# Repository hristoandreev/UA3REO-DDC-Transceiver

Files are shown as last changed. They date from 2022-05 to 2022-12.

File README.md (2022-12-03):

# Transceiver "Wolf"
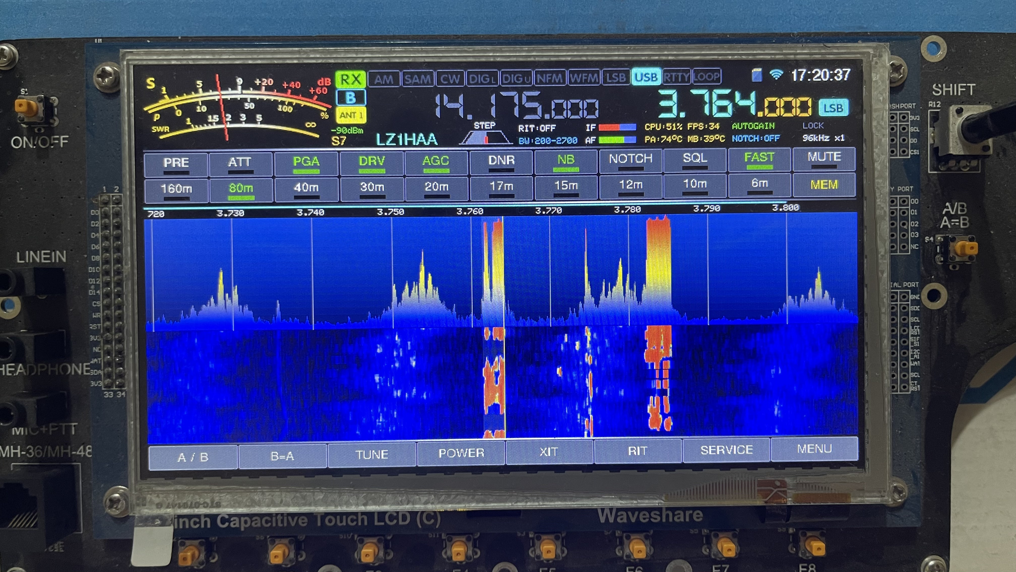
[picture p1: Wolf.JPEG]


DDC-DUC SDR Tranceiver project https://ua3reo.ru/tag/transiver-ua3reo/

* Community telegram channel: https://t.me/TRX_Wolf
* На русском https://github.com/XGudron/UA3REO-DDC-Transceiver/blob/master/README.ru-RU.md

## Principle of operation

The RF signal is digitized by a high-speed ADC chip and fed to an FPGA processor. <br>
It performs DDC / DUC conversion (digital frequency shift down or up the spectrum) - by analogy with a direct conversion receiver. <br>
The I and Q quadrature signals from the conversions are fed to the STM32 microprocessor. <br>
It filters, (de) modulates and outputs audio to an audio codec / USB. It also handles the entire user interface. <br>
When transmitting, the process occurs in the opposite order, only at the end of the chain there is a DAC, which converts the digital signal back to analog RF. <br>

## Specifications

* Receiving frequencies: 0 MHz - 750 MHz with fading each 61.44 Mhz
* Transmission frequencies: 0 MHz - 200 MHz with fading on 55, 110, 165 Mhz
* Transmission frequencies in harmonics mode (CW, FM): 360 Mhz - 480 Mhz
* TX power (QRP version): 7W+ (HF), 5W (VHF)
* TX power (QRP++ DB5AT version): 20W (HF), 7W (VHF)
* TX power (RU4PN/WF-100D version): 100W (HF), 50W+ (VHF)
* Two antenna inputs
* Modulation types (TX / RX): CW, LSB, USB, AM, FM, WFM, DIGI
* LNA, Preamplifier
* Adjustable attenuator 0-31dB
* Band pass filters
* ADC dynamic range (16 bit) ~100dB
* Supply voltage: 13.8V (overvoltage and polarity reversal protection)
* Consumption current when receiving: ~0.7А (3'2 QRP), 0.9A (7' BIG)
* Current consumption during transmission: ~2.5А+ (QRP), 15A+ (BIG)

## Transceiver Features

* Panorama (spectrum + waterfall) up to 384 kHz wide
* Panorama tweaks and themes
* Dual receiver (mixing A + B or A&B audio in stereo)
* Adjustable bandwidth: HPF from 0Hz to 2700Hz, LPF from 100Hz to 20kHz
* Integrated SWR/power meter (HF)
* Automatic and manual Notch filter
* Switchable AGC (AGC) with adjustable attack rate
* Range map, with the ability to automatically switch modes
* Digital Noise Reduction (DNR), Pulse Noise Reduction (NB)
* CAT virtual COM port (FT-450 / TS-2000 emulation, RTS - PTT, DTR - CW)
* USB operation (audio transmission, IQ, CAT, KEY, PTT)
* RDS/CW/RTTY decoder, self-control, gauss filter
* SWR Graphs
* Spectrum analyzer
* FT8 receiver/transmitter
* WSPR Beacon
* VOX
* Equalizer TX/RX, reverber
* SSB/FM Scanner mode
* Support SDHC/SDSC/SDXC memory cards up to 16Gb
* WAV files radio recording and playback, fast broadcast recorded CQ message
* AGC takes into account the characteristics of human hearing (K-Weighting)
* TCXO frequency stabilization (it is possible to use an external clock source, such as GPS)
* WiFi operation: Time synchronization, virtual CAT interface (see Scheme/WIFI-CAT-instruction.txt)
* Tangent support Yaesu MH-36 и MH-48
* Hardware self-testing
* Firmware update over USB, SD, WiFi
* And other.. (see menu)

### Sensitivity

At 10dB signal-to-noise ratio, LNA is on, ATT, LPF, BPF are off

Frequency, mHz | Sensitivity, dBm | Sensitivity
------------ | ------------- | -------------
<150	| -131	| 63.0 nV
435	| -121	| 0.2 uV

## Build

I ordered the boards in the Chinese service JLCPCB, they and their schemes are in the Scheme folder. <br>
After assembly, you need to flash FPGA and STM32 chips. <br>
If necessary, calibrate the transceiver through the appropriate menu <br>
WiFi module ESP-01 must have fresh firmware with SDK 3.0.4 and higher, and AT commands 1.7.4 and higher <br>

## Management

* **AF GAIN** - Volume
* **RIT / GAIN** - When the RIT function is active - smooth offset from the selected transceiver frequency. Inactive - IF gain control
* **ENC MAIN** - Main encoder for frequency control and menu settings
* **ENC 2** - Auxiliary encoder for menu operation. In normal mode, quickly switches the frequency, in CW fast change WPM
* **ENC 2[click]** - In CW mode, toggles between fast step and WPM selection, in other modes it opens the bandwidth properties.
* **BAND -** - Switch to the band below
* **BAND +** - Switch to higher band
* **MODE -** - Mode group switching SSB-> CW-> DIGI-> FM-> AM
* **MODE +** - Switching subgroup mod LSB-> USB, CW_L-> CW_U, DIGI_U-> DIGI_L, NFM-> WFM, AM-> IQ-> LOOP
* **FAST** - Mode of fast x10 rewinding of the frequency by the main encoder (configurable)
* **FAST [clamp]** - Frequency step settings
* **PRE** - Turn on the preamplifier (LNA)
* **PRE [clamp]** - Turn on the driver and / or amplifier ADC
* **ATT** - Turn on the attenuator
* **REC** - Save audio to SD card
* **PLAY** - Play recorded CQ-message from SD card
* **MUTE** - Mute the sound
* **MUTE [clamp]** - Scanner mode
* **AGC** - Turn on AGC (automatic gain control)
* **AGC [clamp]** - AGC settings
* **A = B** - Setting the second bank of the receiver equal to the current
* **BW** - Switch to bandwidth selection menu (LPF)
* **BW [clamp]** - Switch to bandwidth selection menu (HPF)
* **TUNE** - Turn on the carrier for tuning the antenna
* **RF POWER** - Transmitter power selection
* **RF POWER [clamp]** - Squelch setting
* **A / B** - Switches between VFO-A / VFO-B receiver settings banks
* **A / B [clamp]** - Enable automatic mode change by bendmap
* **DOUBLE** - Turn on the dual receiver
* **DOUBLE [clamp]** - Switching between the modes of the dual receiver A&B (each channel of the headphones has its own path) or A + B (mixing signals of 2 receivers)
* **DNR** - Enable digital noise reduction
* **DNR [clamp]** - Turn on the impulse noise suppressor (NB)
* **NOTCH** - Turn on the automatic Notch filter to eliminate narrowband interference
* **NOTCH [clamp]** - Turn on the manual Notch filter to eliminate narrowband interference
* **SPLIT** - Allows you to split transmission and reception to different VFO banks
* **RIT [clamp]** - Enables RIT control from the front panel
* **WPM** - Switch to key speed selection menu (WPM)
* **WPM [clamp]** - Automatic key enable
* **MENU** - Go to the menu
* **MENU [clamp]** - Enable key lock LOCK
* **MENU [at power on]** - Reset transceiver settings
* **MENU [at power on+PRE]** - Reset transceiver settings and calibration
* **RIT** - Offset of the receiving frequency relative to the current frequency (TX without offset)
* **XIT** - Offset of the transmission frequency relative to the current frequency (RX without offset)

## Settings

### TRX Settings

* **RF Power** - Transmission power,%
* **Power for each band** - Save power settings for each band individually
* **Power for each mode** - Save power settings for each mode individually
* **Channel Mode** - Channel frequency mode (for LPD/PMR and etc.)
* **Band Map** - Band Map, automatically switches mode depending on the frequency
* **AutoGainer** - Automatic ATT / PREAMP control depending on the signal level on the ADC
* **RF Filters** - Hardware filter management (LPF / HPF / BPF)
* **Two Signal tune** - Two-signal generator in TUNE mode (1 + 2kHz)
* **RIT Interval** - Offset range RIT (+ -)
* **XIT Interval** - Offset range XIT (+ -)
* **Fine RIT Tune** - Fine or coarse tuning for RIT/XIT (encoder or resistor)
* **TRX Samplerate** - Max FFT/samplerate on CW/SSB/NFM/DIGI/etc modes
* **FM Samplerate** - Max FFT/samplerate on NFM/WFM mode
* **Freq Step** - Frequency step by the main encoder
* **Freq Step FAST** - Frequency step by the main encoder in FAST mode
* **Freq Step ENC2** - Frequency tuning step by main add. encoder
* **Freq Step ENC2 FAST** - Frequency step by main add. encoder in FAST mode
* **Freq Step WFM, kHz** - Frequency step by main encoder in WFM mode
* **CW Freq Step divider** - Frequency step divider for CW mode
* **Encoder Accelerate** - Accelerate encoder on fast rates
* **Att step, dB** - Attenuator tuning step
* **Attenuation, dB** - Current attenuation
* **DEBUG Type** - Output of debug and service information to USB / UART ports
* **Auto Input Switch** - Auto input switch (PTT - mix, CAT - USB)
* **Auto Snap** - Automaticly track and snap to near signal frequency (CW mode)
* **Input Type** - Select audio input (microphone, line in, USB)
* **Callsign** - User callsign
* **Locator** - User QTH locator
* **URSI Code** - Ionogramm URSI Code https://digisonde.com/index.html#stationmap-section
* **TUNER Enabled** - Turning on the antenna tuner
* **ATU Enabled** - Turning on the automatic antenna tuner
* **ATU Ind** - Combination of tuner inductances
* **ATU Cap** - Tuner Capacitance Combination
* **ATU T** - Tuner capacitive arm position
* **Transverter XXcm** - Enable external ham band transverter support
* **Custom Transverter** - Enable external transverter on non-ham band (just offset display frequency)

### AUDIO Settings

* **Volume** - AF gain
* **Volume step** - AF gain step by ENC2 (X1, Lite)
* **IF Gain, dB** - IF gain
* **AGC Gain target, LKFS** - Maximum AGC gain (Maximum volume with AGC on)
* **Mic Gain** - Microphone gain
* **Mic Boost** - +20db hardware mic amplifier
* **DNR xxx** - Digital squelch adjustment
* **Noise Blanker** - Activating the Surge Suppressor
* **NB Threshold** - Threshold of Noise blanker
* **SSB HPF Pass** - HPF cutoff frequency when operating in SSB
* **SSB LPF Pass** - LPF cutoff frequency when operating in SSB
* **CW LPF Pass** - LPF cutoff frequency when working in CW
* **DIGI LPF Pass** - LPF cutoff frequency when working in DIGI
* **FM LPF Pass** - LPF cutoff frequency when working in FM
* **Squelch** - Enable SSB/AM/CW/FM Squelch
* **FM Squelch level** - FM squelch level
* **MIC EQ xxx** - Microphone equalizer levels
* **MIC Reverber** - Microphone reverberator level
* **MIC Noise Gate** - The level below which the microphone signal is muted, dbFS
* **RX EQ xxx** - Receiver equalizer levels
* **RX AGC Speed** - AGC (automatic signal level control) response speed for reception (more-faster)
* **RX AGC Max gain** - Limit of AGC gain, dB
* **RX AGC Hold time** - Time of AGC gain holding on signal peaks, ms
* **TX Compressor Speed** - TX compressor response speed for transmission (more-faster)
* **TX Compressor MaxGain** - Maximum comressor gain
* **Beeper** - Beep on key press
* **CTCSS Frequency** - Transmit FM CTCSS sub-tone frequency
* **SelfHear Volume** - Self Hearing (CW/DIGI) volume relative to the overall transceiver volume
* **WFM Stereo** - select WFM stereo or mono decoder
* **AGC Spectral** - Enable FFT-based AGC
* **TX CESSB** - Enable controlled-envelope single-sideband modulation
* **TX CESSB Compress, dB** - Level of signal compression in CESSB
* **VAD Threshold** - VAD voice detector threshold (noise suppressor for SSB mode and SCAN mode)
* **VOX** - TX Voice activation
* **VOX Timeout, ms** - VOX transmission delay after silence, milliseconds
* **VOX Threshold, dbFS** - VOX Threshold, dbFS

### CW Settings

* **CW Key timeout** - Time before stopping the transmission mode after releasing the key
* **CW Pitch** - Detuning the receive generator from the transmit frequency
* **CW Self Hear** - Self-control CW (key press is heard)
* **CW Keyer** - Automatic Key
* **CW Keyer WPM** - Key Speed, WPM
* **CW Gauss filter** - Gauss responce LPF filter
* **CW DotToDash Rate** - Keyer dash to dot length rate
* **CW Iambic Keyer** - Enable Iambic mode keyer
* **CW Key Invert** - Invert dash/dot on key
* **CW PTT Type** - RX/TX switch type for CW: by key or external PTT (tangent, etc.)

### SCREEN Settings

* **FFT Zoom** - FFT spectrum zooming
* **FFT Zoom CW** - FFT spectrum zooming for CW Mode
* **LCD Brightness** - Set LCD brightness (not all lcd support)
* **LCD Sleep Timeout** - Idle time before the screen brightness decreases, sec (0 - disabled)
* **Color Theme** - Select colors theme (0 - black, 1 - white, 2 - black with colored frequency)
* **Layout Theme** - Select interface theme (0 - default)
* **FFT Speed** - FFT and waterfall speed
* **FFT Automatic** - Automatic FFT scale
* **FFT Sensitivity** - Top threshold of FFT sensitivity in automatic mode (30 - scale to strongest signal)
* **FFT Manual Bottom, dBm** - Bottom FFT threshold in manual mode
* **FFT Manual Top, dBm** - Top FFT threshold in manual mode
* **FFT Height** - FFT and waterfall proportional height
* **FFT Style** - FFT style: 1(gradient), 2(fill), 3(dots), 4(contour)
* **FFT BW Style** - FFT bandwidth style: high opacity, low opacity, lines
* **FFT Color** - FFT colors: 1(blue -> yellow -> red), 2(black -> yellow -> red), 3(black -> yellow -> green), 4(black -> red), 5(black -> green), 6(black -> blue), 7(black -> white)
* **WTF Color** - Waterfall colors: 1(blue -> yellow -> red), 2(black -> yellow -> red), 3(black -> yellow -> green), 4(black -> red), 5(black -> green), 6(black -> blue), 7(black -> white)
* **FFT Freq Grid** - FFT and waterfall grids: 1(no grid), 2(fft grid), 3(fft+wtf grids), 4(wtf grid)
* **FFT dBm Grid** - FFT signal power grid
* **FFT Background** - Gradient FFT background
* **FFT Enabled** - Enable waterfall and FFT
* **WTF Moving** - Mowe waterfall with frequency changing
* **FFT Lens** - Enable FFT lens mode (magnify center of spectrum)
* **FFT Hold Peaks** - Show peaks on FFT spectrum
* **FFT 3D Mode** - Enable FFT 3D mode (0 - disabled, 1 - lines, 2 - pixels)
* **FFT Compressor** - Enable FFT peak comressor
* **FFT Averaging** - FFT burst averaging level
* **FFT Window** - Select FFT window (1-Dolph–Chebyshev 2-Blackman-Harris 3-Nutall 4-Blackman-Nutall 5-Hann 6-Hamming 7-No window)
* **FFT DXCluster** - Show DXCluster info over FFT
* **FFT DXCluster Azimuth** - Add azimuth data to DX-cluster
* **FFT DXCluster Timeout** - Timeout of DX-cluser spots in minutes
* **Show Sec VFO** - Show secondary VFO position on spectre
* **FFT Scale Type** - Y-axis style on FFT between signal amplitude and dBm to fit more dynamic range on screen (Useful when manually adjusting FFT range).

### Decoders
* **CW Decoder** - Software CW receive decoder
* **CW Decoder Threshold** - CW receive decoder sensivity
* **RDS Decoder** - Enable RDS Decoder for WFM mode
* **RTTY Speed** - Speed of RTTY data
* **RTTY Shift** - RTTY carrier shifts
* **RTTY Freq** - Central frequency of RTTY decoding
* **RTTY StopBits** - RTTY Stop bits
* **RTTY InvertBits** - RTTY invert 0 and 1 bits

### ADC / DAC Settings

* **ADC Driver** - Turn on the preamplifier-ADC driver
* **ADC Preamp** - Turn on the preamplifier built into the ADC
* **ADC Dither** - Enable ADC dither for receiving weak signals
* **ADC Randomizer** - Enables ADC digital line encryption
* **ADC Shutdown** - Turn off the ADC

### WIFI Settings

* **WIFI Enabled** - Enable WiFi module (need restart after enable)
* **WIFI Network** - WiFi hotspot selection
* **WIFI Network Pass** - Set password for WiFi hotspot
* **WIFI Timezone** - Time zone (for updating the time via the Internet)
* **WIFI CAT Server** - Server for receiving CAT commands via WIFI
* **WIFI Update ESP firmware** - Start cloud autoupdate firmware for ESP-01 (if present)

### SD Card

* **File Manager** - Show SD Card file manager, support WAV playback and deleteing files, listening and broadcasting recordings, as well as updating firmware from a memory card
* **USB SD Card Reader** - Enable USB SD Card reader
* **Export Settings** - Export settings and calibration data to SD card
* **Import Settings** - Import settings and calibration data from SD card
* **Format SD card** - Format media drive

### Calibration [appears by long pressing the MENU button in the settings menu]

* **Encoder invert** - Invert the rotation of the main encoder
* **Encoder2 invert** - Invert the rotation of the additional encoder
* **Encoder debounce** - Time of debouncing contacts of the main encoder
* **Encoder2 debounce** - Time of debouncing contacts of the additional encoder
* **Encoder slow rate** - Deceleration rate of the main encoder
* **Encoder on falling** - The encoder is triggered only when level A falls
* **Encoder acceleration** - The encoder acceleration on faster rotation speeds
* **RF-Unit Type** - RF-Unit Type (QRP / BIG)
* **Tangent Type** - Select tangent type
* **CICCOMP Shift** - Bit shift after CIC compensator
* **TX CICCOMP Shift** - Bit shift after TX CIC compensator
* **DAC Shift** - Bit shift of the output to the DAC
* **DAC Driver Mode** - DAC Driver OPA2673 bias mode (2 = 100% bias, 1 = 75% bias, 0 = 50% bias)
* **RF GAIN xxx** - Calibration of the maximum output power for each range. RF GAIN 0-100% - 50% driver bias, 101-200% - 75% driver bias, 201-300% - 100% driver bias.
* **S METER** - S-meter calibration
* **ADC OFFSET** - ADC offset calibration
* **LPF END** - LPF filter parameters
* **HPF START** - HPF filter parameters
* **BPF x** - Bandpass filter parameters
* **SWR FWD/BWD RATE** - Adjustment of the transformation ratio of the SWR meter (forward / return)
* **VCXO Correction** - Frequency adjustment of the reference oscillator
* **FAN Medium start** - Temperature of the PA for starting the fan at medium speed
* **FAN Medium stop** - Temperature of the PA for stopping the fan
* **FAN Full start** - Temperature of the PA for starting the fan at full speed
* **MAX RF Temp** - Maximum temperature of the PA before the protection operation
* **MAX SWR** - Maximum VSWR before protection operation
* **SSB Power addition** - Addition of RF power in SSB power, %
* **FM Deviation Scale** - Set TX FM Deviation Scale
* **AM Modulation Index** - Set TX AM Modulation Scale
* **MAX PWR on Meter** - Maximim RF power (for indication)
* **MAX Power in TUNE** - Maximum RF power in Tune mode
* **RTC COARSE CALIBR** - Very coarse clock crystal calibration
* **RTC FINE CALIBR** - Clock crystal calibration, one division is 0.954 ppm
* **EXT xxx** - External port control by band (EXT3, EXT2, EXT1, EXT0) - open drain
* **NOTX xxx** - Disable TX on selected bands
* **ENABLE 60m/4m/AIR/Marine Band** - Enable hidden bands
* **Transverter Offset, mHz** - Offset frequency shown on the display (for custom transverters)
* **Transverter xxx RF, mHz** - Setting the RF frequency of the transceiver to match the IF
* **Transverter xxx IF, mHz** - Setting the IF frequency of the transverter
* **OTA Update** - Enable OTA firmware update over WiFi
* **TX Start Delay** - Delay before the RF signal is applied (ms), so that the relay has time to trigger
* **LCD Rotate** - Rotate screen at 180 degrees
* **TOUCHPAD horiz flip** - Flip touchpad operation horizontally
* **ATU Averaging** - The number of steps of averaging SWR values during measurements in the operation of an automatic tuner
* **CAT Type** - Type of CAT subsystem (FT-450 / TS-2000)
* **LNA Compensation** - Compensates the S-meter value when the LNA is turned on, dBm
* **TSignal Balance** - Sets the power balance between signals in Two signal tune mode
* **Linear Pwr Control** - Sets a linear way to change the signal amplitude when adjusting the power (if disabled - logarithmic)
* **Flash GT911** - Starting the touchpad update procedure according to LCD screen resolution
* **IF Gain MIN/MAX** - IF Gain adjusting limits
* **Settings reset** - Reset all settings to defaults
* **Calibrate reset** - Reset all calibrations to defaults

### Set Clock Time

* Clock setting

### DFU Mode

* Launch STM32 USB firmware update over DFU mode

### OTA Update

* Launch FPGA/STM32 firmware update over internet

### System info

* Show info about TRX

## Services

### Spectrum Analyzer

* **Spectrum START** - Start the spectrum analyzer
* **Begin, kHz** - Starting frequency of the analyzer with a step of 1 kHz
* **End, kHz** - End frequency of the analyzer in 1kHz steps
* **Top, dBm** - Upper threshold of the graph
* **Bottom, dBm** - Lower threshold of the graph

### WSPR Beacon

* **WSPR Beacon START** - Start WSPR beacon
* **Freq offset** - Offset from center of WSPR band
* **WSPR Band xxx** - Select bands to WSPR beacon

### DX Cluster 

* Show DX Cluster info by current band (from internet)

### Propagination 

* Show propagination statistics (from internet)

### DayNight Map 

* Displaying the day/night terminator on the map (from internet)

### Ionogram 

* Displaying the ionogram for the selected URSI Code (from internet)

### SWR Analyser

* Run SWR analizer (Band SWR - on current band, HF SWR - on all HF bands, Custom SWR - in selected range)

### RDA Statistics 

* Print statistics from RDA award (from internet)

### Record CQ message

* Record a short message for quick broadcast

### FT8

* FT8 Receiver / transmitter

### Locator Info

* Calculate distance and azimuth from QTH-locator

### Callsign Info

* Show callsign data

### Self Test

* Run hardware self diagnostic

### Auto calibration

* **Calibrate SWR** - Assistant in measuring SWR and power meter
* **Calibrate Power** - Assistant in adjusting RF Power output

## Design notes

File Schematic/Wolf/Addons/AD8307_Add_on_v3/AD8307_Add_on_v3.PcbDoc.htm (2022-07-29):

Altium Reporting Options

# File in Newer Format

Date | : | 04-Dec-20
Time | : | 18:56:06
Filename | : | C:\Tisho\MyProjects\SDR_Transciever\UA3REO-DDC\Tisho_Files\Boards\AD8307_Add_on_v2\AD8307_Add_on_v2.PcbDoc

Version | Warning
Release 10 | CAUTION - New Custom Grids and Guides were introduced. Be aware that your design might contain Custom Grids and Guides that cannot be read in previous versions.
Release 10 | CAUTION - New Structured Clusters were introduced. Be aware that your design might contain Structured Clusters that cannot be read in previous versions.
Release 10 | CAUTION - New PCB 3D Movie Manager was introduced. Be aware that your design might contain 3D PCB movie that cannot be read in previous versions.
Release 10 update 1 | CAUTION - New Clearance Rule subscopes targeting differential pairs were introduced. Be aware that your design might contain Clearance Rules using those subscopes that cannot be read in previous versions.
Release 10 update 15 | CAUTION - Support of Solder Mask and Paste Mask expansions for Tracks, Arcs, Fills and Regions was introduced. Be aware that your design might contain Solder Mask and Paste Mask expansions for these types of primitives that cannot be read in the version of Altium Designer you are currently using.
Release 12 | CAUTION - Air Gap Width previously controlled by Clearance rule is now controlled by Polygon Connect Style rule's newly introduced Air Gap Width (set to default value). Suggest reviewing each Polygon Connect Style rule's Air Gap Width attribute for correctness.
Release 13 | CAUTION - Silk To Solder Mask Clearance Rules are converted to Silkscreen Over Component Pads Rules.
Release 14 | CAUTION - The Differential Pairs Routing rule added support for control of the width. Be aware that these widths must be manually entered as Width rules in this version.
Release 15 | CAUTION - Support of separate solder masks for top & bottom of pads added.
Release 15.1 | CAUTION - Support Multi-line PCB Text added.
Release 16.0 | CAUTION - Pad/Via hole size tolerance value added.
Release 17.0 | CAUTION - Component parameters added.
Release 17.0 | CAUTION - Support of backdrilling
Release 17.1 | CAUTION - Support of waived violations
Release 17.1 | CAUTION - Support of object specific keepouts

This file was generated by a later version of the software

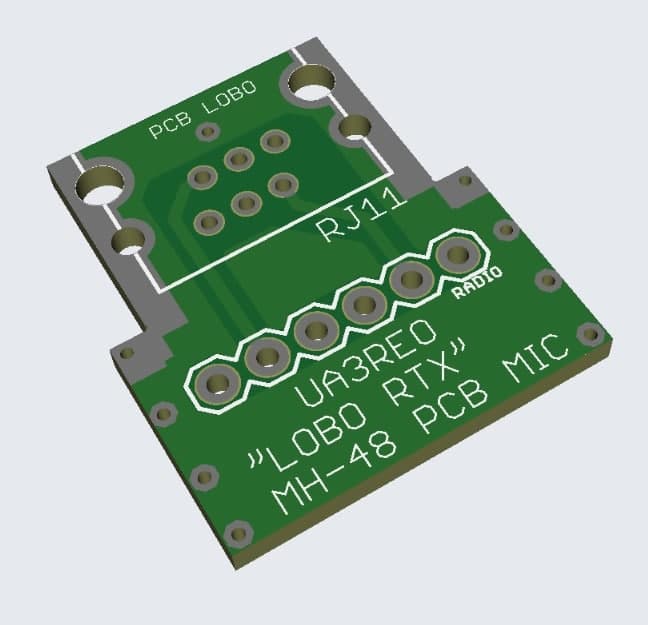
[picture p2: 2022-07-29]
Schematic/Wolf/Addons/PCB MIC MH-48/pcb2.jpg

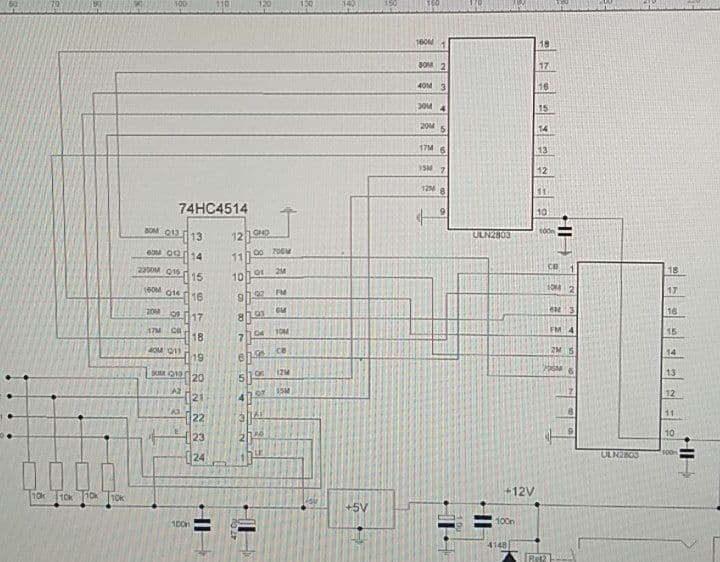
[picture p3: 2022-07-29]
Schematic/Wolf/Addons/LPF_switch.jpg

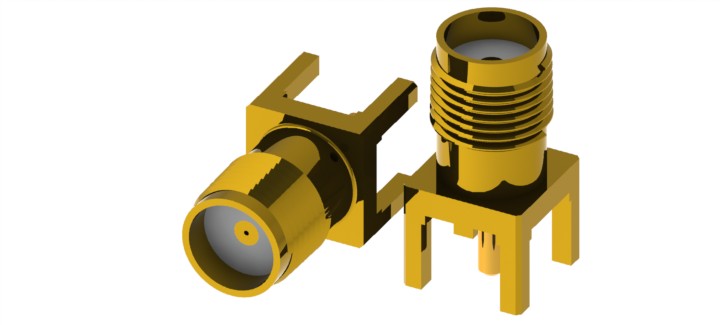
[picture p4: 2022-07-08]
Schematic/Wolf/Altium_Designer/Mod-LZ1HAA-hardware/MOTHERBOARD/3d/conn-jack-sma-str-molex-73391-0060-rf-slash-coaxial/Renderings/Molex - 73391-0060.JPG

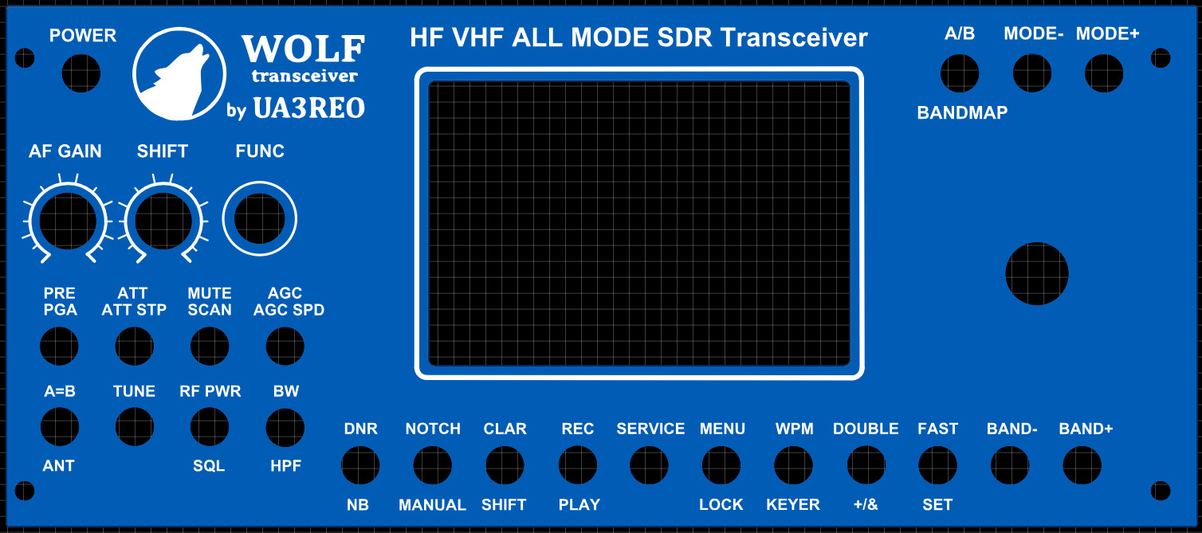
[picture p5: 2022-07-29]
Schematic/Wolf/CASE/3'2/FrontPanel/image.jpg

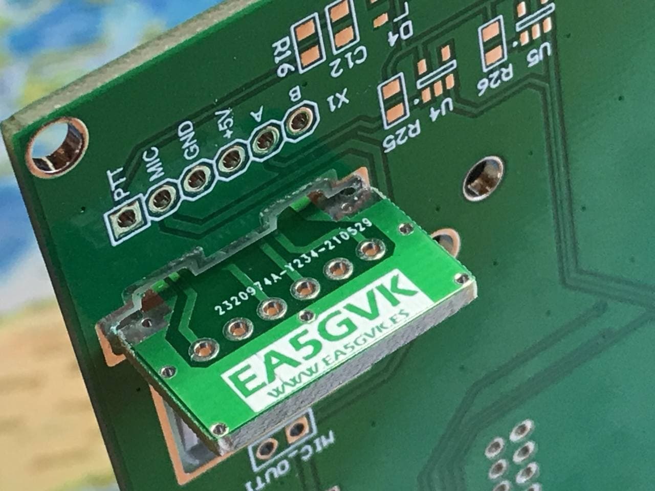
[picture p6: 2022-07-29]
Schematic/Wolf/Addons/PCB MIC MH-48/pcb5.jpg

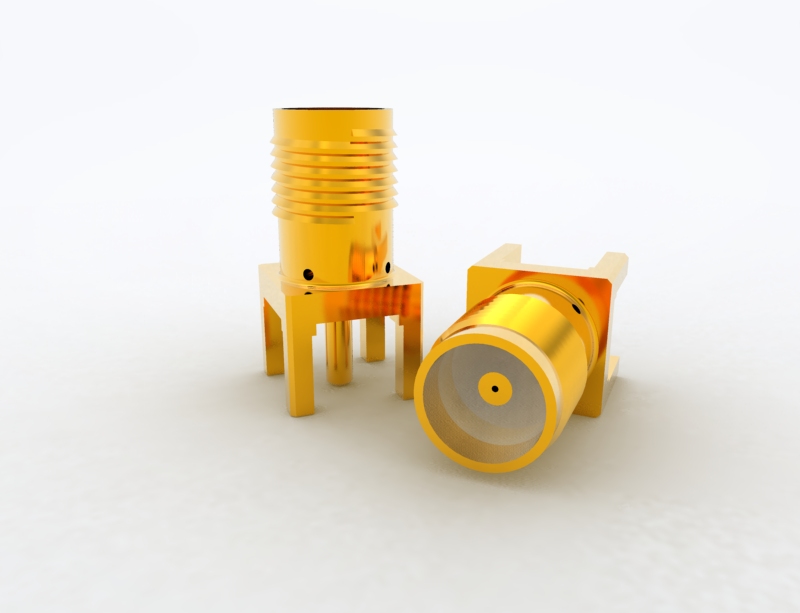
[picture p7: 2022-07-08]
Schematic/Wolf/Altium_Designer/Mod-LZ1HAA-hardware/MOTHERBOARD/3d/conn-jack-sma-str-molex-73391-0060-rf-slash-coaxial/Renderings/untitled.32220110907-27564-a875go.jpg

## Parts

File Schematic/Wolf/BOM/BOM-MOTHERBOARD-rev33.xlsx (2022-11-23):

Comment | Description | Designator | Footprint | LibRef | Quantity | LCSC Part #
JX2 | JX2 | 13.8V + | JX2 | JX2 | 1
51022-0300_1 | 51022-0300 | A_OUT, MIC_IN2 | 51022-0200 - duplicate | 51022-0300_1 | 2
CR1220 + | BR1632A/FA | B1 | KLS5-CR1220-01 | BR1632A/FA | 1
 | 2 Pin | BOOT | 51022-0200 | 51022-0200 | 1
4.7uF 16V | CAPAE_6.6x6.6h5.4 | C1 | SMC | CAPAE_6.6x6.6h5.4 | 1
22uF 10V | CAPAE_4.3x4.3h5.4 | C2, C125, C126 | CAPAE_4.3x4.3h5.4 | CAPAE_4.3x4.3h5.4 | 3
100n | CAP_0805 | C3, C4, C5, C6, C9, C16, C19, C21, C23, C31, C44, C45, C46, C47, C48, C49, C51, C53, C56, C57, C58, C59, C61, C62, C65, C67, C69, C70, C71, C72, C73, C74, C76, C78, C79, C81, C82, C83, C84, C86, C87, C88, C89, C91, C93, C94, C95, C96, C97, C98, C99, C100, C107, C109, C110, C112, C113, C114, C115, C117, C118, C120, C123, C124, C135 | CAP_0805 | CAP_0805 | 65
1uF | CAP_0805 | C7, C11, C12, C13, C14, C15, C35, C92, C119, C121, C122, C1003, C1004 | CAP_0805 | CAP_0805 | 13
10uF 10V | CAPAE_4.3x4.3h5.4 | C8, C20, C22, C24, C32, C54, C60, C75, C77, C80, C85, C1002 | CAPAE_4.3x4.3h5.4 | CAPAE_4.3x4.3h5.4 | 12
470p | CAP_0805 | C10, C90, C104, C116 | CAP_0805 | CAP_0805 | 4
10uF 10V | CAP_0805 | C17 | CAP_0805 | CAP_0805 | 1
1uF 10V | CAPAE_4.3x4.3h5.4 | C25, C26, C29 | CAPAE_4.3x4.3h5.4 | CAPAE_4.3x4.3h5.4 | 3
220p | CAP_0805 | C27, C28, C30 | CAP_0805 | CAP_0805 | 3
220uF 10V | CAPAE_4.3x4.3h5.4 | C33, C34 | EEEFC_size� | CAPAE_4.3x4.3h5.4 | 2
NONE | CAP_0805 | C36 | CAP_0805 | CAP_0805 | 1
2.7n | CAP_0805 | C37 | CAP_0805 | CAP_0805 | 1
6pF | CAP_0805 | C38, C39 | CAP_0805 | CAP_0805 | 2
10uF | CAP_0805 | C40, C41, C50, C52, C64, C66, C68 | CAP_0805 | CAP_0805 | 7
22p | CAP_0805 | C42, C43 | CAP_0805 | CAP_0805 | 2
7.5p | CAP_0805 | C55 | CAP_0805 | CAP_0805 | 1
10n | CAP_0805 | C63, C137 | CAP_0805 | CAP_0805 | 2
10uF 20V | CAPAE_4.3x4.3h5.4 | C101, C108 | CAPAE_4.3x4.3h5.4 | CAPAE_4.3x4.3h5.4 | 2
1uF | CAP_1206 | C102, C103 | CAP_1206 | CAP_1206 | 2
680p | CAP_1206 | C105, C106 | CAP_1206 | CAP_1206 | 2
10p | CAP_0805 | C127 | CAP_0805 | CAP_0805 | 1
8.2n | CAP_0805 | C136 | CAP_0805 | CAP_0805 | 1
1n | CAP_0805 | C1001 | CAP_0805 | CAP_0805 | 1
SMAJ5.0A-TR | Diode | D1, D3, D29, D30, D31, D34, D35, D36, D37, D38, D39, D40 | SMBJ36CATR | SMLVT3V3 | 12 | [NoParam], test
SS34 | Schottky Diode | D1001 | SMB | D Schottky | 1
Diode | Default Diode | D1002 | C1206 | Diode | 1
SJ1-3525NG | SJ1-3525NG | J1, J2, J3, J5 | SJ1-3525NG | SJ1-3523N | 4
RF-UNIT | 2*5 Pin | J4 | 90131-0126 | 90131-0126 | 1
FPC-45P-0.5mm | Connector | J6 | FH12S45S05SH60 | FH12S-45S-0.5SH_55_ | 1
FAN | 51022-0200 | J7 | 51022-0200 | 51022-0200 | 1
USB | 2-1734035-3 | J8 | 2-1734035-3 | 2-1734035-3 | 1
DAC_OUT | SMA | J9 | 31-5431 | 31-5431 | 1
ADC | SMA | J10 | 31-5431 | 31-5431 | 1
 | 2*5 Pin | JTAG_FPGA, JTAG_STM32 | IDC10 | IDC10 | 2
3.3uH | IND_1812 | L1, L9 | IND_1812 | IND_1812 | 2
BLM21 | BLM21 | L3, L8 | CAP_0805 | IND_FERRITE_BEAD | 2
22uH | IND_1206 | L7 | IND_7x7 | IND_1206 | 1
10uH | Inductor | L37, L1001 | IND_7x7 | IND_FERRITE_CORE | 2
10uH | IND_1812 | L1002 | IND_1812 | IND_1812 | 1
PTT_IN | 51022-0200 | PTT_IN | 51022-0200 | 51022-0200 | 1
2SC5103TLP | Transistor BJT NPN | Q1 | 2SC5103TLQ | 2SC5103TLP | 1
7.5k | RES_0805 | R1 | RES_0805 | RES_0805 | 1
39k | RES_0805 | R2 | RES_0805 | RES_0805 | 1
0/NONE | By used crystal | R3 | RES_0805 | RES_0805 | 1
NONE / 0 | RES_0805 | R4, R1001, R1002 | RES_0805 | RES_0805 | 3
5.6k | RES_0805 | R5, R6, R7, R9, R51 | RES_0805 | RES_0805 | 5
30k | RES_0805 | R8, R55 | RES_0805 | RES_0805 | 2
10k | RES_0805 | R10, R13, R24, R27, R28, R30, R31, R32, R33, R36, R37, R38, R39, R46, R47, R48, R56, R57 | RES_0805 | RES_0805 | 18
680 | RES_0805 | R11 | RES_0805 | RES_0805 | 1
47k | RES_0805 | R12, R14, R15, R45 | RES_0805 | RES_0805 | 4
1.5k | RES_0805 | R16, R66 | RES_0805 | RES_0805 | 2
1k | RES_0805 | R17, R18, R19, R25, R26, R49, R50, R52 | RES_0805 | RES_0805 | 8
130 | RES_0805 | R20, R21 | RES_0805 | RES_0805 | 2
82 | RES_0805 | R22, R23 | RES_0805 | RES_0805 | 2
1m | RES_0805 | R29 | RES_0805 | RES_0805 | 1
100 | RES_0805 | R34, R35 | RES_0805 | RES_0805 | 2
22 | RES_0805 | R40, R53, R54, R58 | RES_0805 | RES_0805 | 4
24 | RES_0805 | R41, R42, R43, R64, R65 | RES_0805 | RES_0805 | 5
56 | RES_0805 | R44, R67 | RES_0805 | RES_0805 | 2
 | RES_0805 | R59, R60 | RES_0805 | RES_0805 | 2
330 | RES_0805 | R61 | RES_0805 | RES_0805 | 1
5.6 | RES_1206 | R62, R63 | RES_1206 | RES_1206 | 2
10 | RES_0603 | R68, R69 | RES_0603 | RES_0603 | 2
Thermistor 20k | Thermistor | R70 | MF52A103F3950A1 | MF52A103F3950_A1_ | 1
ADJ-5k | 306J | R71 | 306J | 306J | 1
0 | RES_0805 | R1003 | RES_0805 | RES_0805 | 1
1:1+1 | Transformer | T3 | TRANSF_ACORE2 | TRANSF_ACORE2 | 1
1:4 ADT4-6T | Transformer | T4 | TRANSF_ACORE2 | TRANSF_ACORE2 | 1
1:1 | Transformer | T6 | TRANSF_ACORE | TRANSF_ACORE | 1
PAM8406 | PAM8406 | U1 | PAM8403 | PAM8406 | 1
LD3985 | LD3985 | U2 | LD3985 | LD3985 | 1
ST1S10 | ST1S10 | U3 | ST1S10 | ST1S10 | 1
WM8731 | WM8731 | U4 | WM8731 | WM8731 | 1
STM32H743VIT6-rev.V | STM32H743VIT6 | U5 | STM32H743VIT6 | STM32H743VIT6 | 1
LM1084IS-3.3 | LM1084IS-3.3 | U6 | LM1085-3.3 | LM1085-3.3 | 1
W25Q16 | W25Q16 | U7 | W25Q16 | W25Q16 | 1
DAC5674 | Integrated Circuit | U8 | QFP50P900X900X100-49N | DAC5674IPHP | 1
25P80 | 25P80 | U9 | 25P80 | 25P80 | 1
EP4CE22E22C8N | EP4CE22E22C8N | U10 | QFP144-20-2222A | EP4CE22E22C8N | 1
1117DT-2.5 | LD1117DT-2.5 DPAK | U11 | TO228P991X238-3N | LM1117DT-ADJ | 1
1117DT-1.2 | LD1117DT-1.2 DPAK | U12 | TO228P991X238-3N | LM1117DT-ADJ | 1
1117-3.3 | LT1117CST-3.3 | U13 | LT1117CST-3.3 | LT1117CST-3.3 | 1
1117-1.8 | LT1117CST-1.8 | U14 | LT1117CST-3.3 | LT1117CST-3.3 | 1
SPEAKER | 4 pins conn | U15 | speaker conn | speaker conn | 1
LTC2208CUP | LTC2208CUP | U16 | LTC2208CUP | LTC2208CUP | 1
LTC6400IUD | Single Channel, Low Noise, Low Distortion Differential ADC Driver for 300 MHz IF, 1800 MHz Typical GBW, 4500 V/us Typical SR, 2.85 to 3.5 V, 16-Pin QFN (UD-16), Industrial, Pb-Free | U17 | LT-UD-16_N | CMP-0359-03855-2 | 1
1117DT-3.3 | LD1117DT33 DPAK | U18 | TO228P991X238-3N | LM1117DT-ADJ | 1
ADUM4160 | Integrated Circuit | U19 | SOIC127P1032X265-16N | ADUM4160BRWZ | 1
OPA2673 | Integrated Circuit | U20 | QFN65P400X400X100-17N-D | OPA2673IRGVT | 1
LM2940S-12/NOPB | 1-A, 26-V, high-PSRR, low-dropout voltage regulator | U21 | TO254P1524X483-4N | LM2940S-12/NOPB | 1
122.88Mhz | NV7050SA VG-4513CA-122.8800M-GGCT3 | XG1 | NV7050SA | NV7050SA | 1
12.288Mhz TCXO 3.3v TTL/CMOS (set other freq in fpga code) | Crystal or Oscillator | XG2 | 581L200X2ITT | 581L200X2ITT | 1
ABS25-32.768KHZ-6-T | Crystal or Oscillator | Y1 | ABS25 | ABS25-32.768KHZ-6-T | 1
8mhz | ECS-200-20-1 | Y2 | ECS-200-20-1 | ECS-200-20-1 | 1

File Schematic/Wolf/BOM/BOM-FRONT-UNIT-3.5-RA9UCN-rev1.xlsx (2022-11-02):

Comment | Description | Designator | Footprint | LibRef | Quantity
JX2 | JX2 | ACCUM, IN, MOTHERBOARD, RF-UNIT | JX2 | JX2 | 4
100n | CAP_0805 | C1, C2, C9, C14, C15, C16, C17, C18, C19, C20, C21, C22, C23, C24, C25, C26 | CAP_0805 | CAP_0805 | 16
1uF | CAP_1206 | C3 | CAP_1206 | CAP_1206 | 1
100n | CAP_1206 | C4 | CAP_1206 | CAP_1206 | 1
1n | CAP_1206 | C5 | CAP_1206 | CAP_1206 | 1
1000uF | CAP250RP | C6 | CAP250RP | CAP250RP | 1
470pF | CAP_1206 | C7 | CAP_1206 | CAP_1206 | 1
120pF | CAP_1206 | C8 | CAP_1206 | CAP_1206 | 1
22uF | EEEFC_sizeB | C10 | EEEFC_sizeB | EEEFC_sizeB | 1
8.2n | CAP_1206 | C11 | CAPC2013X94X50LL20T25 | CMP-2007-04444-1 | 1
10n | CAP_0805 | C12, C13 | CAP_0805 | CAP_0805 | 2
470uF | 10x7.7, 8.7, 10, 10.5, 12.5 | C1001, C1002 | SMD-G-10X10.2 | _SMD-G-10 | 2
1n4148w | Diode | D25, D27 | SOD3716X135N | 1n4148w | 2
SM6T15A | Diode | D28 | SMBJ36CATR | SM6T15A | 1
PEC12 | PEC12 | ENC2 | PEC12 | PEC12 | 1
OPTICAL ENCODER | OPTICAL ENCODER | ENCODER_MAIN | 644456-4 | 644456-4 | 1
ESP-01 ESP8266 | ESP-01 ESP8266 | ESP-8266 | ESP-01 ESP8266 | ESP-01 ESP8266 | 1
RUEF400 | Fuse | F1 | RUEF400 | RUEF400 | 1
MF-MSMF110_16-2 | Fuse | F2 | FUSC4632X85N | MF-MSMF110_16-2 | 1
PJ-050B | PJ-050B | IN_2 | PJ-050B | PJ-050B | 1
DM3AT-SF-PEJM5 | Connector | J2 | DM3ATSFPEJM5 | DM3AT-SF-PEJM5 | 1
FPC-45P-0.5mm | Connector | J7 | FH12S45S05SH60 | FH12S-45S-0.5SH_55_ | 1
 | LCD-MODULE_3'2_480�320 | LCD-MODULE | LCD-MODULE-3.2-480-320 | LCD-MODULE_3'2_480�320 | 1
ESP-07S |  | M1 | ESP-07S | ESP-07S | 1
IRFR9024NPBF | IRFR9024NPBF | Q1 | ONSC-DPAK-3-369C-01_V | CMP-1058-00387-1 | 1
BSS123 | N-Channel Logic Level Enhancement Mode Field Effect Transistor, 1.7 V, -55 to 150 degC, 3-Pin SOT-23, RoHS, Tape and Reel | Q2 | FAIR-SOT23-3_V | CMP-2000-04934-1 | 1
ptv09a-4225f-b102 | Adjustable Resistor PTV09 | R1, R2 | PTV09 | PTV09 | 2
4.7k | RES_0805 | R3, R4, R5, R6, R7, R8, R9, R10, R11, R12, R13, R14, R15, R16, R17, R18, R19, R29, R30, R31, R32, R33, R34, R35, R36 | RES_0805 | RES_0805 | 25
3.3k | RES_0805 | R20, R21, R22 | RES_0805 | RES_0805 | 3
0 | RES_0805 | R23, R24, R25 | RES_0805 | RES_0805 | 3
30k | RES_0805 | R26, R27, R28 | RESC2013X60X40NL20T25 | CMP-2001-00626-1 | 3
PTS645SK50LFS | PTS645SK50LFS | S1, S2, S3, S4, S5, S6, S7, S8, S9, S10, S11, S12, S13, S14, S15, S16, S17, S18, S19, S20, S21, S22, S23 | PTS645SK50LFS | PTS645SK50LFS | 23
BNX016-01 | BNX016-01 | T1 | TRANSF_ICORE | TRANSF_ICORE | 1
MCP3008-I/SL | MCP3008-I/SL | U1, U2, U3 | MCP3008-I/SL | MCP3008-I/SL | 3

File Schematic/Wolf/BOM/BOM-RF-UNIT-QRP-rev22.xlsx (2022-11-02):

Comment | Description | Designator | Footprint | Quantity
0 | RES_0805 | R49, R50 | RES_0805 | 2
0 | RES_1206 | R34, R38 | RES_1206 | 2
1:1 | 1:1 | T5 | TRANSF_ACORE2 | 1
1k | RES_0805 | R28, R29, R35, R42, R43 | RES_0805 | 5
1k | RES_0805 | R31, R65, R71, R72, R73, R74, R75, R76, R77, R78, R79, R80, R81, R82, R83, R84, R85 | RESC2013X60X40NL20T25 | 17
1n | CAP_0805 | C47, C112, C115, C120 | CAP_0805 | 4
1n | CAP_0805 | C122 | 6-0805_M | 1
1n8 | CAP_1206 | C105 | CAP_1206 | 1
1n8 100V | CAP_1206 | C92, C94 | CAP_1206 | 2
1N4148 | 1N4148 | D4 | 1N4148 | 1
1uF | CAP_0805 | C126, C128 | CAP_0805 | 2
1uH | IND_0805 | L17 | IND_0805 | 1
1.1n | CAP_0805 | C72, C74 | CAP_0805 | 2
1.2k | RES_0805 | R53 | RES_0805 | 1
1.2n | CAP_0805 | C62 | CAP_0805 | 1
1.3n | CAP_0805 | C61 | CAP_0805 | 1
1.3uH | IND_0805 | L18 | IND_0805 | 1
1.5uH | IND_0805 | L14, L25 | IND_0805 | 2
1.6uH | IND_0805 | L26 | IND_0805 | 1
2k | RES_0805 | R13 | RESC2013X60X40NL20T25 | 1
2uH | IND_0805 | L19, L22, L39, L47 | IND_0805 | 4
2.2uF | CAP_1206 | C95 | CAP_1206 | 1
2.2uF 100V | CAP_1206 | C91, C93 | CAP_1206 | 2
2.2uH | IND_0805 | L30 | IND_0805 | 1
2.4uH | IND_0805 | L31 | IND_0805 | 1
2.7uH | IND_0805 | L23, L27 | IND_0805 | 2
3n | CAP_0805 | C76 | CAP_0805 | 1
3.3n | CAP_0805 | C75 | CAP_0805 | 1
3.6uH | IND_0805 | L28 | IND_0805 | 1
4.3uH | IND_0805 | L24 | IND_0805 | 1
6.2uH | IND_0805 | L29 | IND_0805 | 1
6.5-30p | TZC3P300A110 | C86, C87 | 5025[2010] | 2
6.8uH | IND_0805 | L32 | IND_0805 | 1
8p | CAP_0805 | C16, C19 | CAP_0805 | 2
8T M2000HM 10*6*5 | Transformer | T1 | Rutrof 2 | 1
8T M2000HM 10*6*5 | Transformer | T3 | Rutrof | 1
8.2nH | IND_0805 | L34, L35, L36 | IND_0805 | 3
9.1uH | IND_0805 | L33 | IND_0805 | 1
10k | RES_0805 | R37 | RESC2013X60X40NL20T25 | 1
10k | RES_1206 | R1 | RES_1206 | 1
10n | CAP_0805 | C121 | 6-0805_M | 1
10uF 25V | CAPAE_5.3x5.3h6.1 | C129 | CAPAE_5.3x5.3h6.1 | 1
10uH | Inductor | L37, L38, L43 | IND_FERRITE_CORE | 3
11p | CAP_0805 | C103 | CAP_0805 | 1
15p | CAP_0805 | C18 | CAP_0805 | 1
15pF | CAP_0805 | C17 | CAP_0805 | 1
18 | RES_1206 | R39 | RES_1206 | 1
20p | CAP_1206 | C123, C125 | CAP_1206 | 2
22nH | IND_0805 | L48, L49, L51 | IND_0805 | 3
27nH | IND_0805 | L50 | IND_0805 | 1
27p | CAP_0805 | C55, C104 | CAP_0805 | 2
30k | RES_0805 | R33, R45, R70 | RESC2013X60X40NL20T25 | 3
30k | RES_0805 | R41, R57 | RES_0805 | 2
33p | CAP_0805 | C6 | CAP_0805 | 1
36p | CAP_1206 | C124 | CAP_1206 | 1
43p | CAP_0805 | C101 | CAP_0805 | 1
47p | CAP_0805 | C5, C13, C110 | CAP_0805 | 3
47uF 25V | CAPAE_6.6x6.6h5.4 | C119 | CAPAE_6.6x6.6h5.4 | 1
50 | RES_1206 | R55, R56 | RES_1206 | 2
56 | RES_0805 | R27, R44 | RES_0805 | 2
56p | CAP_0805 | C107 | CAP_0805 | 1
62p | CAP_0805 | C12, C102 | CAP_0805 | 2
68nH | Inductor | L44, L45 | IND_FERRITE_CORE_1 | 2
68p | CAP_0805 | C108 | CAP_0805 | 1
82p | CAP_0805 | C11 | CAP_0805 | 1
91nH | IND_0805 | L2, L41 | IND_0805 | 2
100n | CAP_0805 | C1, C2, C3, C4, C38, C80, C113, C114, C116, C117, C118, C130, C133, C134, C135, C136, C137, C139, C140, C141, C142 | CAP_0805 | 21
100n | CAP_0805 | C131 | 6-0805_M | 1
100n | CAP_1206 | C81, C111 | CAP_1206 | 2
100nH | IND_0805 | L3, L40 | IND_0805 | 2
100p | CAP_0805 | C9 | CAP_0805 | 1
100p | CAP_0805 | C127, C132 | 6-0805_M | 2
110p | CAP_0805 | C8, C10, C22, C89 | CAP_0805 | 4
120 | RES_0805 | R32, R46 | RES_0805 | 2
120p | CAP_0805 | C15, C21 | CAP_0805 | 2
130p | CAP_0805 | C14, C88, C90 | CAP_0805 | 3
160nH | IND_0805 | L5, L42 | IND_0805 | 2
160p | CAP_0805 | C20 | CAP_0805 | 1
180nH | IND_0805 | L6, L53, L54 | IND_0805 | 3
180p | CAP_0805 | C33, C34 | CAP_0805 | 2
200 | RES_0805 | R52 | RES_0805 | 1
220nH | IND_1206 | L46 | IND_1206 | 1
240p | CAP_0805 | C32 | CAP_0805 | 1
270nH | IND_0805 | L1, L7 | IND_0805 | 2
270p | CAP_0805 | C24, C45 | CAP_0805 | 2
300 | RES_1206 | R47, R48 | RES_1206 | 2
300p | CAP_0805 | C23 | CAP_0805 | 1
330nH | IND_0805 | L10, L52, L55 | IND_0805 | 3
330p | CAP_0805 | C44 | CAP_0805 | 1
360nH | IND_0805 | L8, L11 | IND_0805 | 2
360p | CAP_0805 | C46 | CAP_0805 | 1
470nH | IND_0805 | L4, L15 | IND_0805 | 2
470p | CAP_0805 | C36, C60 | CAP_0805 | 2
510 | RES_0805 | R36, R54 | RES_0805 | 2
510p | CAP_0805 | C35 | CAP_0805 | 1
560 | RES_0805 | R3, R7, R8, R9, R10, R11, R12 | RES_0805 | 7
560nH | IND_0805 | L16 | IND_0805 | 1
560p | CAP_0805 | C59 | CAP_0805 | 1
620nH | IND_0805 | L12 | IND_0805 | 1
680nH | IND_0805 | L20 | IND_0805 | 1
750nH | IND_0805 | L21 | IND_0805 | 1
750p | CAP_0805 | C58 | CAP_0805 | 1
820nH | IND_0805 | L13 | IND_0805 | 1
820p | CAP_0805 | C73 | CAP_0805 | 1
910nH | IND_0805 | L9 | IND_0805 | 1
910p | CAP_0805 | C48 | CAP_0805 | 1
2027-07-SM-RPLF | 2027-07-SM-RPLF | U18 | 200307SMRPLF | 1
51022-0200 | 51022-0200 | AMP1_PWR, AMP2_PWR, FAN_OUT | 51022-0200 | 3
ADC | SMA | J2 | 31-5431 | 1
ADG904BRUZ-R | Integrated Circuit | U4, U15, U16, U17 | SOP65P640X120-20N | 4
ADG918BRMZ | Integrated Circuit | U8, U10, U11, U12, U13, U14 | SOP65P490X110-8N | 6
ADJ-1k | 306J | R30, R40 | 306J | 2
ANT1 | SMA | J1 | 31-5431 | 1
ANT2 | SMA | J5 | 31-5431 | 1
Axicom V23079 | Axicom V23079 | K1 | V23079 | 1
BAT46JFILM | Diode | D1, D3 | SOD2513X117N | 2
BAV99 | BAV99 | D24 | SOT23 | 1
BSS123 | N-Channel Logic Level Enhancement Mode Field Effect Transistor, 1.7 V, -55 to 150 degC, 3-Pin SOT-23, RoHS, Tape and Reel | Q6, Q7, Q8 | FAIR-SOT23-3_V | 3
DAC | SMA | J9 | 31-5431 | 1
EXTERNAL | 2*5 PIN | J3 | 90131-0126 | 1
IRLML9301 | MOSFET | Q2, Q5 | SOT23 | 2
JX2 | JX2 | J8 | 1986717-2 | 1
KTY81/120 | Integrated Circuit | R14 | TO254P420X460X770-2P | 1
LM1117DT-5.0 | Integrated Circuit | U6 | TO228P991X238-3N | 1
LT1117IST-ADJ | LT1117IST-ADJ | U5 | LT1117IST-ADJ | 1
MOTHERBOARD | 2*5 PIN | J4 | 90131-0126 | 1
PE4312 | Integrated Circuit | U9 | QFN50P400X400X90-21N | 1
PGA-103+ / SPF5189Z | PGA-103+ / SPF5189Z | Q4 | SOT89 | 1
RD07MVS1 | RD07MVS1 | Q1, Q3 | RD07MVS1 | 2
SMAJ5.0A-TR | Diode | D2 | SMBJ36CATR | 1
SN74HC595D | 8-Bit Shift Registers With 3-State Output Registers, D0016A, TUBE | U1, U3, U7 | D0016A_L | 3
SS14 | SS14 | D18, D23 | SS14 | 2
SWR_TANDEM_MATCH | SWR_TANDEM_MATCH | TSWR | SWR_TANDEM_MATCH | 1
TRANSF_OUT | TRANSF_OUT | T4 | TRANSF_OUT | 1
ULN2003BDR | ULN2003BDR | U2 | ULN2003BDR | 1

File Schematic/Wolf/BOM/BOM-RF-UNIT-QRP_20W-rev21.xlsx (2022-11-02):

Comment | Description | Designator | Footprint | Quantity
0 | RES_0805 | R49, R50 | RES_0805 | 2
0 | RES_1206 | R34, R38 | RES_1206 | 2
1:1 | 1:1 | T5 | TRANSF_ACORE2 | 1
1k | RES_0805 | R28, R29, R35, R42, R43 | RES_0805 | 5
1k | RES_0805 | R31, R65, R71, R72, R73, R74, R75, R76, R77, R78, R79, R80, R81, R82, R83, R84, R85 | RESC2013X60X40NL20T25 | 17
1n | CAP_0805 | C47, C48, C72, C112, C115, C120 | CAP_0805 | 6
1n | CAP_0805 | C122 | 6-0805_M | 1
1n8 | CAP_1206 | C105 | CAP_1206 | 1
1n8 100V | CAP_1206 | C92, C94 | CAP_1206 | 2
1N4148 | 1N4148 | D4 | 1N4148 | 1
1uF | CAP_0805 | C126, C128 | CAP_0805 | 2
1uH | IND_0805 | L9, L17 | IND_0805 | 2
1.2k | RES_0805 | R53 | RES_0805 | 1
1.2n | CAP_0805 | C62, C74 | CAP_0805 | 2
1.5n | CAP_0805 | C61 | CAP_0805 | 1
1.5uH | IND_0805 | L14, L18, L25 | IND_0805 | 3
1.8uH | IND_0805 | L19, L26 | IND_0805 | 2
2k | RES_0805 | R13 | RESC2013X60X40NL20T25 | 1
2uH | IND_0805 | L39, L47 | IND_0805 | 2
2.2uF | CAP_1206 | C95 | CAP_1206 | 1
2.2uF 100V | CAP_1206 | C91, C93 | CAP_1206 | 2
2.2uH | IND_0805 | L22, L30, L31 | IND_0805 | 3
2.7uH | IND_0805 | L23, L27 | IND_0805 | 2
3.3n | CAP_0805 | C75, C76 | CAP_0805 | 2
3.3uH | IND_0805 | L28 | IND_0805 | 1
4.7uH | IND_0805 | L24 | IND_0805 | 1
5.6uH | IND_0805 | L29 | IND_0805 | 1
6.5-30p | TZC3P300A110 | C86, C87 | 5025[2010] | 2
6.8uH | IND_0805 | L32 | IND_0805 | 1
8p | CAP_0805 | C16, C19 | CAP_0805 | 2
8T M2000HM 10*6*5 | Transformer | T1 | Rutrof 2 | 1
8T M2000HM 10*6*5 | Transformer | T3 | Rutrof | 1
8.2nH | IND_0805 | L34, L35, L36 | IND_0805 | 3
8.2uH | IND_0805 | L33 | IND_0805 | 1
10k | RES_0805 | R37 | RESC2013X60X40NL20T25 | 1
10k | RES_1206 | R1 | RES_1206 | 1
10n | CAP_0805 | C121 | 6-0805_M | 1
10uF 25V | CAPAE_5.3x5.3h6.1 | C129 | CAPAE_5.3x5.3h6.1 | 1
10uH | Inductor | L37, L38, L43 | IND_FERRITE_CORE | 3
12p | CAP_0805 | C103 | CAP_0805 | 1
15p | CAP_0805 | C18 | CAP_0805 | 1
15pF | CAP_0805 | C17 | CAP_0805 | 1
18 | RES_1206 | R39 | RES_1206 | 1
18p | CAP_1206 | C123, C125 | CAP_1206 | 2
22nH | IND_0805 | L48, L49, L51 | IND_0805 | 3
27nH | IND_0805 | L50 | IND_0805 | 1
27p | CAP_0805 | C55, C104 | CAP_0805 | 2
30k | RES_0805 | R33, R45, R70 | RESC2013X60X40NL20T25 | 3
30k | RES_0805 | R41, R57 | RES_0805 | 2
33p | CAP_0805 | C6 | CAP_0805 | 1
33p | CAP_1206 | C124 | CAP_1206 | 1
39p | CAP_0805 | C7, C101 | CAP_0805 | 2
47p | CAP_0805 | C5, C13, C110 | CAP_0805 | 3
47uF 25V | CAPAE_6.6x6.6h5.4 | C119 | CAPAE_6.6x6.6h5.4 | 1
50 | RES_1206 | R55, R56 | RES_1206 | 2
51p | CAP_0805 | C107 | CAP_0805 | 1
56 | RES_0805 | R27, R44 | RES_0805 | 2
61p | CAP_0805 | C12 | CAP_0805 | 1
68nH | Inductor | L44, L45 | IND_FERRITE_CORE_1 | 2
68p | CAP_0805 | C102, C108 | CAP_0805 | 2
75p | CAP_0805 | C11 | CAP_0805 | 1
82nH | IND_0805 | L2, L41 | IND_0805 | 2
100n | CAP_0805 | C1, C2, C3, C4, C38, C80, C113, C114, C116, C117, C118, C130, C133, C134, C135, C136, C137, C139, C140, C141, C142 | CAP_0805 | 21
100n | CAP_0805 | C131 | 6-0805_M | 1
100n | CAP_1206 | C81, C111 | CAP_1206 | 2
100nH | IND_0805 | L3, L40 | IND_0805 | 2
100p | CAP_0805 | C9, C14, C22, C89 | CAP_0805 | 4
100p | CAP_0805 | C127, C132 | 6-0805_M | 2
110p | CAP_0805 | C8, C10 | CAP_0805 | 2
120p | CAP_0805 | C15, C21, C88, C90 | CAP_0805 | 4
150nH | IND_0805 | L5, L6, L42 | IND_0805 | 3
150p | CAP_0805 | C20 | CAP_0805 | 1
180nH | IND_0805 | L53, L54 | IND_0805 | 2
180p | CAP_0805 | C33, C34 | CAP_0805 | 2
200 | RES_0805 | R52 | RES_0805 | 1
220 | RES_0805 | R32, R46 | RES_0805 | 2
220nH | IND_1206 | L46 | IND_1206 | 1
270nH | IND_0805 | L1, L7 | IND_0805 | 2
270p | CAP_0805 | C24, C32, C45 | CAP_0805 | 3
300 | RES_1206 | R47, R48 | RES_1206 | 2
330nH | IND_0805 | L8, L10, L11, L52, L55 | IND_0805 | 5
330p | CAP_0805 | C23, C44, C46 | CAP_0805 | 3
470nH | IND_0805 | L4, L15 | IND_0805 | 2
470p | CAP_0805 | C36, C60 | CAP_0805 | 2
510 | RES_0805 | R36, R54 | RES_0805 | 2
560 | RES_0805 | R3, R7, R8, R9, R10, R11, R12 | RES_0805 | 7
560nH | IND_0805 | L12, L16 | IND_0805 | 2
560p | CAP_0805 | C35 | CAP_0805 | 1
680nH | IND_0805 | L20 | IND_0805 | 1
680p | CAP_0805 | C59 | CAP_0805 | 1
820nH | IND_0805 | L13, L21 | IND_0805 | 2
820p | CAP_0805 | C58, C73 | CAP_0805 | 2
2027-07-SM-RPLF | 2027-07-SM-RPLF | U18 | 200307SMRPLF | 1
51022-0200 | 51022-0200 | FAN_OUT | 51022-0200 | 1
ADC | SMA | J2 | 31-5431 | 1
ADG904BRUZ-R | Integrated Circuit | U4, U15, U16, U17 | SOP65P640X120-20N | 4
ADG918BRMZ | Integrated Circuit | U8, U10, U11, U12, U13, U14 | SOP65P490X110-8N | 6
ADJ-1k | 306J | R30, R40 | 306J | 2
AFT09MS015NT1 | AFT09MS015NT1 | Q1, Q3 | AFT09MS015NT1 | 2
ANT1 | SMA | J1 | 31-5431 | 1
ANT2 | SMA | J5 | 31-5431 | 1
Axicom V23079 | Axicom V23079 | K1 | V23079 | 1
BAT46JFILM | Diode | D1, D3 | SOD2513X117N | 2
BAV99 | BAV99 | D24 | SOT23 | 1
BSS123 | N-Channel Logic Level Enhancement Mode Field Effect Transistor, 1.7 V, -55 to 150 degC, 3-Pin SOT-23, RoHS, Tape and Reel | Q6, Q7, Q8 | FAIR-SOT23-3_V | 3
DAC | SMA | J9 | 31-5431 | 1
EXTERNAL | 2*5 PIN | J3 | 90131-0126 | 1
IRLML9301 | MOSFET | Q2, Q5 | SOT23 | 2
JX2 | JX2 | J8 | 1986717-2 | 1
KTY81/120 | Integrated Circuit | R14 | TO254P420X460X770-2P | 1
LM1117DT-5.0 | Integrated Circuit | U6 | TO228P991X238-3N | 1
LT1117IST-ADJ | LT1117IST-ADJ | U5 | LT1117IST-ADJ | 1
MOTHERBOARD | 2*5 PIN | J4 | 90131-0126 | 1
PE4312 | Integrated Circuit | U9 | QFN50P400X400X90-21N | 1
PGA-103+ / SPF5189Z | PGA-103+ / SPF5189Z | Q4 | SOT89 | 1
SMAJ5.0A-TR | Diode | D2 | SMBJ36CATR | 1
SN74HC595D | 8-Bit Shift Registers With 3-State Output Registers, D0016A, TUBE | U1, U3, U7 | D0016A_L | 3
SS14 | SS14 | D18, D23 | SS14 | 2
SWR_TANDEM_MATCH | SWR_TANDEM_MATCH | TSWR | SWR_TANDEM_MATCH | 1
TRANSF_OUT | TRANSF_OUT | T4 | TRANSF_OUT | 1
ULN2003BDR | ULN2003BDR | U2 | ULN2003BDR | 1

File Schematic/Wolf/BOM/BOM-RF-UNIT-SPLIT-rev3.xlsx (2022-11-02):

Comment | Description | Designator | Footprint | Quantity
1k | RES_0805 | R31, R33, R57, R69, R70, R71, R72 | RESC2013X60X40NL20T25 | 7
1k | RES_0805 | R35 | RES_0805 | 1
1n | CAP_0805 | C112, C120 | CAP_0805 | 2
1n | CAP_0805 | C122 | 6-0805_M | 1
1N4148 | 1N4148 | D1, D4, D5, D8, D31 | SS14 | 5
2k | RES_0805 | R13 | RES_0805 | 1
10k | RES_1206 | R73 | RES_1206 | 1
10n | CAP_0805 | C121 | 6-0805_M | 1
10uF 25V | CAPAE_5.3x5.3h6.1 | C129 | CAPAE_5.3x5.3h6.1 | 1
18 | RES_1206 | R39 | RES_1206 | 1
30k | RES_0805 | R48, R75 | RES_0805 | 2
100n | CAP_0805 | C1, C107, C108, C109, C110, C130, C133, C134, C135 | CAP_0805 | 9
100n | CAP_0805 | C131 | 6-0805_M | 1
100p | CAP_0805 | C127, C132 | 6-0805_M | 2
220nH | IND_1206 | L46 | IND_1206 | 1
560 | RES_0805 | R3, R7, R8, R9, R10, R11, R12 | RES_0805 | 7
51022-0200 | 51022-0200 | FAN_OUT | 51022-0200 | 1
ADC | SMA | J2 | 31-5431 | 1
ADG918BRMZ | Integrated Circuit | U8, U10 | SOP65P490X110-8N | 2
ANT1 | SMA | J1 | 31-5431 | 1
ANT2 | SMA | J5 | 31-5431 | 1
Axicom IM06 | Axicom IM06 | U4, U12 | IM06GR | 2
BAV99 | BAV99 | D7 | SOT23 | 1
BPF_IN | SMA | J16 | 31-5431 | 1
BPF_OUT | SMA | J18 | 31-5431 | 1
BSS123 | N-Channel Logic Level Enhancement Mode Field Effect Transistor, 1.7 V, -55 to 150 degC, 3-Pin SOT-23, RoHS, Tape and Reel | Q12 | FAIR-SOT23-3_V | 1
DAC | SMA | J9 | 31-5431 | 1
EXTERNAL | 2*5 PIN | J3 | 90131-0126 | 1
G6S-2-DC12 | Relay or Contactor | K1, K2, K3 | G6S2DC12 | 3
HF_AMP_IN | SMA | J7 | 31-5431 | 1
HF_LPF_OUT | SMA | J10 | 31-5431 | 1
IRLML9301 | MOSFET | Q11 | SOT23 | 1
KTY81/120 | Integrated Circuit | R14 | TO254P420X460X770-2P | 1
LM1117DT-5.0 | Integrated Circuit | U6 | TO228P991X238-3N | 1
MOTHERBOARD | 2*5 PIN | J4 | 90131-0126 | 1
OUT_AMPS | 2*5 PIN | J11 | 90131-0126 | 1
OUT_BPF | 2*5 PIN | J14 | 90131-0126 | 1
OUT_EXT | 2*5 PIN | J20 | 90131-0126 | 1
OUT_LPF | 2*5 PIN | J15 | 90131-0126 | 1
OUT_TUNER_C | 2*5 PIN | J13 | 90131-0126 | 1
OUT_TUNER_I | 2*5 PIN | J12 | 90131-0126 | 1
PE4312 | Integrated Circuit | U9 | QFN50P400X400X90-21N | 1
PGA-103+ / SPF5189Z | PGA-103+ / SPF5189Z | Q4 | SOT89 | 1
SMAJ5.0A-TR | Diode | D2 | SMBJ36CATR | 1
STPIC6C595TTR | Integrated Circuit | U1, U2, U3, U5, U7, U11 | SOP65P640X120-16N | 6
TUNER_IN | SMA | J17 | 31-5431 | 1
TUNER_OUT | SMA | J19 | 31-5431 | 1
VHF_AMP_IN | SMA | J6 | 31-5431 | 1
VHF_LPF_OUT | SMA | J8 | 31-5431 | 1

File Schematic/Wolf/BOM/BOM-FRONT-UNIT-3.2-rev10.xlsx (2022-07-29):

Comment | Description | Designator | Footprint | Quantity
0 | RES_0805 | R23, R24, R25 | RES_0805 | 3
1n | CAP_1206 | C5 | CAP_1206 | 1
1n4148w | Diode | D25, D27 | SOD3716X135N | 2
1uF | CAP_1206 | C3 | CAP_1206 | 1
3.3k | RES_0805 | R20, R21, R22 | RES_0805 | 3
4.7k | RES_0805 | R3, R4, R5, R6, R7, R8, R9, R10, R11, R12, R13, R14, R15, R16, R17, R18, R19, R29, R30, R31, R32, R33, R34, R35, R36 | RES_0805 | 25
8.2n | CAP_1206 | C11 | CAPC2013X94X50LL20T25 | 1
10n | CAP_0805 | C12, C13 | CAP_0805 | 2
22uF 10V | EEEFC_sizeB | C10 | EEEFC_sizeB | 1
30k | RES_0805 | R26, R27, R28 | RESC2013X60X40NL20T25 | 3
100n | CAP_0805 | C1, C2, C9 | CAP_0805 | 3
100n | CAP_1206 | C4 | CAP_1206 | 1
120p | CAP_1206 | C8 | CAP_1206 | 1
470p | CAP_1206 | C7 | CAP_1206 | 1
1000uF | CAP250RP | C6 | CAP250RP | 1
BNX016-01 | BNX016-01 | T1 | TRANSF_ICORE | 1
BSS123 | N-Channel Logic Level Enhancement Mode Field Effect Transistor, 1.7 V, -55 to 150 degC, 3-Pin SOT-23, RoHS, Tape and Reel | Q2 | FAIR-SOT23-3_V | 1
DM3AT-SF-PEJM5 | Connector | J2 | DM3ATSFPEJM5 | 1
ESP-01 ESP8266 | ESP-01 ESP8266 | ESP-8266 | ESP-01 ESP8266 | 1
FPC-45P-0.5mm | Connector | J7 | FH12S45S05SH60 | 1
ILI9481 480*320 3'2 | LCD-MODULE_3'2_480х320 | LCD-MODULE | LCD-MODULE-3.2-480-320 | 1
IRFR9024NPBF | IRFR9024NPBF, Транзистор, Р-канал 55В 11А | Q1 | ONSC-DPAK-3-369C-01_V | 1
JX2 | JX2 | ACCUM, IN, MOTHERBOARD, RF-UNIT | JX2 | 4
MCP3008-I/SL | MCP3008-I/SL | U1, U2, U3 | MCP3008-I/SL | 3
MF-MSMF110_16-2 | Fuse | F2 | FUSC4632X85N | 1
OPTICAL ENCODER | OPTICAL ENCODER | ENCODER_MAIN | 644456-4 | 1
PEC12 | PEC12 | ENC2 | PEC12 | 1
PJ-050B | PJ-050B | IN_2 | PJ-050B | 1
PTS645SK50LFS | PTS645SK50LFS | S1, S2, S3, S4, S5, S6, S7, S8, S9, S10, S11, S12, S13, S14, S15, S16, S17, S18, S19, S20, S21, S22, S23 | PTS645SK50LFS | 23
ptv09a-4225f-b102 | Adjustable Resistor PTV09 | R1, R2 | PTV09 | 2
RUEF400 | Fuse | F1 | RUEF400 | 1
SM6T15A | Diode | D28 | SMBJ36CATR | 1

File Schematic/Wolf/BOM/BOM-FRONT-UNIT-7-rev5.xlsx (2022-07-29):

Comment | Description | Designator | Footprint | Quantity
0 | RES_0805 | R27, R28, R29 | RES_0805 | 3
0.1 |  | C12 | CH0805C | 1
1k | RES_0805 | R12, R13, R14, R15 | RES_0805 | 4
1n | CAP_1206 | C8 | CAP_1206 | 1
1n4148w | Diode | D2, D3 | SOD3716X135N | 2
1uF | CAP_1206 | C6 | CAP_1206 | 1
2k | RES_0805 | R17, R18, R19, R20 | RES_0805 | 4
3.3k | RES_0805 | R30, R31, R32 | RES_0805 | 3
3.3uH | IND_1812 | L2 | IND_1812 | 1
4.7k | RES_0805 | R1, R8, R9, R10, R11, R21, R22, R23, R24, R33, R34 | RES_0805 | 11
4.7uF 16V | CAPAE_6.6x6.6h5.4 | C2 | CAPAE_6.6x6.6h5.4 | 1
8.2n | CAP_1206 | C11 | CAPC2013X94X50LL20T25 | 1
10n | CAP_0805 | C17, C18 | CAP_0805 | 2
10uH | Inductor | L1 | IND_FERRITE_CORE | 1
15k | RES_0805 | R2 | RES_0805 | 1
22uF 10V | CAPAE_4.3x4.3h5.4 | C3 | CAPAE_4.3x4.3h5.4 | 1
22uF 10V | EEEFC_sizeB | C13 | EEEFC_sizeB | 1
30k | RES_0805 | R3, R4, R5 | RESC2013X60X40NL20T25 | 3
47k |  | R25 | CH0805R | 1
47k |  | R26 | CH0805C | 1
100 |  | R16 | CH0805R | 1
100n | CAP_0805 | C1, C4, C14, C15, C16 | CAP_0805 | 5
100n | CAP_1206 | C7 | CAP_1206 | 1
120p | CAP_1206 | C10 | CAP_1206 | 1
470p | CAP_1206 | C9 | CAP_1206 | 1
1000uF | CAP250RP | C5 | CAP250RP | 1
BNX016-01 | BNX016-01 | T1 | TRANSF_ICORE | 1
BSS123 | N-Channel Logic Level Enhancement Mode Field Effect Transistor, 1.7 V, -55 to 150 degC, 3-Pin SOT-23, RoHS, Tape and Reel | Q2 | FAIR-SOT23-3_V | 1
DM3AT-SF-PEJM5 | Connector | J2 | DM3ATSFPEJM5 | 1
ESP-01 ESP8266 | ESP-01 ESP8266 | ESP-1 | ESP-01 ESP8266 | 1
FPC-45P-0.5mm | Connector | J1 | FH12S45S05SH60 | 1
IRFR9024NPBF | IRFR9024NPBF, Транзистор, Р-канал 55В 11А | Q1 | ONSC-DPAK-3-369C-01_V | 1
JX2 | JX2 | IN1, MOTHERBOARD1, RF-UNIT1 | JX2 | 3
LCD-RA8875 | LCD-RA8875 | U1 | LCD-RA8875 | 1
MCP3008-I/SL | MCP3008-I/SL | U3 | MCP3008-I/SL | 1
MCP6001UT |  | U4, U5 | SOT23-5 | 2
MF-MSMF110_16-2 | Fuse | F2 | FUSC4632X85N | 1
MIC_OUT | 51022-0200 | MIC_OUT1 | 51022-0200 | 1
OPTICAL ENCODER | OPTICAL ENCODER | ENCODER_MAIN1 | 644456-4 | 1
PEC12 | PEC12 | ENC1 | PEC12 | 1
PJ-3,5 |  | J3, J4, J5 | Audio-PJ-392 | 3
PTS645SK50LFS | PTS645SK50LFS | S1, S2, S3, S4, S5, S6, S7, S8, S9, S10, S11, S12 | PTS645SK50LFS | 12
PTT |  | X1, X2 | CON: PLS-6 | 2
PTT_OUT | 51022-0200 | PTT_OUT1 | 51022-0200 | 1
ptv09a-4225f-b102 | Adjustable Resistor PTV09 | R6, R7 | PTV09 | 2
RUEF400 | Fuse | F1 | RUEF400 | 1
SM6T15A | Diode | D1 | SMBJ36CATR | 1
SMAJ5.0A-TR | Diode | D4 | SMBJ36CATR | 1
ST1S10 | ST1S10 | U2 | ST1S10 | 1

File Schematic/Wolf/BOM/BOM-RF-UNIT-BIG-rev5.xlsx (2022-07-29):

Comment | Description | Designator | Footprint | Quantity
 | Capacitor NP0 HiVolt | C96, C97, C98, C99, C100 | CAP_1206 | 5
0 | RES_0805 | R49, R50, R65, R67 | RES_0805 | 4
0.1uH | Inductor | L35 | IND_FERRITE_CORE_1 | 1
0.22uH | Inductor | L36 | IND_FERRITE_CORE_1 | 1
0.45uH | Inductor | L39 | IND_FERRITE_CORE_1 | 1
1:1 | 1:1 | T5 | TRANSF_ACORE2 | 1
1k | RES_0805 | R5, R6, R35, R42, R43, R64, R68 | RES_0805 | 7
1k | RES_0805 | R31, R33, R57, R69, R70, R71, R72 | RESC2013X60X40NL20T25 | 7
1n | CAP_0805 | C112, C115, C120 | CAP_0805 | 3
1n | CAP_0805 | C122 | 6-0805_M | 1
1n | CAP_1206 | C94, C104 | CAP_1206 | 2
1n8 | CAP_1206 | C105 | CAP_1206 | 1
1N4148 | 1N4148 | D4, D5, D6, D8, D9, D10, D11, D12, D13, D14, D15, D16, D17, D19, D20, D21, D22, D24, D25, D26, D27, D28, D29, D30, D31, D32, D38, D39, D40, D41, D42, D43, D44, D45, D46, D47, D48 | SS14 | 37
1uF | CAP_0805 | C62, C63, C79, C83, C126, C128 | CAP_0805 | 6
1uH | Inductor | L7, L8, L9, L41 | IND_FERRITE_CORE_1 | 4
1.2k | RES_0805 | R53 | RES_0805 | 1
1.2n 500V | CAP_1206 | C57 | CAP_1206 | 1
1.6uH | Inductor | L13, L14, L15, L16, L17, L18 | IND_FERRITE_CORE_1 | 6
2k | RES_0805 | R13 | RES_0805 | 1
2p | Capacitor NP0 HiVolt | C2, C3 | CAP_1206 | 2
2.2k | RES_0805 | R77, R78 | RES_0805 | 2
2.2n | Capacitor NP0 HiVolt | C48, C49 | CAP_1206 | 2
2.2p | Capacitor NP0 HiVolt | C7, C8 | CAP_1206 | 2
2.2uF | CAP_1206 | C95 | CAP_1206 | 1
2.2uH | Inductor | L42 | IND_FERRITE_CORE_1 | 1
2.7k | RES_0805 | R37 | RES_0805 | 1
2.7uH | Inductor | L19, L20, L21 | IND_FERRITE_CORE_1 | 3
4.7 | RES_1206 | R38, R47, R74, R76 | RES_1206 | 4
4.7n | CAP_0805 | C70, C75 | CAP_0805 | 2
4.7n | Capacitor NP0 HiVolt, CAP_1206 | C50, C53, C54 | CAP_1206 | 3
5p | Capacitor NP0 HiVolt | C4, C5, C6 | CAP_1206 | 3
5.1p | Capacitor NP0 HiVolt | C12, C13 | CAP_1206 | 2
6.5-30p | TZC3P300A110 | C65, C66 | 5025[2010] | 2
6.8k | RES_0805 | R32 | RES_0805 | 1
6.8n | Capacitor NP0 HiVolt | C1, C51 | CAP_1206 | 2
6.8uH | Inductor | L22, L23, L24 | IND_FERRITE_CORE_1 | 3
8.2nH | IND_0805 | L32, L33, L34 | IND_0805 | 3
10k | RES_1206 | R73 | RES_1206 | 1
10n | CAP_0805 | C121 | 6-0805_M | 1
10n | CAP_1206 | C69, C92, C102 | CAP_1206 | 3
10p | Capacitor | C84 | B32620A0682J000 | 1
10p | Capacitor NP0 HiVolt | C10 | CAP_1206 | 1
10uF 25V | CAPAE_5.3x5.3h6.1 | C129 | CAPAE_5.3x5.3h6.1 | 1
10uH | Inductor | L30, L43 | IND_FERRITE_CORE | 2
11uH | Inductor | L25, L26, L27 | IND_FERRITE_CORE_1 | 3
12p | Capacitor NP0 HiVolt | C9, C11 | CAP_1206 | 2
13.8V | JX2 | J8 | 1986717-2 | 1
15n | CAP_1206 | C81, C111 | CAP_1206 | 2
18 | RES_1206 | R39 | RES_1206 | 1
20 | RES_1206 | R23, R61 | RES_1206 | 2
22 2W | CFR200J100R | R1, R2 | RES-2W | 2
22nH | IND_0805 | L48 | IND_0805 | 1
22p | Capacitor | C85 | B32620A0682J000 | 1
22p | Capacitor NP0 HiVolt | C14, C15, C16, C17, C18, C22, C23 | CAP_1206 | 7
22uF | CAPAE_6.6x6.6h5.4 | C74, C77 | CAPAE_6.6x6.6h5.4 | 2
27pF | CAP_0805 | C55 | CAP_0805 | 1
30k | RES_0805 | R4, R41, R45, R48, R75 | RES_0805 | 5
33p | Capacitor NP0 HiVolt | C20 | CAP_1206 | 1
39p | Capacitor NP0 HiVolt | C19, C21 | CAP_1206 | 2
47p | Capacitor | C86 | B32620A0682J000 | 1
47p | Capacitor NP0 HiVolt | C25 | CAP_1206 | 1
47uF 25V | CAPAE_6.6x6.6h5.4 | C119 | CAPAE_6.6x6.6h5.4 | 1
50 | RES_1206 | R55, R56 | RES_1206 | 2
56 | RES_0805 | R15, R16, R26, R27, R44 | RES_0805 | 5
56p | Capacitor NP0 HiVolt | C24, C26, C27, C28, C32, C33 | CAP_1206 | 6
82p | Capacitor NP0 HiVolt | C30, C37, C39 | CAP_1206 | 3
100 | RES_0805 | R28, R29, R51 | RES_0805 | 3
100 | RES_1206 | R34 | RES_1206 | 1
100n | CAP_0805 | C38, C59, C64, C67, C71, C76, C78, C80, C82, C89, C90, C107, C108, C109, C110, C113, C114, C116, C117, C118, C123, C124, C125, C130, C133, C134, C135, C136, C137, C138, C139, C140, C141, C142, C143, C144, C145, C146, C147, C148, C149, C150, C151, C152, C153, C154, C155, C156, C157, C158, C159, C160, C161, C162, C163, C164, C165, C166, C167, C168, C169, C170, C171 | CAP_0805 | 63
100n | CAP_0805 | C131 | 6-0805_M | 1
100n | CAP_1206 | C58, C61, C106 | CAP_1206 | 3
100p | CAP_0805 | C72 | CAP_0805 | 1
100p | CAP_0805 | C127, C132 | 6-0805_M | 2
100p | Capacitor | C87 | B32620A0682J000 | 1
100p | Capacitor NP0 HiVolt, CAP_1206 | C29, C31, C91, C93, C103 | CAP_1206 | 5
100pF 500V | CAP_1206 | C52, C56 | CAP_1206 | 2
120p | CAP_0805 | C68, C73 | CAP_0805 | 2
120p | Capacitor NP0 HiVolt | C35 | CAP_1206 | 1
150p | Capacitor NP0 HiVolt | C34, C36 | CAP_1206 | 2
158uH | Inductor | L28, L29, L40 | IND_FERRITE_CORE_1 | 3
180p | Capacitor NP0 HiVolt | C41, C43, C44 | CAP_1206 | 3
200 | RES_0805 | R52 | RES_0805 | 1
200nH | Inductor | L1, L2, L3 | IND_FERRITE_CORE_1 | 3
200p | CAP_1206 | C101 | CAP_1206 | 1
200pF 500V | CAP_1206 | C60 | CAP_1206 | 1
220nH | IND_1206 | L31, L46 | IND_1206 | 2
220p | Capacitor | C88 | B32620A0682J000 | 1
220p | Capacitor NP0 HiVolt | C40, C42 | CAP_1206 | 2
300 | RES_1206 | R24, R25, R62, R63 | RES_1206 | 4
390p | Capacitor NP0 HiVolt | C46 | CAP_1206 | 1
430 | RES_1206 | R59, R60 | RES_1206 | 2
470 | RES_1206 | R22 | RES_1206 | 1
470p | Capacitor NP0 HiVolt | C45, C47 | CAP_1206 | 2
510 | RES_0805 | R36, R54 | RES_0805 | 2
560 | RES_0805 | R3, R7, R8, R9, R10, R11, R12 | RES_0805 | 7
620 | RES_0805 | R58 | RES_0805 | 1
680nH | Inductor | L4, L5, L6 | IND_FERRITE_CORE_1 | 3
750 | RES_1206 | R21 | RES_1206 | 1
820nH | Inductor | L10, L11, L12 | IND_FERRITE_CORE_1 | 3
2027-07-SM-RPLF | Undefined or Miscellaneous | U13 | 200307SMRPLF | 1
51022-0200 | 51022-0200 | FAN_OUT | 51022-0200 | 1
ADC | SMA | J2 | 31-5431 | 1
ADG918BRMZ | Integrated Circuit | U8, U10 | SOP65P490X110-8N | 2
ADJ-1k | 306J | R30, R40, R46 | 306J | 3
ADJ-10k | 3296W-1-103LF | R19, R20 | 3296W-1 | 2
ADJ-100 | 306J | R66 | 306J | 1
ANT1 | SMA | J1 | 31-5431 | 1
ANT2 | SMA | J5 | 31-5431 | 1
Axicom IM06 | Axicom IM06 | U4, U12 | IM06GR | 2
BAT46JFILM | Diode | D1, D3, D49, D50 | SOD2513X117N | 4
BAV99 | BAV99 | D7 | SOT23 | 1
BLM21 | BLM21 | FB1 | IND_0805 | 2
BSS123 | N-Channel Logic Level Enhancement Mode Field Effect Transistor, 1.7 V, -55 to 150 degC, 3-Pin SOT-23, RoHS, Tape and Reel | Q12 | FAIR-SOT23-3_V | 1
DAC | SMA | J9 | 31-5431 | 1
EXTERNAL | 2*5 PIN | J3 | 90131-0126 | 1
G6S-2-DC12 | Relay or Contactor | K1, K2, K3, K4, K5, K6, K7, K8, K9, K10, K11, K12, K13, K14, K15, K16, K17, K18, K19, K20, K21, K22, K23, K24, K25, K26, K27, K28, K29, K30, K31, K32, K33, K34, K35 | G6S2DC12 | 35
HiCurrent 13.8V | JX2 | J6, J7 | 1986717-2 | 2
IRLML9301 | MOSFET | Q2, Q7, Q10, Q11 | SOT23 | 4
KTY81/120 | Integrated Circuit | R14 | TO254P420X460X770-2P | 1
LM1117DT-5.0 | Integrated Circuit | U6 | TO228P991X238-3N | 1
LT1117IST-5.0 | LT1117IST-5.0 | U19 | LT1117IST-ADJ | 1
LT1117IST-ADJ | LT1117IST-ADJ | U5, U20 | LT1117IST-ADJ | 2
MOTHERBOARD | 2*5 PIN | J4 | 90131-0126 | 1
PE4302 | Integrated Circuit | U9 | QFN50P400X400X90-21N | 1
PGA-103+ / SPF5189Z | PGA-103+ / SPF5189Z | Q4 | SOT89 | 1
RA80H1415M1 | RA80H1415M1 | Q8 | RA80H1415M1 | 1
RD01MUS1 | RD01MUS1 | Q9 | SOT89 | 1
RD16HHF1 | RD16HHF1 | Q1, Q3 | RD16_V2 | 2
RD100HHF1 | RD100HHF1 | Q5, Q6 | RD100_V2 | 2
SMAJ5.0A-TR | Diode | D2 | SMBJ36CATR | 1
SS14 | SS14 | D18, D23, D35, D36, D37 | SS14 | 5
STPIC6C595TTR | Integrated Circuit | U1, U2, U3, U7, U11 | SOP65P640X120-16N | 5
SWR_TANDEM_MATCH | SWR_TANDEM_MATCH | TSWR | SWR_TANDEM_MATCH | 1
SWR_VHF | SWR_VHF | T6 | SWR_VHF | 1
TRANSF_HF1 | TRANSF_HF1 | T2 | TRANSF_HF1 | 1
TRANSF_HF2 | TRANSF_HF2 | T1 | TRANSF_HF2-3 | 1
TRANSF_HF3 | TRANSF_HF3 | T3 | TRANSF_HF3 | 1

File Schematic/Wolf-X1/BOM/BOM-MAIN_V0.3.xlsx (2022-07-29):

Посадочное место | Номинал | Количество | Footprint
MicroSD1 | DM3AT-SF-PEJM5 | 1 | Micro SD - M
B1 батарейка | CR1220 | 1 | CR1220
C1 | 7.5p | 1 | CH0603C
C2, C3 | 22p | 2 | CH0603C
C4, C7, C30, C33, C38, C39, C40, C44, C45, C46, C47, C62, C63, C64, C66, C118, C154, C176, C177, C181, C182, C184, C190, C193 | 0.1u | 24 | CH0603C
C5, C6 | 2u2 | 2 | CH0603C
C8, C37, C85, C155, C157, C164 | 10u | 6 | CH0603C
C9, C10 | 6p | 2 | CH0603C
C11, C12, C13, C14, C15, C16, C17, C18, C19, C20, C21, C22, C23, C24, C25, C26, C27, C28, C29, C54, C55, C56, C67, C76, C79, C80, C82, C83, C84, C86, C88, C89, C90, C91, C92, C93, C94, C95, C96, C97, C98, C101, C102, C103, C105, C108, C110, C112, C114, C115, C116, C117, C120, C122, C123, C124, C125, C126, C127, C128, C129, C130, C131, C132, C133, C183, C187, C207, C208 | 0.1 | 69 | CH0603C
C31, C32, C178, C179, C180 | 10uF10V | 5 | TANTAL_A
C34, C36, C41, C42, C73, C74, C191, C195, C198 | 1u | 9 | CH0603C
C35, C77, C185, C189 | 470p | 4 | CH0603C
C43 | 10p | 1 | CH0603C
C48, C49, C99 | 1n | 3 | CH0603C
C50, C51, C52 | 1uF | 3 | CH0603C
C53, C57, C58 | 220uF | 3 | POLIMER-E
C59, C60, C61, C65 | 10uF10V | 4 | TANTAL_A
C68, C70, C71 | 1uF 10V | 3 | TANTAL_A
C69, C78 | 10n | 2 | CH0603C
C72, C140, C148 | 220p | 3 | CH0603C
C75 | 10uF 10V | 1 | TANTAL_A
C81, C111 | 8.2n | 2 | CH0603C
C87, C221 | 8p | 2 | CH0603C
C100, C107 | 10uF 10V | 2 | TANTAL_B
C104, C137, C153, C220 | 110p | 4 | CH0603C
C106, C212 | 15p | 2 | CH0603C
C109 | 4.7uF 47V | 1 | POLIMER-E
C113 | 22uF 10V | 1 | POLIMER-E
C119, C204 | 120p | 2 | CH0603C
C121, C145, C201, C211 | 100p | 4 | CH0603C
C134, C138, C142, C146, C150 | 180p | 5 | CH0603C
C135, C151 | 51p | 2 | CH0603C
C136, C152 | 390p | 2 | CH0603C
C139, C147 | 43p | 2 | CH0603C
C141, C149 | 91p | 2 | CH0603C
C143, C199 | 47p | 2 | CH0603C
C144 | 330p | 1 | CH0603C
C156, C165, C172, C202 | 33p | 4 | CH0603C
C158, C174 | 39p | 2 | CH0603C
C159, C168 | 20p | 2 | CH0603C
C160, C162, C166, C214 | 22uf | 4 | CH1206C
C161, C170 | 24p | 2 | CH0603C
C163 | 27p | 1 | CH0603C
C167, C169, C171 | 4.7uF | 3 | TANTAL_A
C173, C175, C192, C194 | 6.8n | 4 | CH0603C
C186 | 10n/none | 1 | CH0603C
C188 | 2.7n | 1 | CH0603C
C196, C197 | 680p | 2 | CH0603C
C200, C203 | 6.5-30pF | 2 | C_trimer
FB1, FB2, FB3 | Ferrite_Bead | 3 | CH0805L
FB4, FB5, L2 | BLM21 | 3 | CH0805L
J1 | BOOT | 1 | CON: PLS-2
J2, J4, J5 | PJ-307 | 3 | PJ-307
L1 | 22uH | 1 | 4020
L3, L44 | 330nH | 2 | L1210
L4, L43 | 22nH | 2 | L1210
L5 | 3.3uH | 1 | IND: CDRH74
L6 | 10uH | 1 | IND: CDRH74
L7, L11, L15 | 6.2uH | 3 | L1210
L8, L12, L16 | 2.2uH | 3 | L1210
L9, L13, L17 | 12uH | 3 | L1210
L10, L14, L18 | 3.3uH | 3 | L1210
L19, L24, L28 | 0.68uH | 3 | L1210
L20, L22, L23, L37 | 2.2uH | 4 | 4020
L21, L26, L30 | 1.2uH | 3 | L1210
L31 | 270nH | 1 | L1210
L32, L34, L36 | 8.2nH | 3 | L1210
L33 | 82nH | 1 | L1210
L35 | 100nH | 1 | L1210
L40, L42 | 180nH | 2 | L1210
L41 | 27nH | 1 | L1210
R1, R2, R3, R7, R11, R13, R14, R15, R16, R23, R24, R25, R33, R42, R65, R70, R73, R87, R88 | 10k | 19 | CH0603R
R4, R48 | 11k | 2 | CH0603R
R5, R6, R9, R51, R75, R77 | 22 | 6 | CH0603R
R8, R27, R28 | 3.3К | 3 | CH0603R
R10, R12, R32, R66, R67, R68, R69, R71, R74 | 1k | 9 | CH0603R
R17 | 1.5k | 1 | CH0603R
R18, R78 | 56 | 2 | CH0603R
R19, R20 | 10 | 2 | CH0603R
R21, R22, R54, R80, R81 | 100 | 5 | CH0603R
R26 | 680 | 1 | CH0603R
R29, R30, R31, R36, R55, R56 | 47K | 6 | CH0603R
R34, R35 | none | 2 | CH0603R
R37 | 5.6k | 1 | CH0603R
R38, R39 | 82 | 2 | CH0603R
R40, R41 | 130 | 2 | CH0603R
R43 | 120k +100k parallel | 1 | CH0603R
R44, R45, R46 | 30k | 3 | CH0603R
R47, R49 | 2K | 2 | CH0603R
R50, R53 | 0 | 2 | CH0603R
R52 | 18k | 1 | CH0603R
R57, R58 |  | 2 | CH0603R
R72 | 1k5 | 1 | CH0603R
R82, R83, R84 | 330 | 3 | CH0603R
R85, R86 | 5.6 | 2 | CH0603R
T1 | 1:4 ADT4-6T | 1 | TC4-1-ADT4-6
T2 | 1:1 T1-6T | 1 | TC4-1-ADT4-6
T3 | 1:1 ADT1-1 | 1 | TC4-1-ADT4-6
U1 | W25Q16 | 1 | SOIC-8-1
U2 | STM32H743 | 1 | 100-LQFP
U3 | M25P80 | 1 | SOIC-8-1
U4 | EP4CE22E22C8N | 1 | 144-QFN
U5, U13 | LM1085-3.3 | 2 | DPAK_132
U6 | LTC6400IUD | 1 | 16-QFN 3x3
U7 | LTC2208CUP | 1 | 64-QFN 9x9
U8 | PAM8406 | 1 | SOP-16
U9 | WM8731 | 1 | 28-SSOP
U10 | LD3985M33R | 1 | SOT23-5
U11 | ACS712-20 | 1 | 8-SOIC
U12, U18 | ADG918BRMZ | 2 | 8-MSOP (NO PAD)
U14 | ST1S10 | 1 | 8-SOIC (PAD)
U15, U16 | MCP6001UT | 2 | SOT23-5
U17 | USBLC6-2SC6 | 1 | SOT23-6-ASM
U19 | SC189CSKTRT | 1 | SOT23-5
U20 | PE4302 | 1 | 20-QFN (4x4)
U21, U22, U23, U24 | FST3253 | 4 | 16-SSOP
U25 | AMS1117-1.8 | 1 | SOT223
U26 | AMS1117-3.3 | 1 | SOT223
U27 | DAC5674IPHP | 1 | 48-TQFP
U28 | OPA2673IRGVT | 1 | 16-QFN 4x4 PAD17
U29, U30, U31 | SC189 | 3 | SOT23-5
D2 | BAV-99 | 1 | SOT23_132
VD1, VD2 | 1N4108 | 2 | 1N4148
VD3 | BZT52-C5V1 | 1 | SOD123
VT1 | BSS123 | 1 | SOT23_132
VT2 | IRFR9024NPBF | 1 | D2PAK_132
X1 | USB-B | 1 | CON: USB-B
X2 | PLS-5 | 1 | CON: PLS-5
X3, X4 | PLD-10 | 2 | CON: PLD-10
X5 | CWF-3 | 1 | CON: CWF-3
X6 | Разъем DC005 | 1 | CON: PJ-102AH
X7 | PLD-10 | 1 | CON: PLD-10
X9 | PLS-3 | 1 | CON: PLS-3
X10 | ENCODER_MAIN1 | 1 | CON: PLS-4
X12, X14 | U.FL-R-SMT U FL IPEX | 2 | CON: u.Fl
X13 | "PTT" | 1 | RJ25-6pin
XG1 | 12.288Mhz TCXO 3.3v TTL/CMOS (set other freq in fpga code) | 1 | OSC: 5032
XG2 | 122.88Mhz | 1 | OCS: GENA
Y1 | 8 мГц | 1 | OSC: Hz
Y2 | ABS 32.768khz | 1 | ABS-25

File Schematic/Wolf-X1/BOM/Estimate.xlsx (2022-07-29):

№ | Название | Количество | Цена | доставка | штук | Ссылка | Чип и дип | Общая цена | Доставка
MAIN |  |  |  |  |  |  |  | 346.32 | 39.12
 | DM3AT-SF-PEJM5 | 1 | 2.94 | 0.74 | 10 | Aliexpress (https://s.click.aliexpress.com/e/_9isgm1)
 | Индуктивность SMD 0630 3.3uH | 1 | 0.63 | 0.24 | 10 | Aliexpress (https://aliexpress.ru/item/4000557059726.html?item_id=4000557059726&sku_id=10000002922152209) |  | 385.44
 | Индуктивность SMD 0630 10uH | 1 | 0.63 | 0.24 | 10 | Aliexpress (https://aliexpress.ru/item/4000557059726.html?item_id=4000557059726&sku_id=10000002922152209)
 | Индуктивность SMD 0420 2,2uH | 4 | 1.60 | 1.29 | 10 | Aliexpress (https://aliexpress.ru/item/1005001648530241.html?spm=a2g2w.productlist.0.0.7b42d5be3thNsw) | ChipDip (https://www.chipdip.ru/product/ha72l-04202r2lftr?from=suggest_product)
 | Индуктивность SMD 0530 10uH | 1 | 0.70 | 0.18 | 10 | Aliexpress (https://aliexpress.ru/item/4001035691825.html?item_id=4001035691825&sku_id=10000013672787789)
 | SC189CSKTRT | 4 | 2.75 | 1.23 | 10 | Aliexpress (https://s.click.aliexpress.com/e/_97KRnB) | ChipDip (https://www.chipdip.ru/product0/8001051325?from=suggest_product)
 | LM1085-3.3 | 2 | 0.79 | 0.75 | 1 | Aliexpress (https://s.click.aliexpress.com/e/_A281Oz)
 | ST1S10PHR | 1 | 4.85 | 2.53 | 5 | Aliexpress (https://s.click.aliexpress.com/e/_9g82VX)
 | ACS712-20 | 1 | 4.36 | 2.53 | 5 | Aliexpress (https://s.click.aliexpress.com/e/_ADbq7F)
 | LD3985M33R | 1 | 0.94 |  | 10 | Aliexpress (https://s.click.aliexpress.com/e/_AMh9kh)
 | AMS1117-3.3 | 2 | 0.92 |  | 20 | Aliexpress (https://s.click.aliexpress.com/e/_AeJeaD)
 | AMS1117-1.8 | 1 | 1.18 |  | 20 | Aliexpress (https://s.click.aliexpress.com/e/_AeJeaD)
 | MCP6001UT | 2 | 1.96 |  | 10 | Aliexpress (https://s.click.aliexpress.com/e/_9ihxe9)
 | PE4302 | 1 | 2.31 | 0.65 | 5 | Aliexpress (https://s.click.aliexpress.com/e/_AfZ1iz)
 | NV7050SA 122.88Mhz | 1 | 5.00 | 3.79 | 1 | Aliexpress (https://s.click.aliexpress.com/e/_A5JA5P)
 | 12.288Mhz | 1 | 20.00 | 3.47 | 2 | Aliexpress (https://aliexpress.ru/item/4000577979227.html?sku_id=10000003324946109)
 | PAM8406DR | 1 | 3.00 | 0.74 | 10 | Aliexpress (https://s.click.aliexpress.com/e/_A8j981)
 | M25P80-VMW6G | 1 | 1.45 |  | 10 | Aliexpress (https://s.click.aliexpress.com/e/_A6hL4Z)
 | EP4CE22E22C8N | 1 | 59.85 | 2.11 | 1 | Aliexpress (https://s.click.aliexpress.com/e/_9iUwY9)
 | STM32H743VIT6 | 1 | 17.78 |  | 1 | Aliexpress (https://aliexpress.ru/item/1005003007981742.html?mp=1&sku_id=12000023197731242)
 | 25Q16BVSIG | 1 | 1.37 |  | 5 | Aliexpress (https://s.click.aliexpress.com/e/_AqCio9)
 | WM8731 | 1 | 4.68 | 2.53 | 2 | Aliexpress (https://s.click.aliexpress.com/e/_Akey6D)
 | LTC6400IUD | 1 | 2.85 | 1.24 | 1 | Aliexpress (https://s.click.aliexpress.com/e/_AseOOZ)
 | LTC2208CUP | 1 | 11.05 | 3.16 | 1 | Aliexpress (https://s.click.aliexpress.com/e/_ADIvIz)
 | OPA2673IRGVT | 1 | 4.95 |  | 5 | Aliexpress (https://s.click.aliexpress.com/e/_AAqwKp)
 | DAC5674IPHP | 1 | 14.00 | 3.04 | 1 | Aliexpress (https://s.click.aliexpress.com/e/_9y3KyN)
 | MC306 32,768 кГц | 1 | 1.08 | 0.41 | 10 | Aliexpress (https://aliexpress.ru/item/1994878414.html?sku_id=52635197667)
 | USBLC6-2SC6 | 1 | 1.01 |  | 10 | Aliexpress (https://s.click.aliexpress.com/e/_9xdO4z)
 | hc-49s 8 МГц | 1 | 1.14 | 0.20 | 20 | Aliexpress (https://s.click.aliexpress.com/e/_9QtdNT)
 | USB B типа «мама» | 1 | 1.01 | 0.37 | 10 | Aliexpress (https://s.click.aliexpress.com/e/_A1iVsh)
 | PJ-307 | 3 | 0.73 |  | 10 | Aliexpress (https://s.click.aliexpress.com/e/_AUoOZf)
 | ADG918BRMZ | 2 | 1.17 | 0.20 | 1 | Aliexpress (https://s.click.aliexpress.com/e/_989xMD)
 | FST3253MTCX | 4 | 1.68 |  | 5 | Aliexpress (https://s.click.aliexpress.com/e/_AFJSln)
 |  |  | 180.36 | 31.64
PA UNIT
 | STPIC6C595TTR | 1 | 2.42 | 0.74 | 5 | Aliexpress (https://aliexpress.ru/item/1005001359582377.html?sku_id=12000015804019376)
 | Реле | 4 | 2.73 |  | 5 | Aliexpress (https://aliexpress.ru/item/4000017778928.html?item_id=4000017778928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)
 | MCP3008-I/SL | 1 | 1.45 | 0.20 | 1 | Aliexpress (https://s.click.aliexpress.com/e/_9JQuQz)
 | RA08H1317M | 1 | 12.89 |  | 1 | Aliexpress (https://s.click.aliexpress.com/e/_A64gRR)
 | RJ12 6pin | 1 | 1.83 |  | 10 | Aliexpress (https://s.click.aliexpress.com/e/_AmN5bL)
 | PGA-103+ | 1 | 2.20 | 1.58 | 1 | Aliexpress (https://s.click.aliexpress.com/e/_9hNUwN)
 | AMS117-ADJ-8V | 1 | 0.99 |  | 20 | Aliexpress (https://s.click.aliexpress.com/e/_9x7Ew5)
 | AMS1117-5 | 1 | 0.99 |  | 20 | Aliexpress (https://s.click.aliexpress.com/e/_A60xMl)
 | Кнопки 4x4х3.5 мм | 7 | 1.67 | 0.74 | 50 | Aliexpress (https://s.click.aliexpress.com/e/_9HYNvf)
 | BN-43-302 | 1 | 0.80 |  | 1 | cqradio.ru (http://cqradio.ru/products/bn-43-302)
 | BN-43-202 | 1 | 0.94 |  | 1 | cqradio.ru (http://cqradio.ru/products/bn-43-202)
 | FT23-43 | 1 | 0.25 |  | 1 | cqradio.ru (http://cqradio.ru/products/ft-23-43)
 | T37-6 | 3 | 0.80 |  | 3 | cqradio.ru (http://cqradio.ru/products/t37-6)
 | RD16 | 2 | 8.00 |  | 2 | CihpDip (https://www.chipdip.ru/product/rd16hhf1-101?from=suggest_product)
 | RD01 | 2 | 1.95 |  | 5 | Aliexpress (https://s.click.aliexpress.com/e/_A4k9sN)
 |  |  | 39.91 | 3.26
Разное
 | Корпус | 1 | 10.38 |  | 1 | Aliexpress (https://s.click.aliexpress.com/e/_ADzTtP)
 | Динамики AIYIMA, 27 мм | 1 | 5.04 | 1.46 | 2 | Aliexpress (https://s.click.aliexpress.com/e/_A2uQWH)
 | Валкодер EC11 | 1 | 1.97 |  | 5 | Aliexpress (https://s.click.aliexpress.com/e/_A7EsjB)
 | Валкодер ENS1D-441-M00128 | 1 | 14.25 |  | 1 | Aliexpress (https://aliexpress.ru/item/1005003171237807.html?bizType=ProductDetail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)
 | Дисплей 1.8, 128x160 | 1 | 4.19 |  | 1 | Aliexpress (https://aliexpress.ru/item/32996979276.html?item_id=32996979276&sku_id=67278796295)
 | Тангента MH-48 | 1 | 10.15 |  | 1 | Aliexpress (https://aliexpress.ru/item/1005001706845338.html?sku_id=12000017235262329)
 | U.FL-R-SMT | 4 | 0.70 | 0.80 | 10 | Aliexpress (https://s.click.aliexpress.com/e/_AOLDKD)
 | Кабель 10см IPEX U.fl | 2 | 4.87 |  | 10 | Aliexpress (https://s.click.aliexpress.com/e/_ACJlXT)
 | UHF SO-239 | 1 | 0.48 | 0.63 | 1 | Aliexpress (https://s.click.aliexpress.com/e/_AUVL2p)
 | ESP8266 ESP-07 | 1 | 1.50 | 0.20 | 1 | Aliexpress (https://s.click.aliexpress.com/e/_A6cNcd)
 | Диоды LL4148 | 5 | 0.53 | 0.37 | 50 | Aliexpress (https://s.click.aliexpress.com/e/_AOTU3P)
 | Конденсаторы 100n |  | 15.71 |  | 4000 | Aliexpress (https://s.click.aliexpress.com/e/_A1oQBJ)
 | Диоды SS14 | 3 | 1.28 | 0.76 | 100 | Aliexpress (https://s.click.aliexpress.com/e/_9IueWH)
 | Набор плат + активация |  | 55.00 |  |  | Telegramm (https://t.me/Wolf_X1)
 |  |  | 126.05 | 4.22

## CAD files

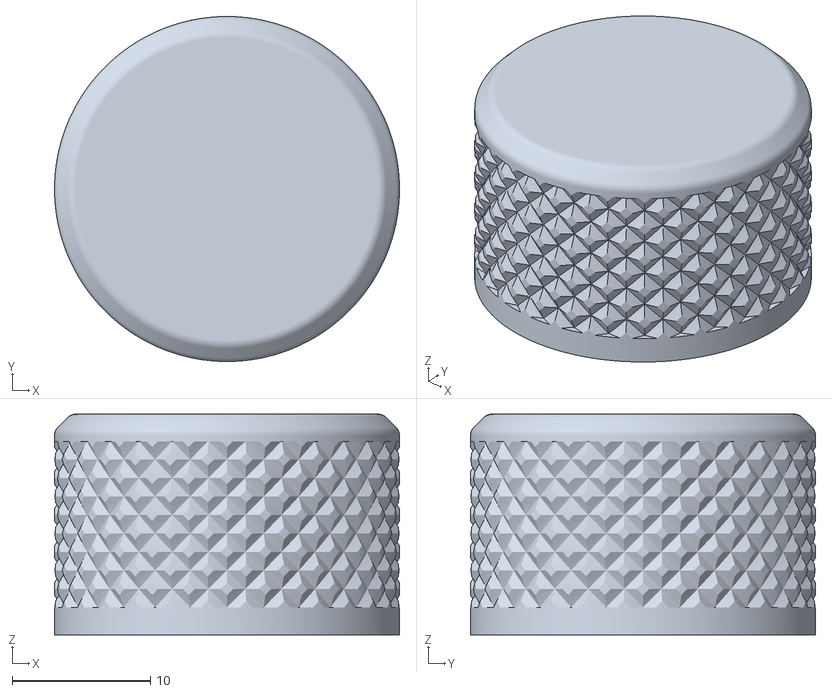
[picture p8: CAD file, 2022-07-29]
Schematic/Wolf-X1/Addons/20mm_Main_Encoder.stl
25.0 x 25.0 x 16.0

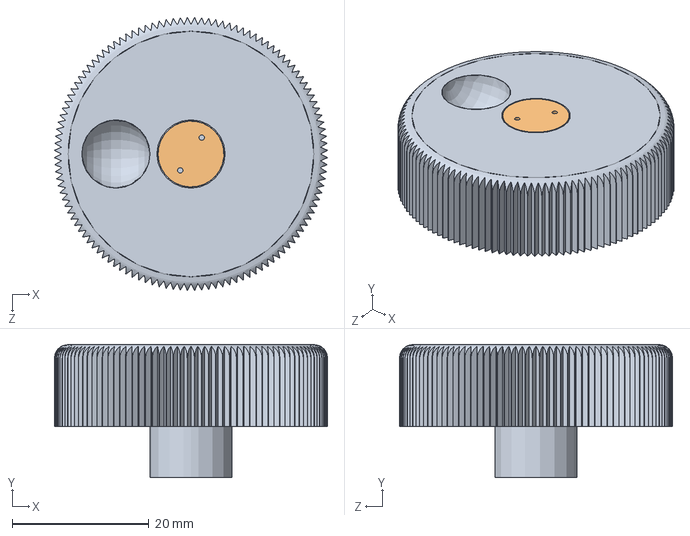
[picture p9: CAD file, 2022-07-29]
Schematic/Wolf/CASE/3'2/3DPrinter/case/shuttle_knob_construct.SLDASM
40.0 x 19.5 x 40.0 mm
shuttle_knob
shuttle_knob_cap

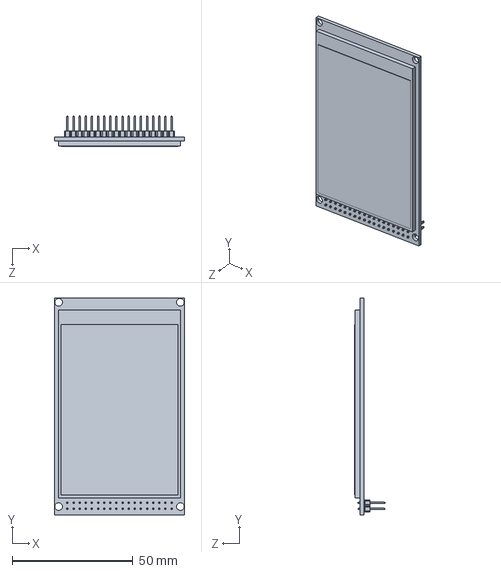
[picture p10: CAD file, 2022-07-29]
Schematic/Wolf/CASE/3'2/3DPrinter/Display480x320.SLDASM
54.1 x 90.0 x 12.6 mm

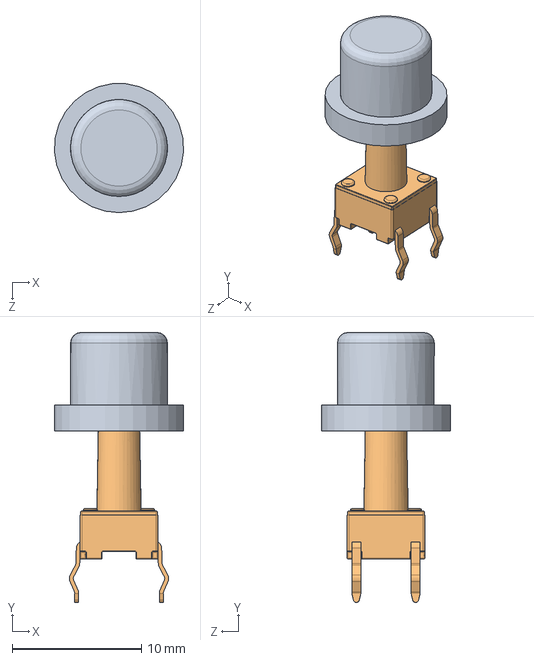
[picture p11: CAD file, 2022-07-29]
Schematic/Wolf/CASE/3'2/3DPrinter/case/button_construct.SLDASM
9.99 x 20.9 x 10.0 mm
button
tactileswitch-long

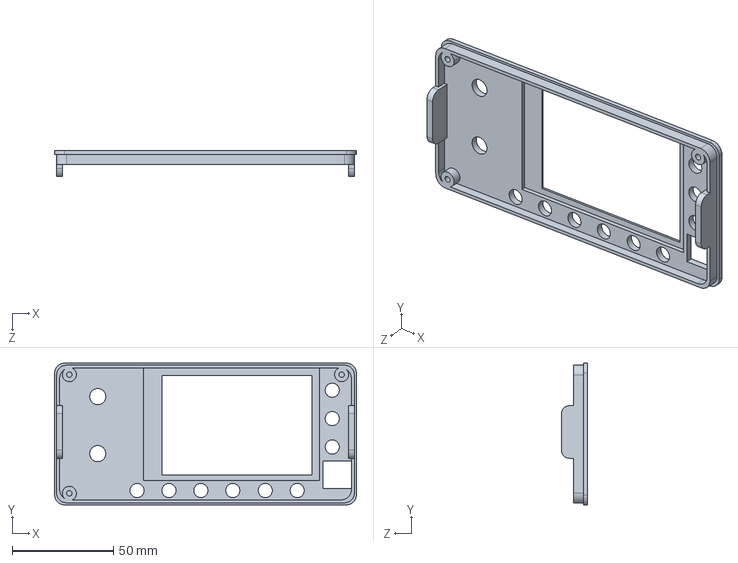
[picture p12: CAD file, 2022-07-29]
Schematic/Wolf-Lite/Case/Front Lite V2.SLDPRT
149.0 x 70.0 x 13.0 mm

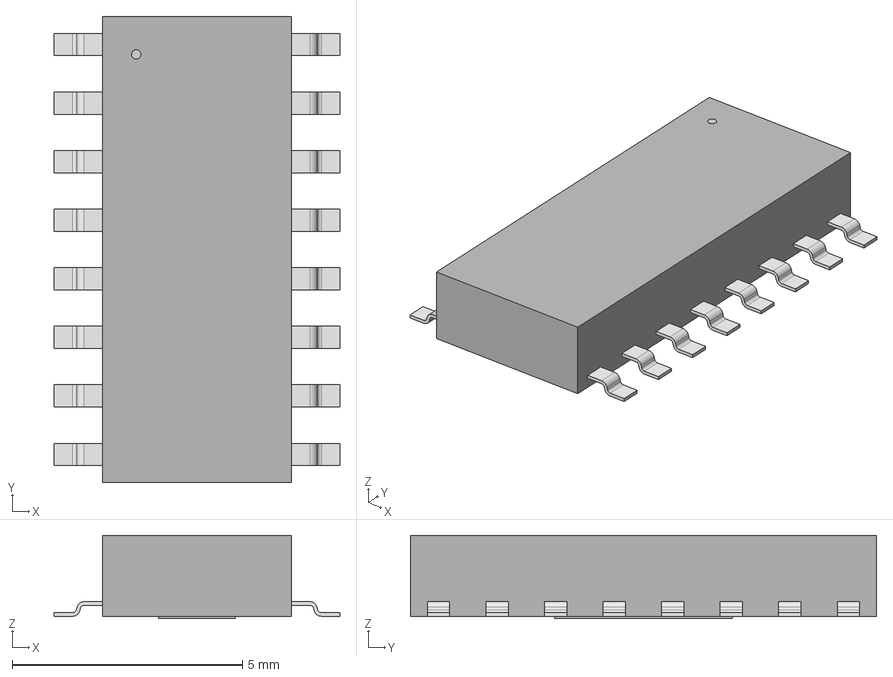
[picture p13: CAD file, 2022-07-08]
Schematic/Wolf/Altium_Designer/Mod-LZ1HAA-hardware/FRONT-UNIT-7/3d/PAM8406ER_DIO.step
6.20 x 10.1 x 1.81 mm

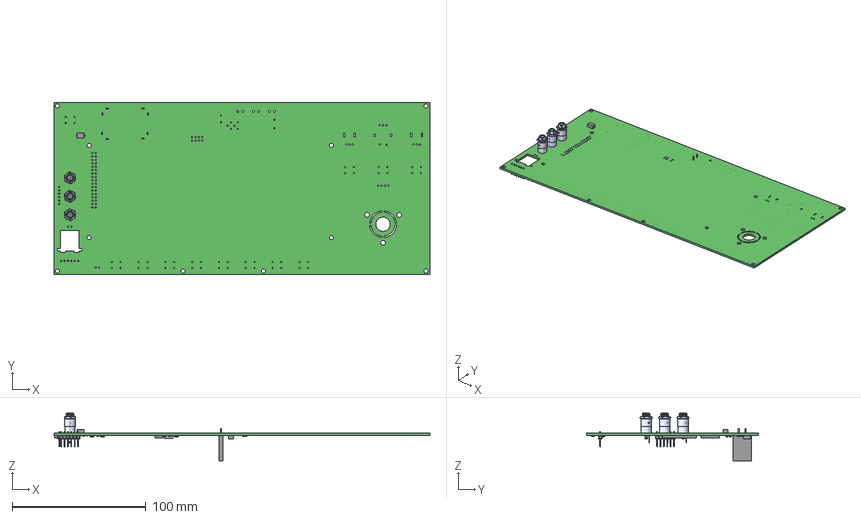
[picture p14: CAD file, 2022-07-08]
Schematic/Wolf/Altium_Designer/Mod-LZ1HAA-hardware/FRONT-UNIT-7/FRONT-UNIT-7.step
281.0 x 128.5 x 35.8 mm
Pins x 4
прямой_штырь x 14
основание x 14
front_metal.STEP x 3
mid_plastic.STEP x 3
pin.STEP x 3
nut________.STEP x 3
SW3dPS-0805_SMD_Capacitor x 2
chip_0805_r x 2
SOT23-5-1 x 2
Extruded x 14
term1
term2
Leads x 2
FilletPinL x 2
FilletPinR x 2

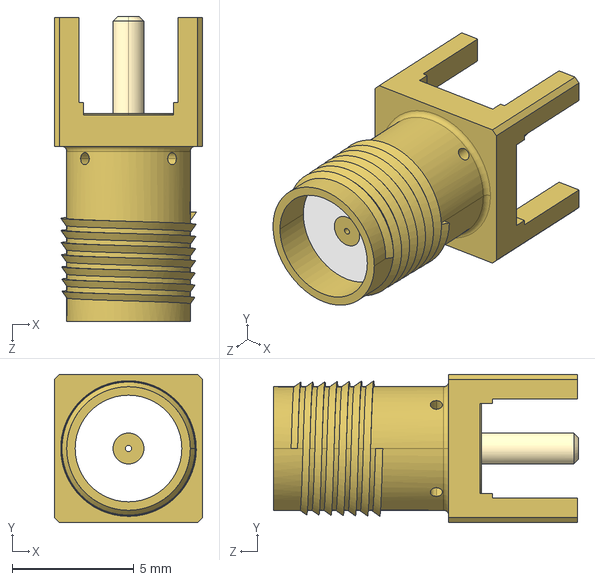
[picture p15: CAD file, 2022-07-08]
Schematic/Wolf/Altium_Designer/Mod-LZ1HAA-hardware/MOTHERBOARD/3d/conn-jack-sma-str-molex-73391-0060-rf-slash-coaxial/Molex - 73391-0060.STEP
6.08 x 6.08 x 12.6 mm

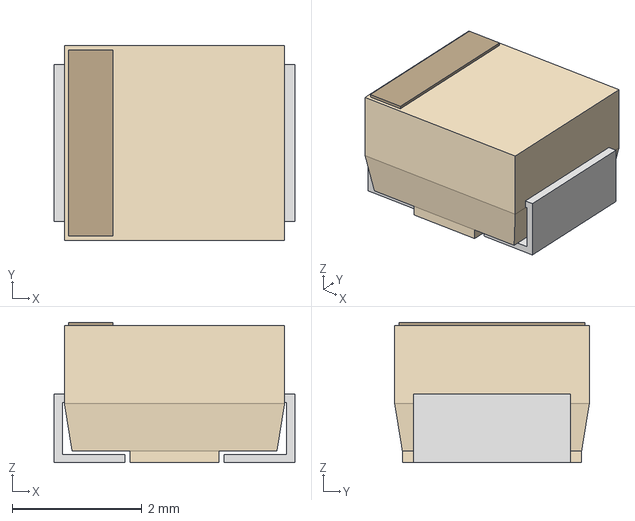
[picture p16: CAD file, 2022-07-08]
Schematic/Wolf/Altium_Designer/Mod-LZ1HAA-hardware/MOTHERBOARD/3d/TAJB_AVX.step
3.71 x 3.00 x 2.16 mm

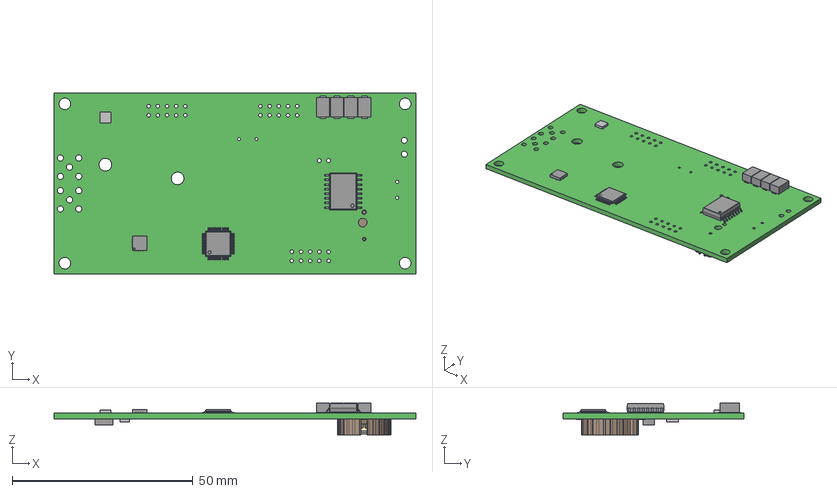
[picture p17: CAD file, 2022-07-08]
Schematic/Wolf/Altium_Designer/Mod-LZ1HAA-hardware/MOTHERBOARD/MOTHERBOARD_Hristo_JLC2313.step
100.0 x 50.0 x 8.79 mm
S841-HOLDER
S841-LOWER-CONTACT
S841-REAR-CONTACT
Pins x 5
ThermalPin
PinsArrayLR x 3
PinsArrayTB x 2
ThermalPad
Extruded x 2

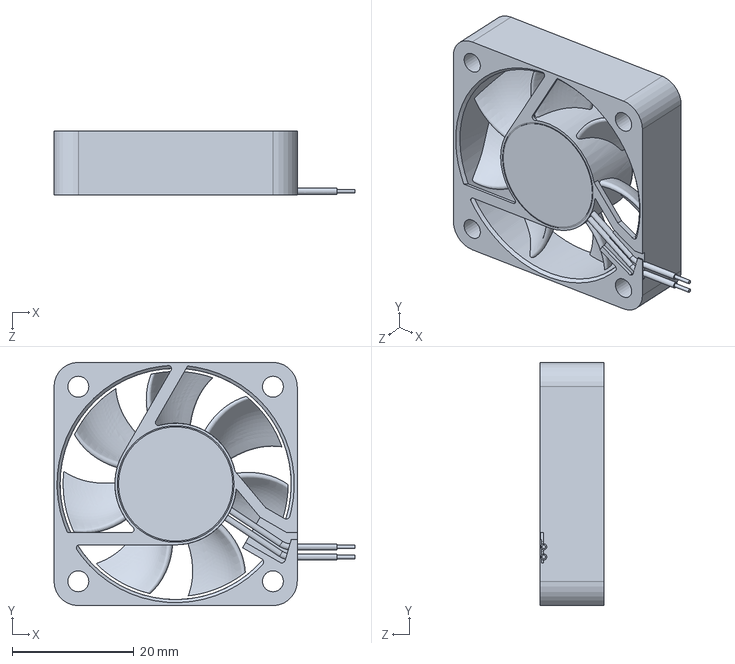
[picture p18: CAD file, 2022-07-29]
Schematic/Wolf/CASE/3'2/3DPrinter/40x40x10 DC Fan.SLDPRT
49.5 x 40.0 x 10.5 mm

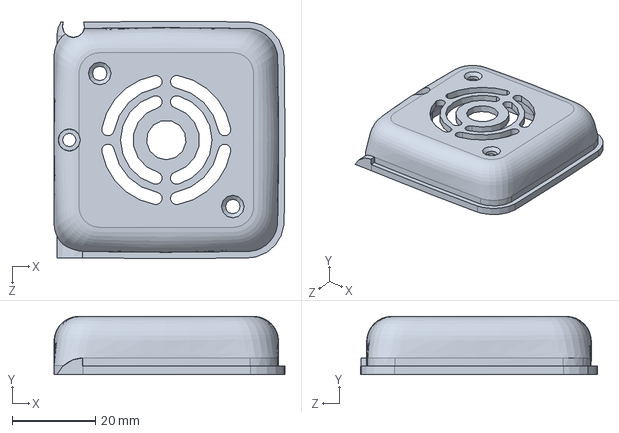
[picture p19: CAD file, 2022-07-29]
Schematic/Wolf/CASE/3'2/3DPrinter/case/case_cooller.SLDPRT
55.5 x 14.0 x 57.1 mm

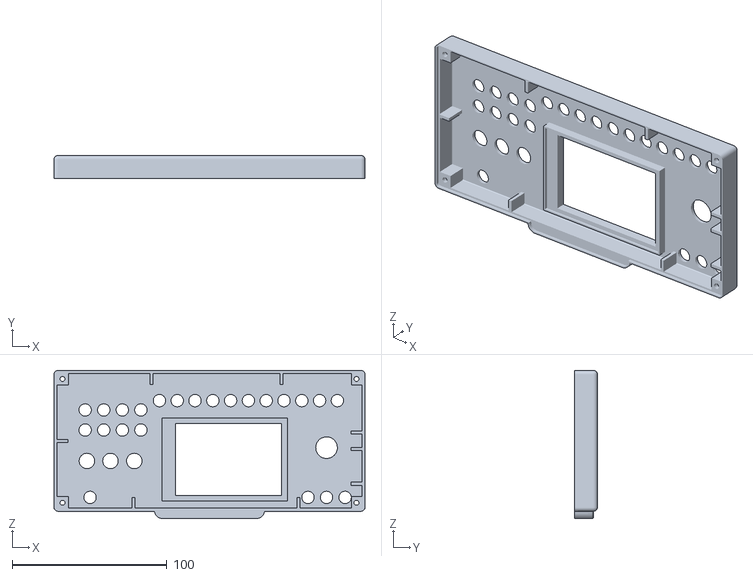
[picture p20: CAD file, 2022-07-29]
Schematic/Wolf/CASE/3'2/3DPrinter/STL/case_front.STL
201.0 x 14.8 x 95.7

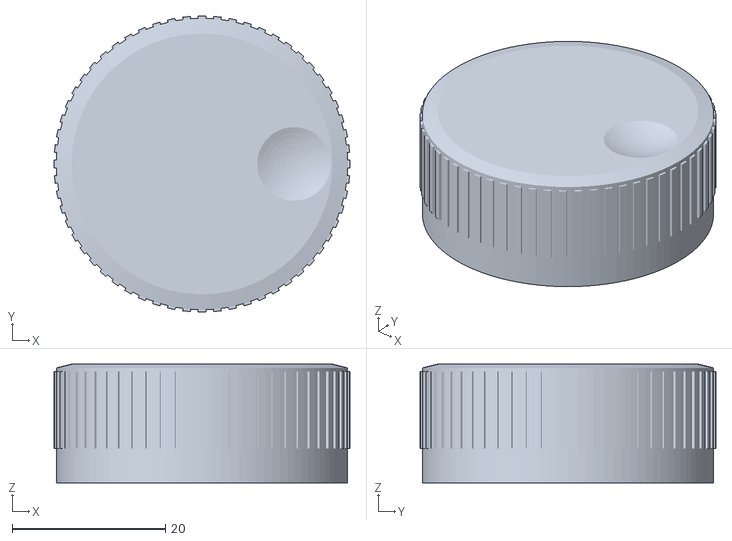
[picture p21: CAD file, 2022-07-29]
Schematic/Wolf/CASE/VFO/VFO_38mm.stl
38.6 x 38.6 x 15.5

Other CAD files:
Schematic/Wolf/CASE/3'2/3DPrinter/KY-040 Rotary Encoder.SLDASM
Schematic/Wolf-Lite/Case/BOT-LITE.SLDPRT
Schematic/Wolf-X1/Addons/Milling_Top.DWG
Schematic/Wolf/Altium_Designer/Mod-LZ1HAA-hardware/FRONT-UNIT-7/3d/SSOP28_10P2X5P3X1P75_CIR.step
Schematic/Wolf-Lite/Altium_Designer/Front-Unit/Wl-FRONT-EDM/16-SOIC_MCP3008-I_SL.x_t
Schematic/Wolf-Lite/Altium_Designer/Front-Unit/Wl-FRONT-EDM/BAT__CH224-2032_POWER_BAT.x_t
Schematic/Wolf-Lite/Altium_Designer/Front-Unit/Wl-FRONT-EDM/BUT__6x6_SMD_Tactile_switches.x_t
Schematic/Wolf-Lite/Altium_Designer/Front-Unit/Wl-FRONT-EDM/BUT__6x6_Tactile_switches.x_t
Schematic/Wolf-Lite/Altium_Designer/Front-Unit/Wl-FRONT-EDM/CH0805C_Capacitor.x_t
Schematic/Wolf-Lite/Altium_Designer/Front-Unit/Wl-FRONT-EDM/CH0805R_Resistor.x_t
Schematic/Wolf-Lite/Altium_Designer/Front-Unit/Wl-FRONT-EDM/CON__PLS-5_5-Connector.x_t
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

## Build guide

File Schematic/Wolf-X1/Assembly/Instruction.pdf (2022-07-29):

Инструкция по сборке трансивера Wolf X1

Трансивер Wolf X1 является совместной разработкой UA3REO и R7KBI автор не несет ответственность за не качественные комплектующие в случае если у Вас не запустился трансивер с первого раза, в случае если не работает какой то узел, обращается нужно в телеграмм чат https://t.me/TRX_Wolf четко изложить проблему, по возможности приложить фотографии не работающего узла или участка, либо записать коротенькое видео.

При правильной сборке и не бракованных комплектующих, вся наладка сводится на проверку АЧХ полосовых фильтров, ФНЧ. Установку токов покоя на транзисторы VT4, VT6 (RD16HHF1) выходного каскада и установку опорного напряжения U5 RA08H1317M. На этом при правильной сборке вся наладка заканчивается. Остается только калибровка в меню настроек.

Ниже я опишу сборку MAIN платы, так как это собирал я R7KBI Вы в праве нарушить алгоритм сборки как посчитаете лучше для Вас, но рекомендую следовать инструкции.

### 1. В первую очередь необходимо запаять dc-dc, U14 ST1S10 с AliExpress это

«Русская рулетка» я бы по советовал либо искать проверенного продавца или искать в местных магазинах. Это довольно ответственный узел, если пробьет U14 она за собой потянет другие узлы. Необходимо убедится, что на выходе ST1S10 было не больше 5V, это важно!!!

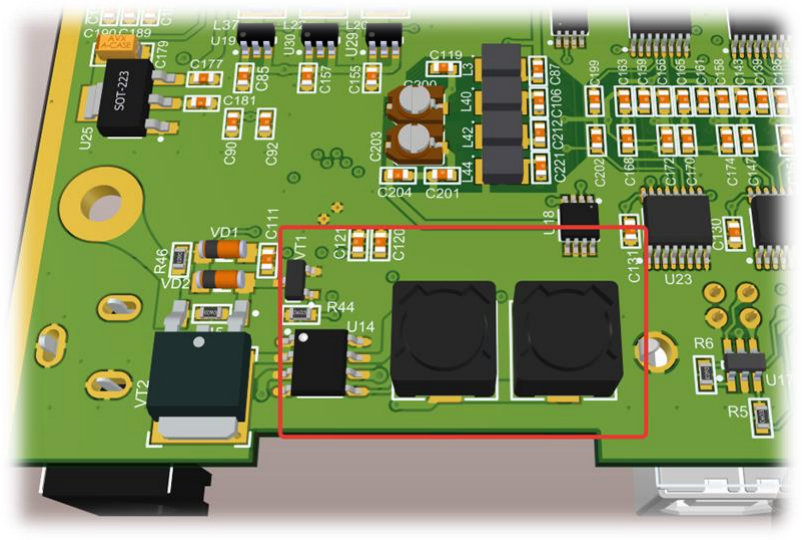
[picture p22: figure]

Рисунок – 1

### 2. Вторым этапом запаять dc-dc U19, U29, U30. Микросхемы SC189 бывают

на напряжения, которые указаны в таблице, нас интересуют в корпусе SOT23-5.

Для питания U4 EP4CE22E22C8N, необходима три напряжения 1.2V, 2.5V, 3.3V. Можно применить U19 SC189CSKTRT, U29 SC189YSKTRT, U30 SC189ZSKTRT, но в этом случае резисторы R34, R3, R4 не устанавливать, а резисторы R53, R48, R52 заменить на нулевые (перемычки). На момент написания данной инструкции, я не смог найти по оптимальной цене с нужным индексом данные микросхемы, поэтому можно применить SC189ASKTRT или SC189CSKTRT в этом случае устанавливаем делители на резисторах согласно схеме.

Индуктивности должны быть силовые, но по высоте есть конструктивные ограничения, (это касается всех компонентов, которые находятся на нижнем слое платы MAIN) не выше 5мм.

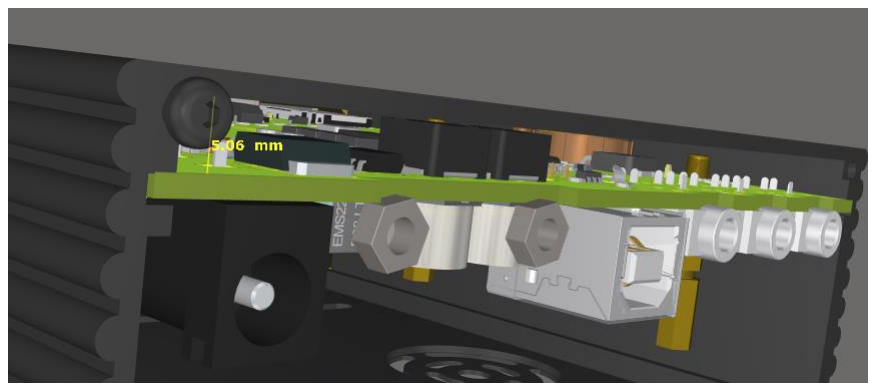
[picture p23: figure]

Рисунок – 2

После установки необходимо проверить выходные напряжения, они должны быть строго как на схеме 1.2V, 2.5V, 3.3V в ином случае можно сжечь U4 EP4CE22E22C8N.

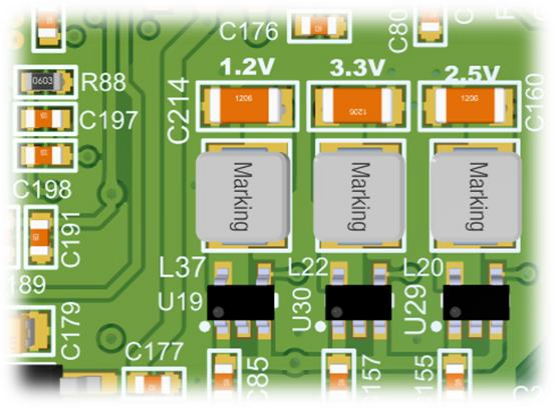
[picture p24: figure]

Рисунок – 3

3. Следующим | этапом | можно | распаивать | линейные | стабилизаторы
напряжения. Обратите внимания для питания STM32H743VIT6 и периферии применяется на выбор понижающие стабилизаторы, U13 LM1085-3.3 или U31 SC189 (смотрите пункт 2 по обвязке). Тут вы сами определяйтесь какой применить dc-dc или линейный стабилизатор, я испробовал два варианта оба отлично за рекомендовали и у обоих есть свои плюса.

Смотря что, Вы выбрали, к примеру U13, в этом случае обвязку U31 распаивать не нужно (смотрите схему).

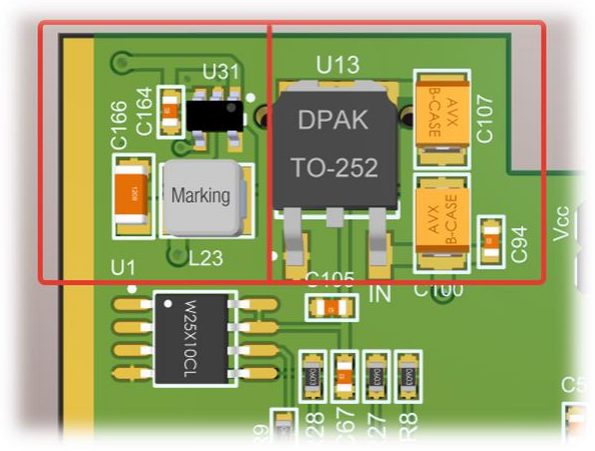
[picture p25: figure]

Рисунок – 4

### 4. После установки всех стабилизаторов напряжения, приступаем к установке

всех блокировочных конденсаторов 0.1мкф (100n). Почему именно с них следующий этап!? Да все просто, лично я не раз попадал на конденсаторы, которые в КЗ (коротком замыкании) поэтому я рекомендую, запаивать партиями, то есть – запаять штук 10, подать питание, если все нормально идем дальше, пока все не установите. В ином случае если не повезет, может оказаться один в КЗ, в этом случае будет сложно найти какой из 93 штук.

Примечание

Не запаивайте гнезда под наушники, микрофон и телеграфный ключ. Обосную почему я рекомендую их установить в самом конце сборки – дело в том, что Вам придется работать с паяльным феном, и эти гнезда расплавятся от высокой температуры. Но учтите, что без гнезда J2 под наушники не будет звука в динамике.

### 5. После проделанных 4 пунктов, можно устанавливать компоненты, которые

есть в наличии, но первые 4 пункта настоятельно рекомендую соблюсти, во избежание проблем с выхода из строя дорогостоящих компонентов.

Обратите внимание на крепежное отверстие для латунной стоки с нижней правой стороны

Рисунок – 5

Через данную стойку поступает напряжение на плату UM поэтому будьте внимательны, когда под стойку установите шайбу, что бы она не была большого размера и не замкнулась с земляным полигоном. И рекомендую на бронзовую стойку одеть термоусадку.

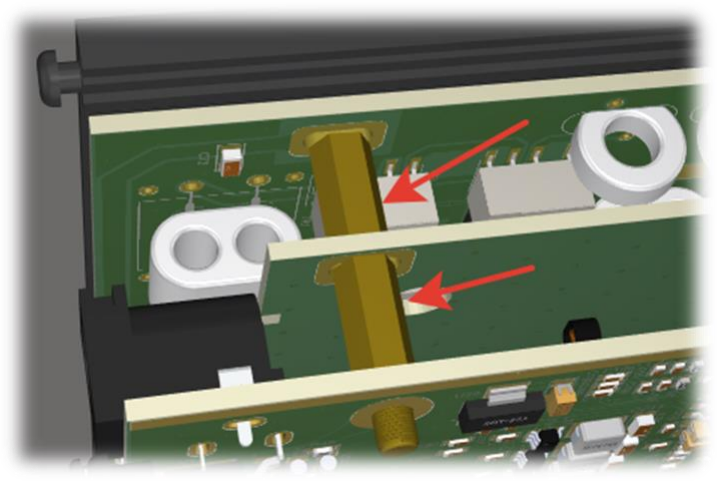
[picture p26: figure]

Рисунок – 6

После сборки можно приступить к прошивке трансивера, последовательность что прошивать в первую очередь не имеет значения.

Чтобы первый раз прошить STM32H743VIT6 есть два способа.

- При помощи программатора ST-Link
- Через USB

Второй способ через USB более универсальный, не нужны ни какие программаторы, просто подключаем трансивер через USB шнур к компьютеру, замыкаем перемычку J1 BOOT рис. 7 и подаем питание на плату MAIN при этом удерживаем кнопку включения, но ею будет не удобно воспользоваться если трансивер не полностью собран, По этому

Рисунок – 7

Нужно исключить узел, отвечающий за включение рис. 8 Или лучше даже посадить на землю пин on/off на разъеме X7 рис. 7.

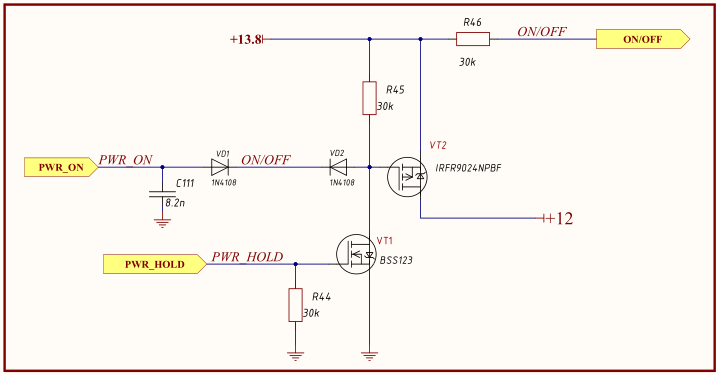
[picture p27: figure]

Рисунок – 8

И подать питание на прямую на сток транзистора VT2 это фланец транзистора рис. 9.

Рисунок – 9

После проделанной процедуры трансивер определите на компьютере и при помощи программы STM32CubeProgrammer (скачать можно с официального сайта https://www.st.com она бесплатная, нужна только регистрация)

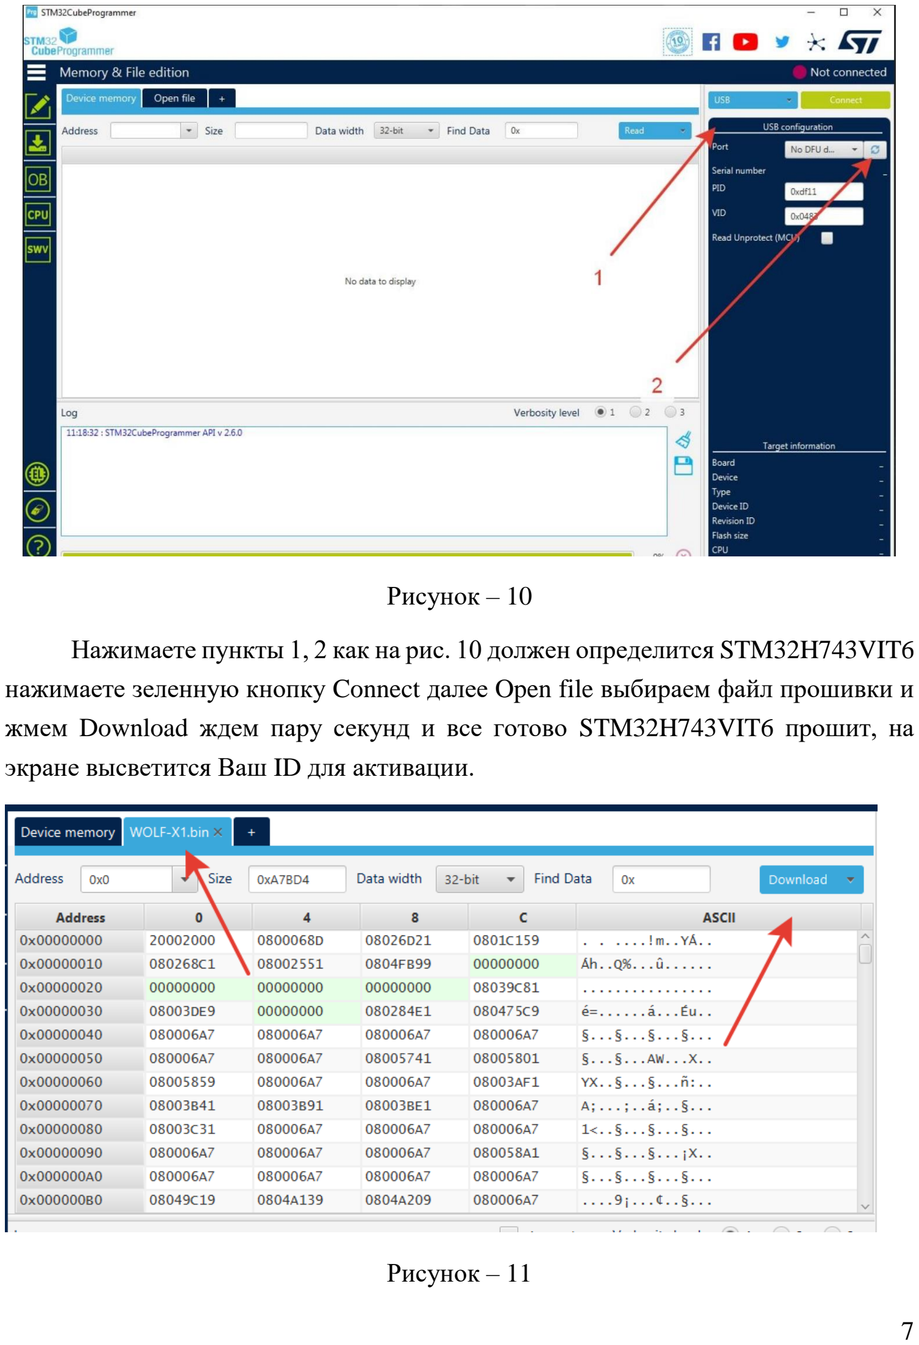
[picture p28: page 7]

Рисунок – 10

Нажимаете пункты 1, 2 как на рис. 10 должен определится STM32H743VIT6 нажимаете зеленную кнопку Connect далее Open file выбираем файл прошивки и жмем Download ждем пару секунд и все готово STM32H743VIT6 прошит, на экране высветится Ваш ID для активации.

Рисунок – 11

Данную процедуру прошивки необходимо провести только в случае, если прошиваете первый раз, в последующие обновления это не понадобится, можно будет прошиться через WI-Fi, или файловые менеджер, предварительно загрузив прошивку на SD карту.

Прошивка FPGA |

Как проверить АЧХ ДПФ!? Да есть некоторые сложности из-за тесноты компоновки. Есть два способа:

- На выключенной плате MAIN, но при этом не запаянные ключи U21, U22, U23, U24, U12, U18
- На включенном и полностью собранной плате MAIN

Первый вариант не совсем удобен, но в этом ключи не будут вносить затухания это, как и плюс так и минус.

Второй способ более правильный, в этом случае необходимо исключить конденсатор С122 что бы он не садил сигнал через трансформатор T1.

Необходимо под паятся кабелями от измерительного прибора (к примеру NanoVNA) к резисторам R65, R70 к верхней части как на рис. 12, а минусовой в любом удобном месте. После проверки АЧХ желательно продублировать процедуру, но уже проверить сквозное АЧХ от антенного гнезда и до входа трансформатора T1, но это не обязательно.

Особое внимание уделите полосовому фильтру на 144мГц от точности настройки зависит чувствительно приема на диапазоне 2М (145мГц) или вообще может отсутствовать прием.

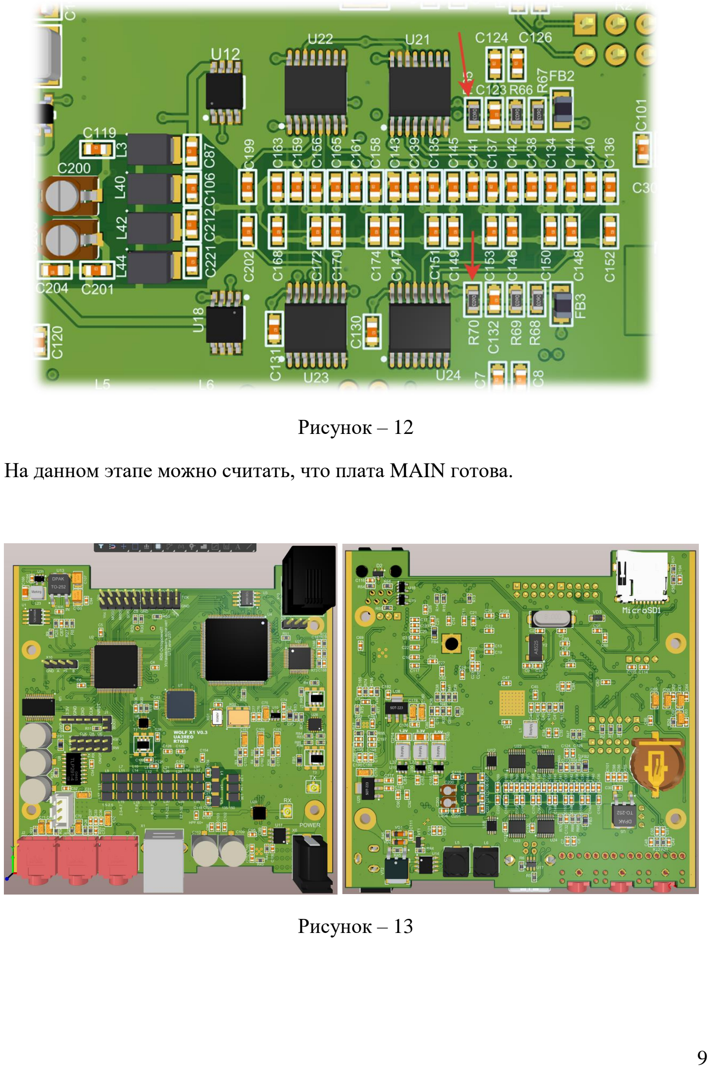
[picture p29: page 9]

Рисунок – 12

На данном этапе можно считать, что плата MAIN готова.

Рисунок – 13

СБОРКА «СРЕДНЕЙ» ПЛАТЫ

она служить для экранирования платы UM от платы MAIN, а также для соединения платы MAIN с платой UM, и на ней размещен модуль WI-FI.

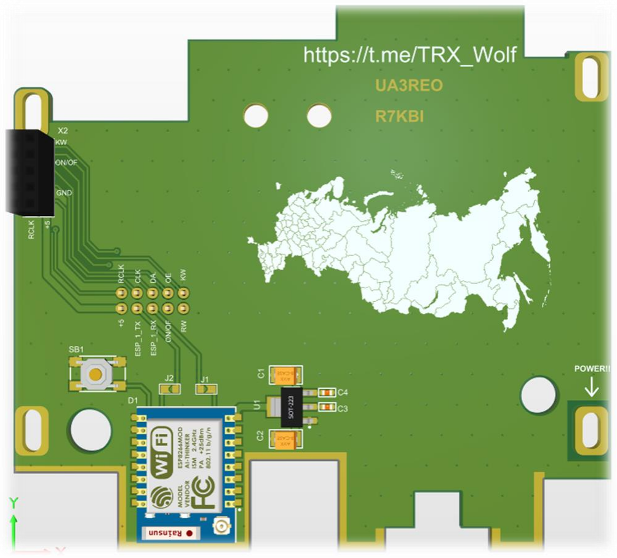
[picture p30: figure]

Рисунок – 14

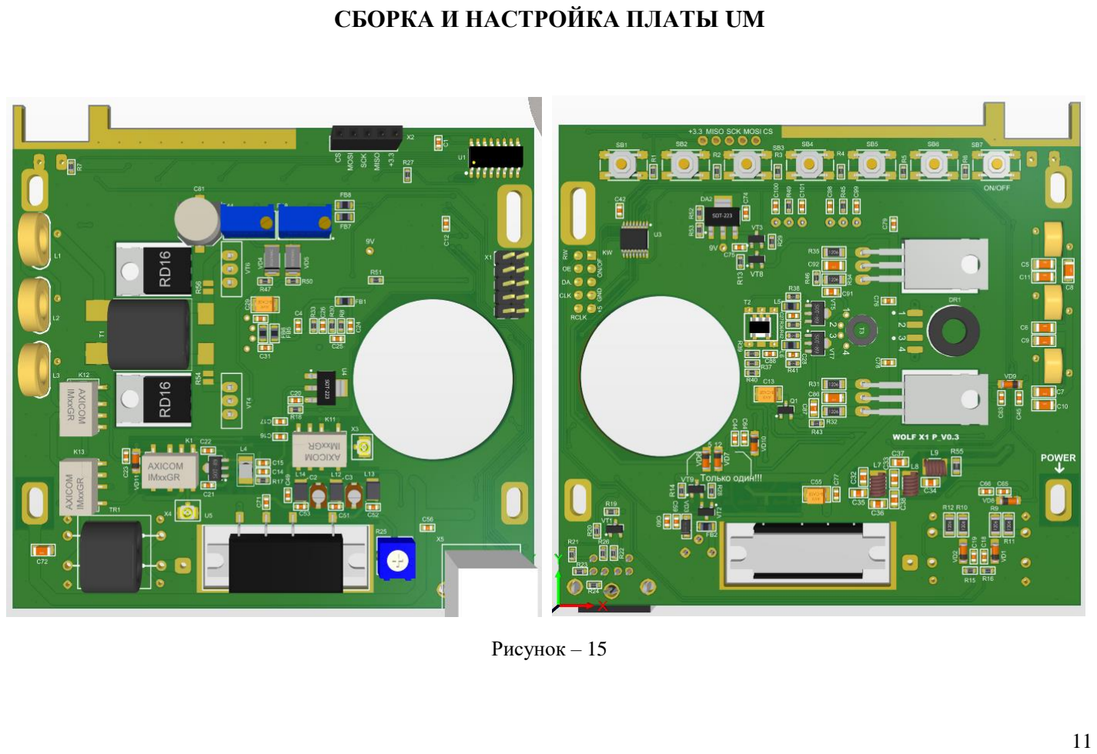
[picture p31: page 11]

11

СБОРКА И НАСТРОЙКА ПЛАТЫ UM

Рисунок – 15

Сборка UM не привязана к последовательности, можно запаивать что есть в наличии. Тут только нужно настроить токи покоя для транзисторов VT4, VT6, и установить напряжение на выводе VGG (2 пин) модуля U5 RA08H1317M построечным резистором R25, оно должно соответствовать графику на конкретный модуль, для примера график на рис.16

Не гонитесь за большой мощностью не нужно «стрелку ложить»

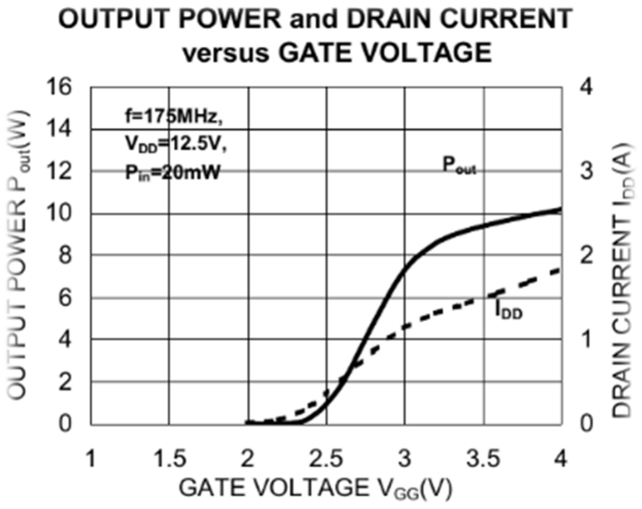
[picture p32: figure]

Рисунок – 16

Проще всего настроить токи покоя для VT4, VT6, которое должно составлять 200ма на каждый, это отвязать плату UM от MAIN от лабораторного источника питания подать напряжение 13.8V через миллиамперметр на переходное отверстие которое является (как рассказывал в пункте 5 ) рис. 17

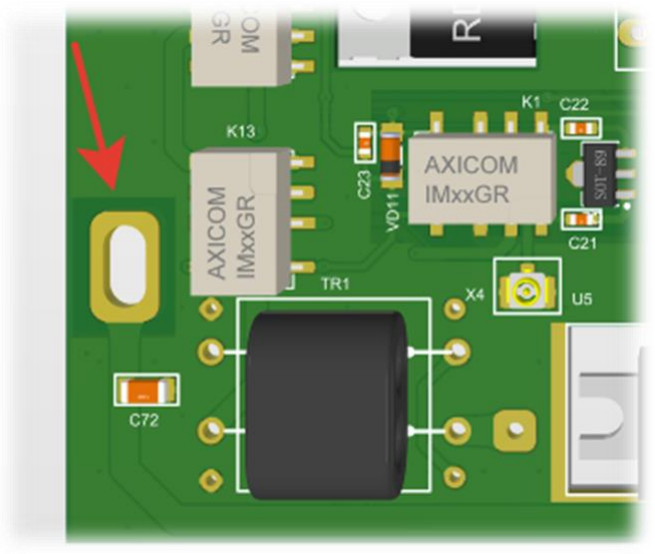
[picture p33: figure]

Рисунок – 17

Далее, чтобы перевести плату в режим TX необходимо запаять перемычку на стабилизатор DA2, подать на прямую напряжение как на рис. 18-19

Рисунок – 18

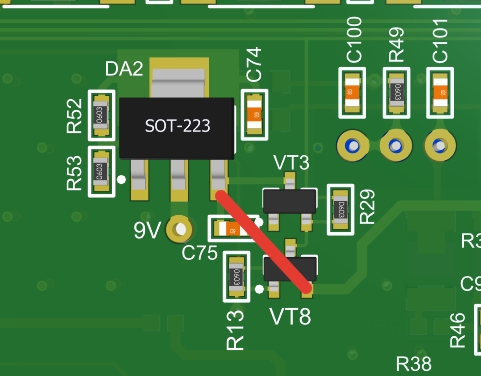
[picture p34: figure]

Рисунок – 19

К выходному трансформатору подключить эквивалент нагрузки 50 Ом. Подстроечные резисторы R44, R48 выкрутить в нулевое положение, и при подаче напряжения показания миллиамперметра должно показать потребление 20ма, по очереди выкручивая движки подстрочных резисторов установить на каждом транзисторе 200ма, учитывая потребление самой платы, должно получится на одном плече 220ма, и при подстройке на втором общее потребление 420ма.

В ревизии платы UM V0.3 рис.20 добавил джампера для установки токов покоя в этом случае можно не учитывать общее потребление платы, после установки токов покоя джампера J1, J2 нужно замкнуть каплей припоя

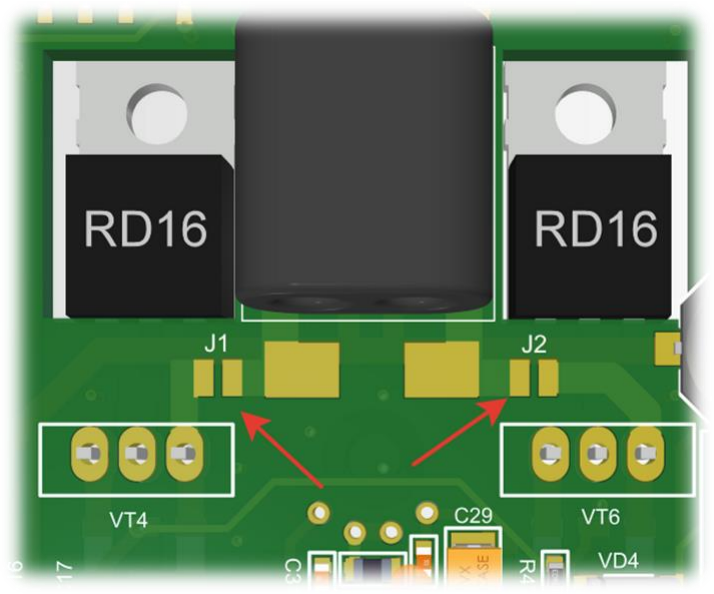
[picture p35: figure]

Рисунок – 20

Не забываем еще снять АЧХ с ФНЧ. Я применял самодельные катушки, рассчитать индуктивность можно в онлайн калькуляторе . (https://coil32.ru/calc/one-layer.html)

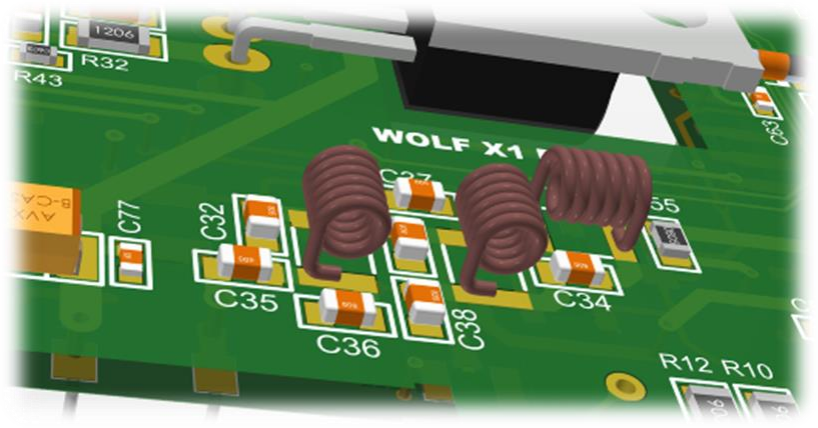
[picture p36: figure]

Рисунок – 21

На этом сборка и настройка платы UM завершена.

КРЕПЛЕНИЕ ДИСПЛЕЯ К ЛИЦЕВОЙ ПАНЕЛИ

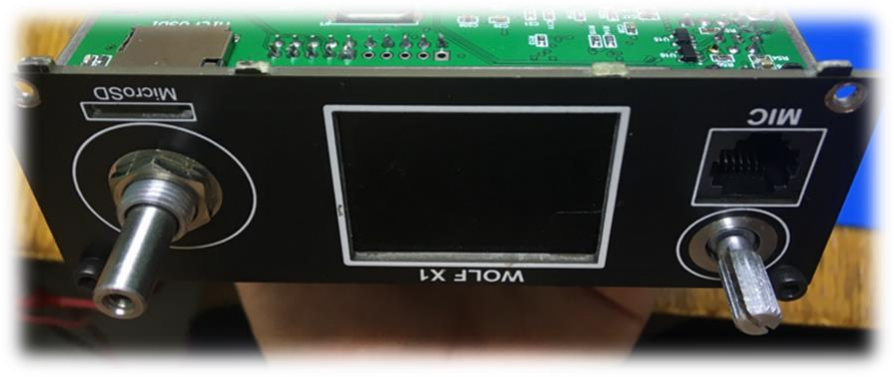
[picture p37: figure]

Рисунок – 22

Тут ничего хитроумного нет 😊позиционируем и лужёным проводом фиксируем.

В процессе наладки можно использовать длинные провода от дисплея, а при финишной сборке необходимо максимально укоротить во избежание ВЧ наводок.

Дисплей | MAIN

GND –––––––––––––––– GND
VDD –––––––––––––––– Vcc
SCL –––––––––––––––– SCK
SDA –––––––––––––––– MOSI
RES соединить с VDD
DC –––––––––––––––– MISO
CS –––––––––––––––– CS
BLK не задействуется

СБОРКА ПЛАТ В ОДИН «БУТЕРБРОД» И УСТАНОВКА В КОРПУС

Рисунок – 23

Расстояние нижней платы MAIN от верхнего слоя и до нижнего слоя платы UM должно быть 23мм рис.24

Рисунок – 24

Я применял латунные стойки длиной 10мм рис. 25 две стойки с учетом толщины средней платы 1.6мм получается 21.6мм отставшие 1.4мм подогнал шайбами.

Рисунок – 25

Когда сложили «бутерброд» можно приступить к сборке его в корпус. Сборка в корпус начинается с платы UM к верхней крышке (в папке с документацией есть файл DWG и PDF с чертежом вырезов в крышке под кнопки, вырез под динамик и крепежные отверстия под транзисторы VT4, VT6, отверстия рассчитаны под транзисторы от центров отверстий в плате, я бы рекомендовал их наметить самостоятельно что бы не промазать. Как это сделать, красим фланцы транзисторов, к примеру лаком для ногтей и прикладываем к крышке, останется след от отверстий, останется просверлить и нарезать резьбу М3. Есть один нюанс, когда будите прикладывать плату для оставления следа, необходима чтобы задний торец платы был на одном уровне с крышкой рис.26

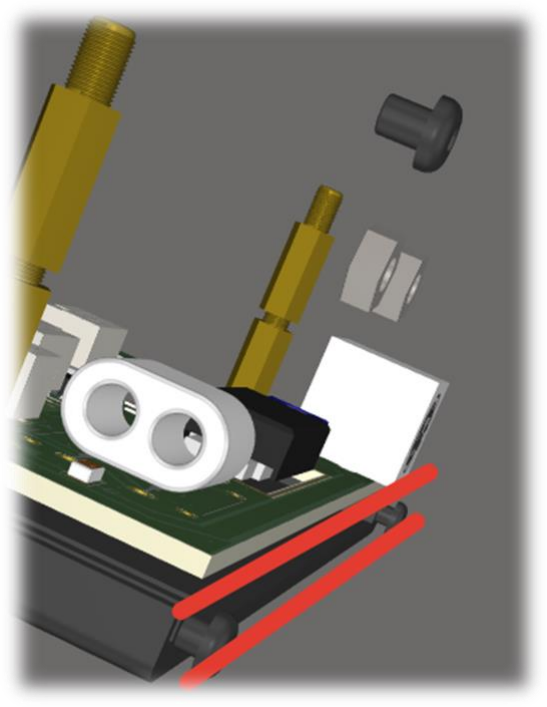
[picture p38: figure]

Рисунок – 26

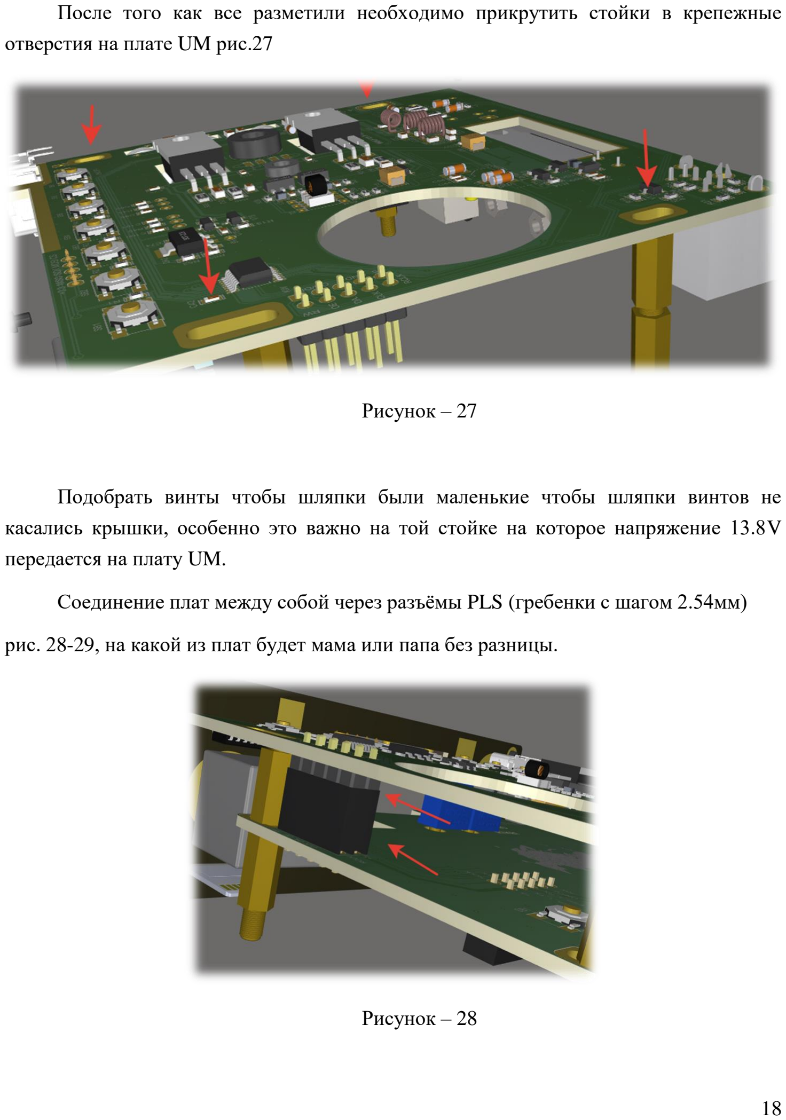
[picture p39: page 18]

После того как все разметили необходимо прикрутить стойки в крепежные отверстия на плате UM рис.27

Рисунок – 27

Подобрать винты чтобы шляпки были маленькие чтобы шляпки винтов не касались крышки, особенно это важно на той стойке на которое напряжение 13.8V передается на плату UM.

Соединение плат между собой через разъёмы PLS (гребенки с шагом 2.54мм)

рис. 28-29, на какой из плат будет мама или папа без разницы.

Рисунок – 28

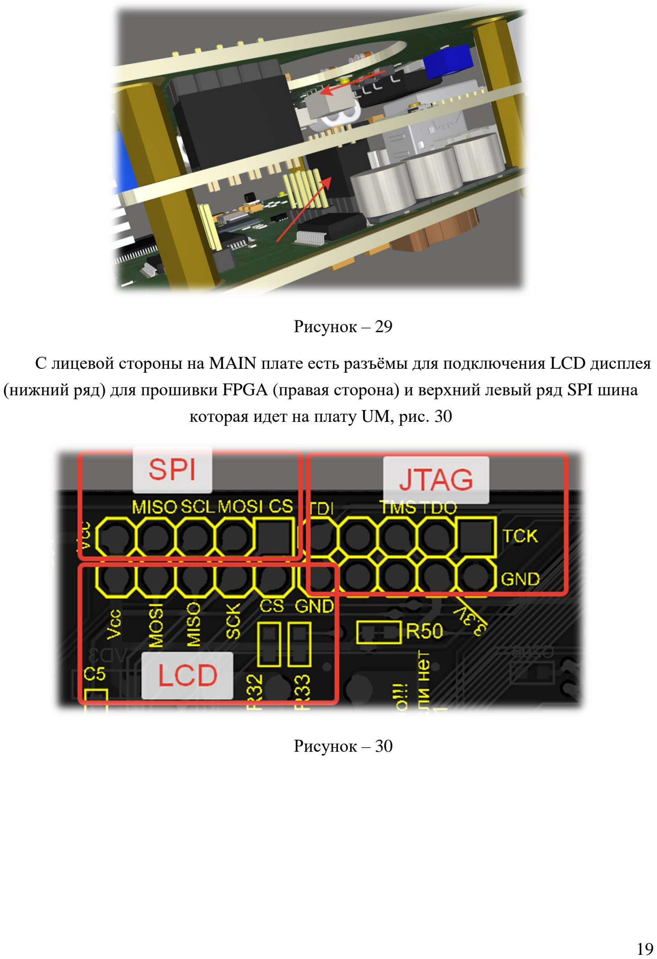
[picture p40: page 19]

Рисунок – 29

С лицевой стороны на MAIN плате есть разъёмы для подключения LCD дисплея (нижний ряд) для прошивки FPGA (правая сторона) и верхний левый ряд SPI шина которая идет на плату UM, рис. 30

Рисунок – 30

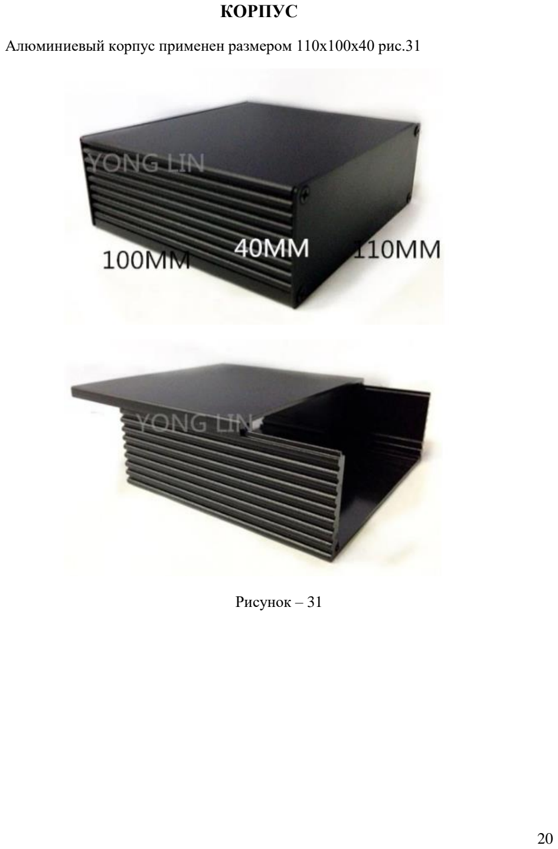
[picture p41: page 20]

КОРПУС

Алюминиевый корпус применен размером 110х100х40 рис.31

Рисунок – 31

ДИНАМИК

В трансивере предусмотрена установка динамика с размерами как на рис. 32

Рисунок – 32

Оставлю ссылки на AliExpress, но на момент написания данной инструкции не обещаю, что они будут активные. Если ссылки не рабочие, поищите по названию SOTAMIA 27мм и AIYIMA 27мм.

### 1. Первая ссылка (https://aliexpress.ru/item/32825276359.html?mp=1&sku_id=64943182055)

2. Вторая ссылка (https://aliexpress.ru/item/4000184341538.html?mp=1&sku_id=10000000678041661)

Можно примерить и другой главное, чтобы поместился в корпусе и был достойное звучание.

ОПТИЧЕСКИЙ ЭНКОДЕР

Энкодер применен ENS1D-441-M00128. Для удобства размещения в корпусе желательно отрезать родной шлейф ближе к энкодеру и запаять мягкий провод, я применил провод МГТФ, но это не принципиально.

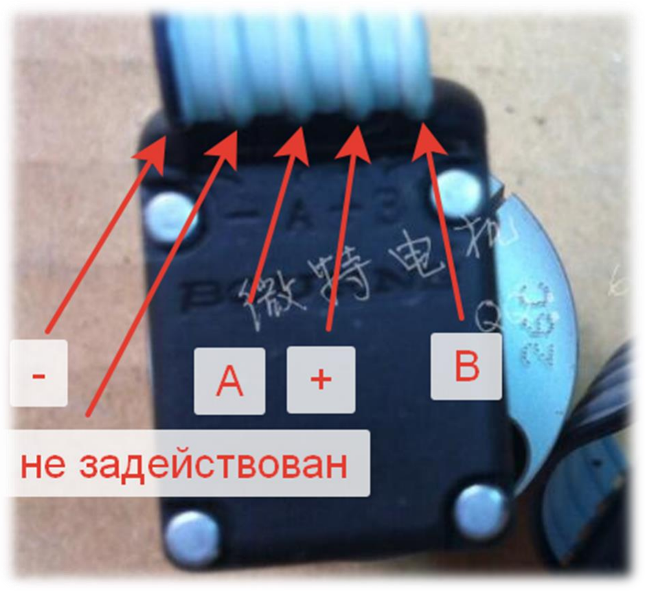
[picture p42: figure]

Рисунок – 33

На рис.33 показана распиновка энкодера, на нем есть не задействованный один проводник, нужно быть внимательным не перепутать при подключении к разъёму X10 на плате MAIN.

Выход EXTERNAL

Гнездо EXTERNAL на задней крышке трансивера, предназначен для управления внешним усилителем мощности. Его можно выпаять из старых материнских плат от ПК, ну или купить новый, а ответную часть, можно срезать от старой клавиатуры или мыши.

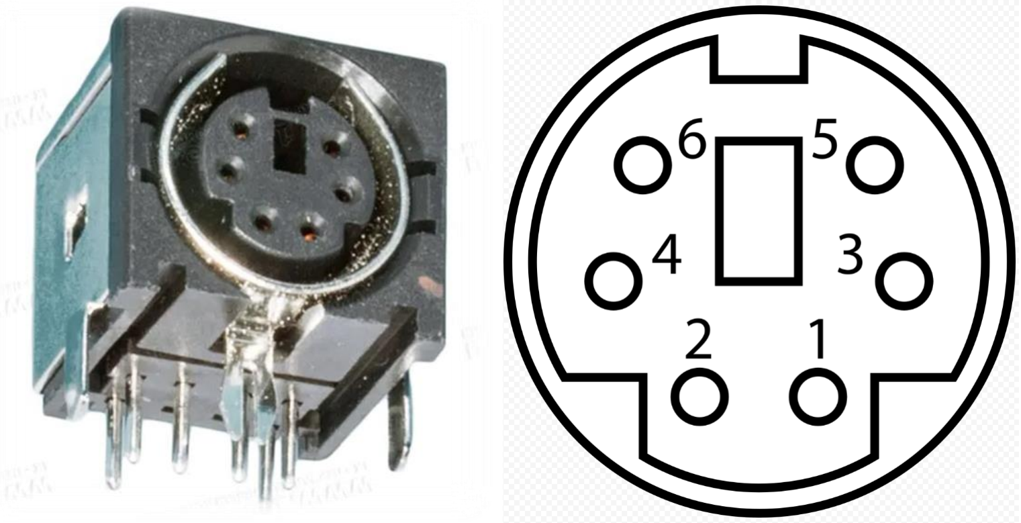
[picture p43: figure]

Рисунок – 34

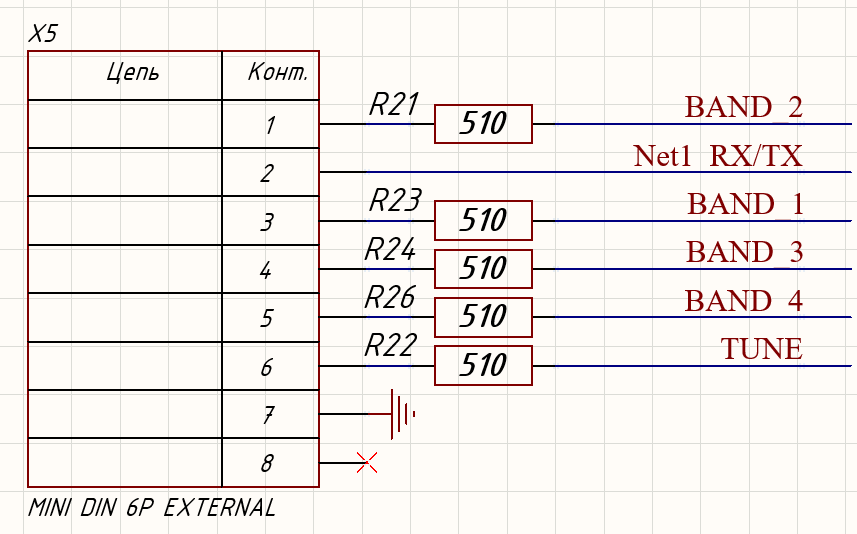
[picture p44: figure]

Рисунок – 35

Переведя трансивер на передачу (TX) на контакте «2» будет присутствовать 13.8В. А на остальных контактах на оборот подтянется к «земле». Назначение контактов 1,3,4,5 можно переназначить в меню трансивера.

Настройка ДПФ

Как настроить ДПФ на НЧ диапазоны описывать не стану тут все традиционно)), а вот как настроить 2м диапазон напишу, как, а точней по рекомендую.

### 1. выход NanoVna (или любой другой измерительный прибор) цепляем разъём RX

материнки (предварительно откалибровав NanoVna в ноль на проводах какими подпаиваем), второй конец прибора подключаем к конденсатору C122 при этом конденсатор нужно отпаять.

### 2. паяем последовательные фильтры режектора, ДПФ замыкаем, добываемся

максимального провала в FM диапазоне при низких потерях на 145мгц.

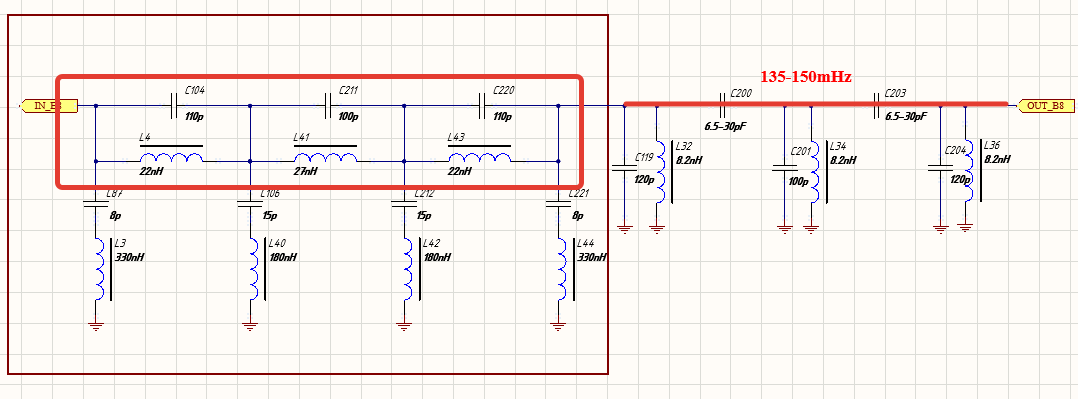
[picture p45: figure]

Рисунок – 36

### 3. поочередно подпаиваем параллельные звенья режектора, углубляя подавление в

FM.

### 4. собираем ДПФ на 145мгц, конденсаторами добиваемся максимального пика на

145мгц. Если он выше при любых настройках - поднимаем поочерёдно ёмкости конденсаторов С119, С201, С204 добиваясь нужного эффекта. Если низко -снижаем ёмкость

Если у Вас версия MAIN платы младше V0.3 и для выравнивания АЧХ на 2м диапазоне, необходимо 9 вывод (2A) микросхем FST3253 U21, U22,

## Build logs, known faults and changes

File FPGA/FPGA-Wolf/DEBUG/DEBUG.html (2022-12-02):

DEBUG

2022.11.27.12:52:08 | Datasheet

Overview

Memory Map

## in_system_sources_probes_0

altera_in_system_sources_probes v18.1

Parameters

device_family | CYCLONEIVE
gui_use_auto_index | true
sld_auto_instance_index | YES
sld_instance_index | 0
instance_id | DBG1
probe_width | 32
source_width | 0
source_initial_value | 0
create_source_clock | false
create_source_clock_enable | false
enable_metastability | NO
deviceFamily | UNKNOWN
generateLegacySim | false

Software Assignments
(none)

generation took 0,02 seconds | rendering took 0,02 seconds

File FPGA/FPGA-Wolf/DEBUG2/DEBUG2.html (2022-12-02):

DEBUG2

2022.11.27.13:36:10 | Datasheet

Overview

Memory Map

## in_system_sources_probes_0

altera_in_system_sources_probes v18.1

Parameters

device_family | CYCLONEIVE
gui_use_auto_index | true
sld_auto_instance_index | YES
sld_instance_index | 0
instance_id | DBG2
probe_width | 3
source_width | 0
source_initial_value | 0
create_source_clock | false
create_source_clock_enable | false
enable_metastability | NO
deviceFamily | UNKNOWN
generateLegacySim | false

Software Assignments
(none)

generation took 0,02 seconds | rendering took 0,02 seconds

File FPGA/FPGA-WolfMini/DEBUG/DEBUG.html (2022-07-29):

DEBUG

2022.04.04.00:42:04 | Datasheet

Overview

Memory Map

## in_system_sources_probes_0

altera_in_system_sources_probes v18.1

Parameters

device_family | CYCLONEIVE
gui_use_auto_index | true
sld_auto_instance_index | YES
sld_instance_index | 0
instance_id | DBG1
probe_width | 24
source_width | 0
source_initial_value | 0
create_source_clock | false
create_source_clock_enable | false
enable_metastability | NO
deviceFamily | UNKNOWN
generateLegacySim | false

Software Assignments
(none)

generation took 0,01 seconds | rendering took 0,03 seconds

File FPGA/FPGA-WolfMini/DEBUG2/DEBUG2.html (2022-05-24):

DEBUG2

2022.05.19.19:26:26 | Datasheet

Overview

Memory Map

## in_system_sources_probes_0

altera_in_system_sources_probes v18.1

Parameters

device_family | CYCLONEIVE
gui_use_auto_index | true
sld_auto_instance_index | YES
sld_instance_index | 0
instance_id | DBG2
probe_width | 1
source_width | 0
source_initial_value | 0
create_source_clock | false
create_source_clock_enable | false
enable_metastability | NO
deviceFamily | UNKNOWN
generateLegacySim | false

Software Assignments
(none)

generation took 0,01 seconds | rendering took 0,02 seconds

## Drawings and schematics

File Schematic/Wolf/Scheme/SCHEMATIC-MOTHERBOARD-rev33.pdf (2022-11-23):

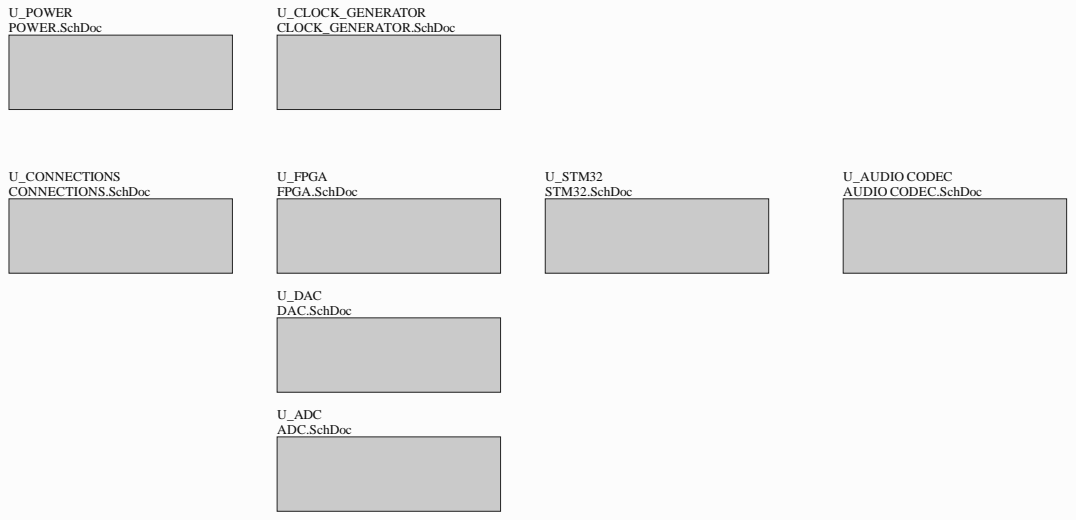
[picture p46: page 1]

C:\Dropbox\Develop\Projects\WOLF\Schematic\Wolf\Altium_Designer\MOTHERBOARD\MOTHERBOARD.SCHDOC

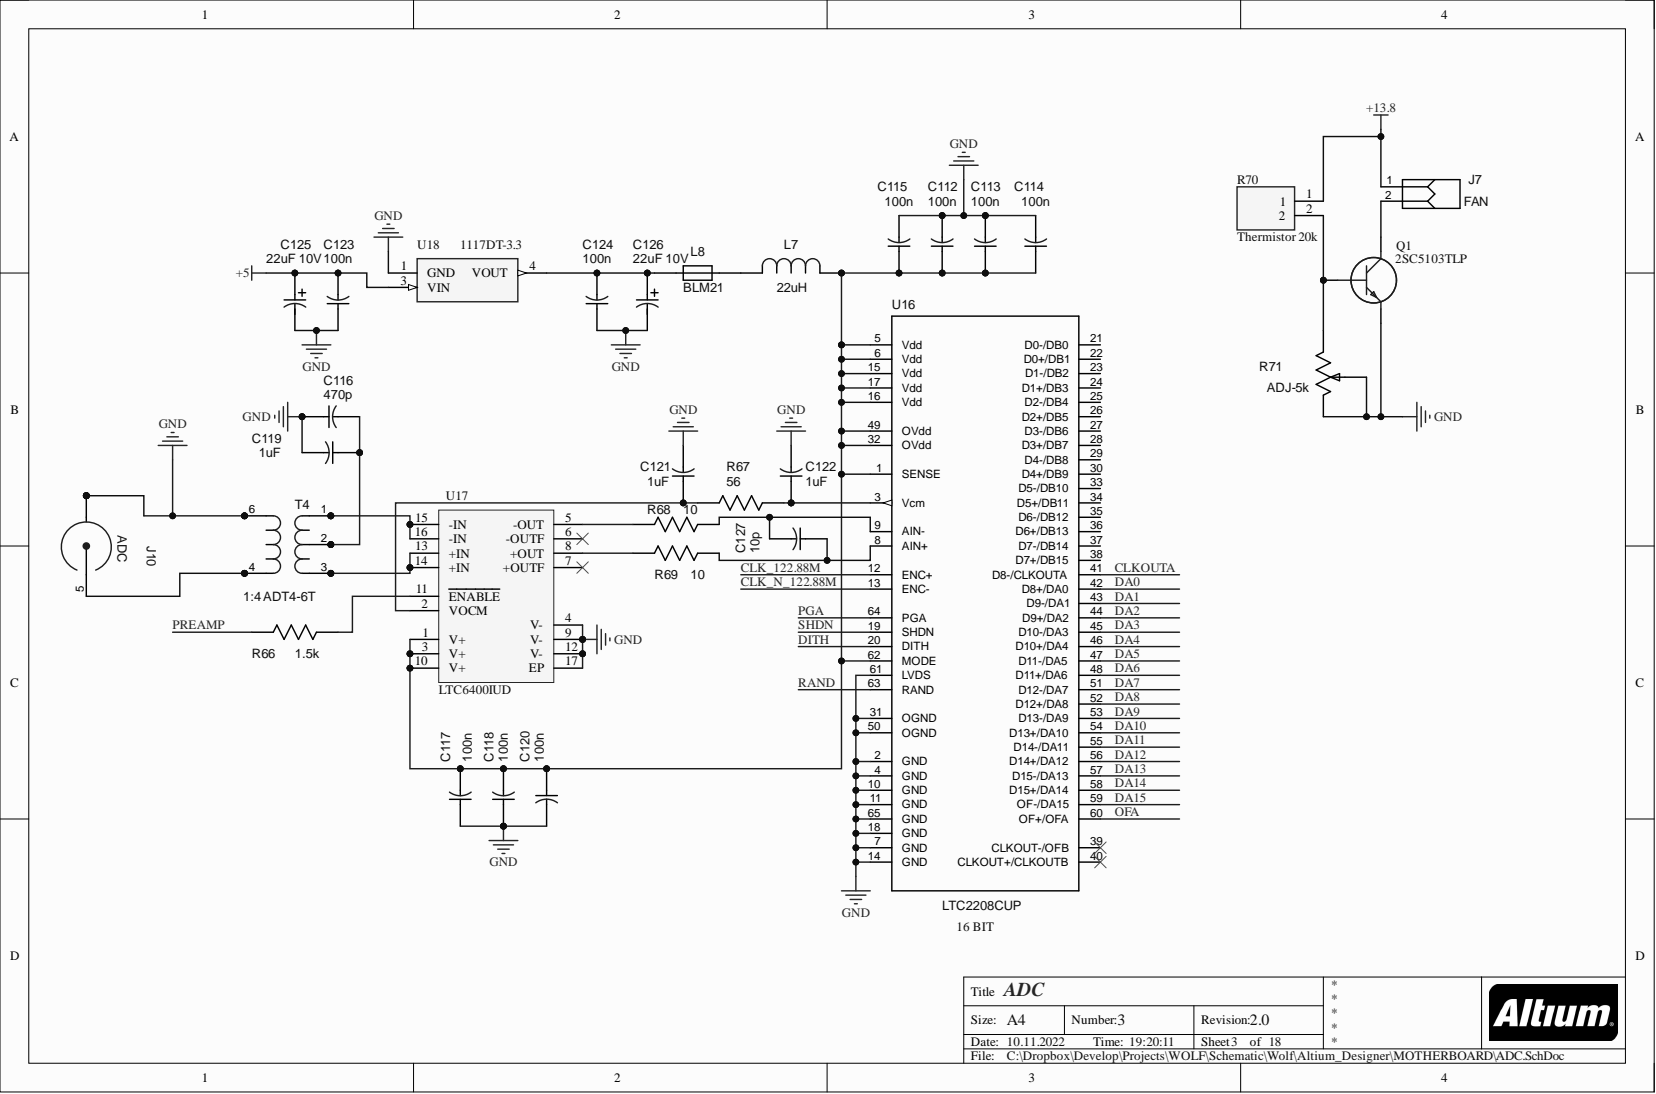
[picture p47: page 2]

V-V + V + V-V + E P | 4

3 | 1 2
1 0 | 1 7

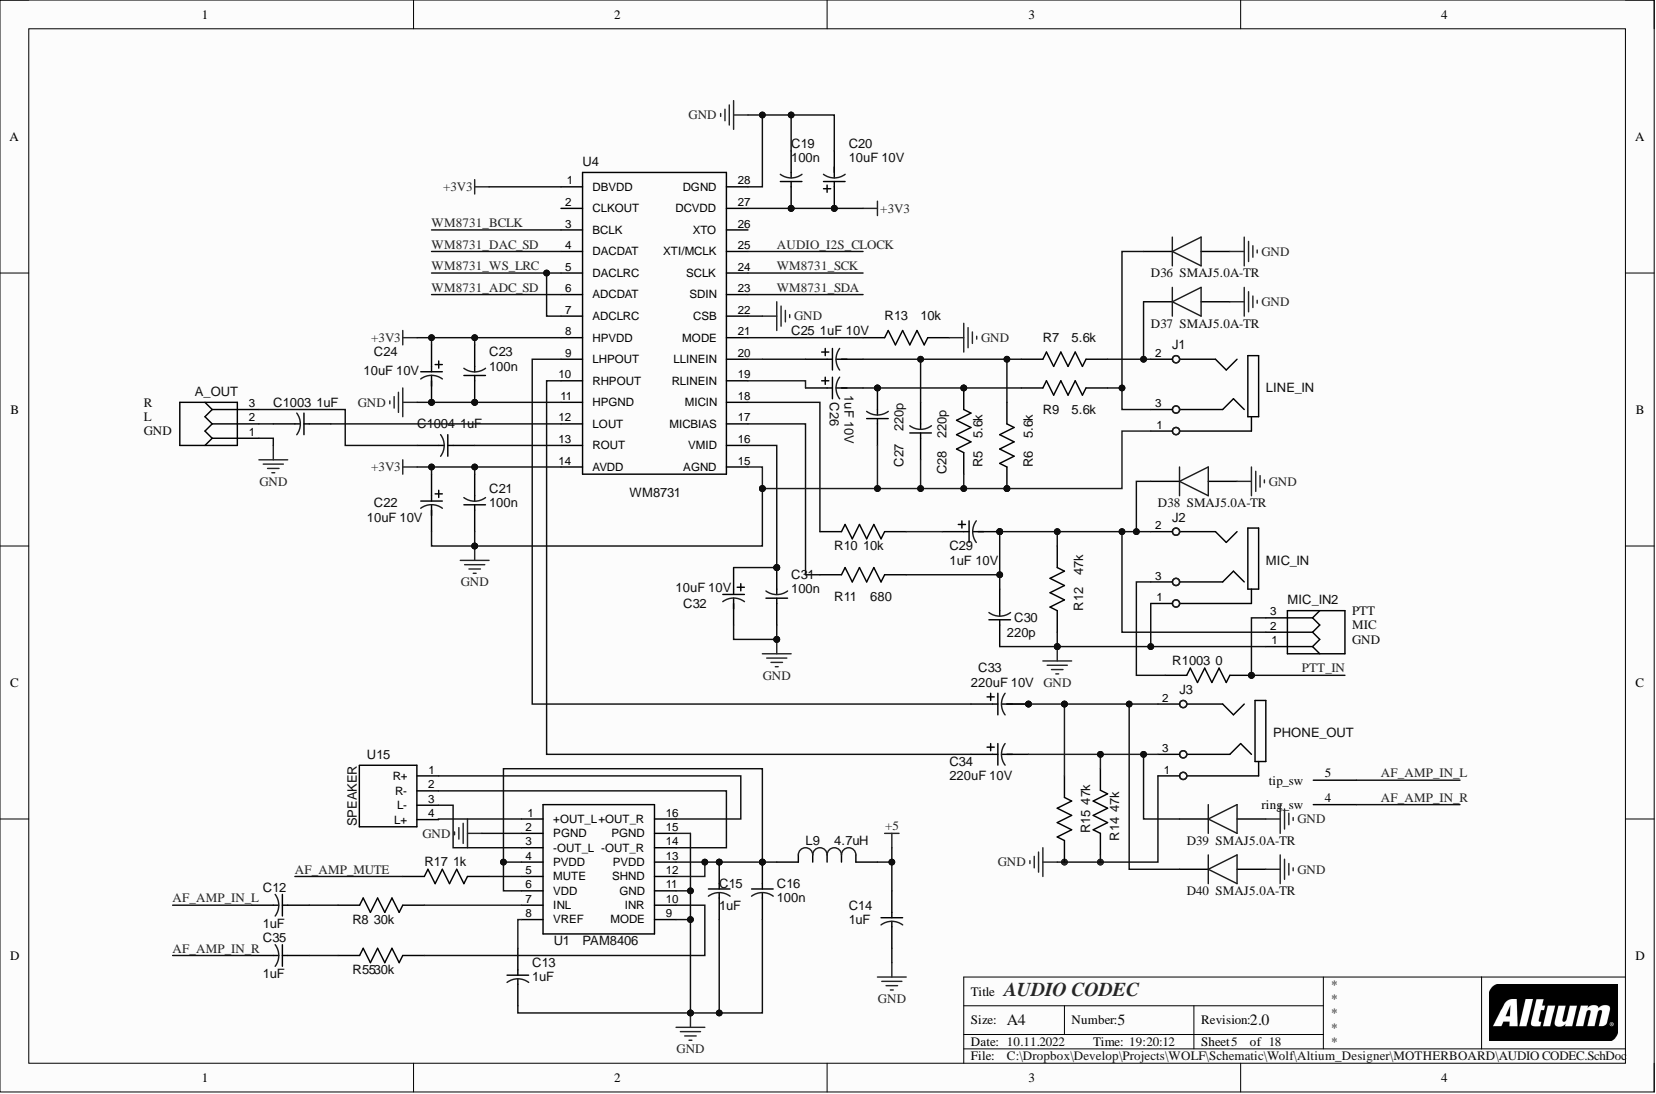
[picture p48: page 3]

ADCLRC 7

LHPOUT 9

RHPOUT 10

HPGND 11 MICBIAS VMID AGND | 15 AVDD 14

LOUT 12 | 17

ROUT 13 | 16

MODE PGND -OUT_R | 9 VREF 8 15

INL 7 VDD 6 MUTE 5 PVDD 4 -OUT_L 3 PGND 2 +OUT_L 1 | 14

PVDD SHND | 13 12

C:\Dropbox\Develop\Projects\WOLF\Schematic\Wolf\Altium_Designer\MOTHERBOARD\AUDIO CODEC.SchDoc

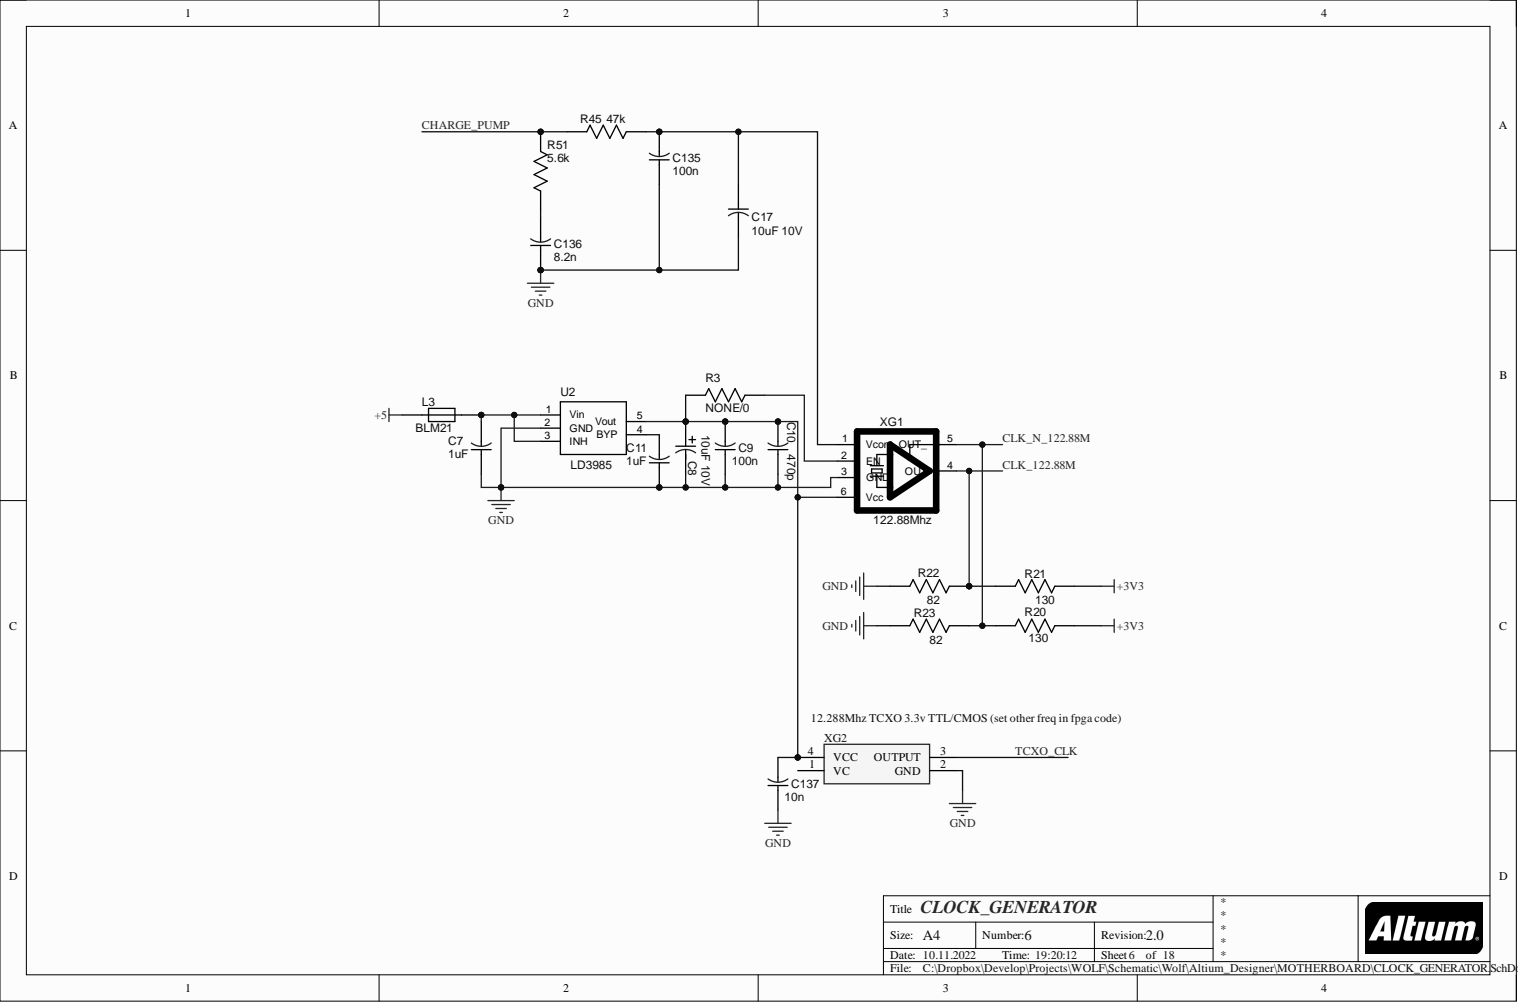
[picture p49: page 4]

Vcont 1

GND 3

12.288Mhz TCXO 3.3v TTL/CMOS (set other freq in fpga code)

C:\Dropbox\Develop\Projects\WOLF\Schematic\Wolf\Altium_Designer\MOTHERBOARD\CLOCK_GENERATOR.SchDoc

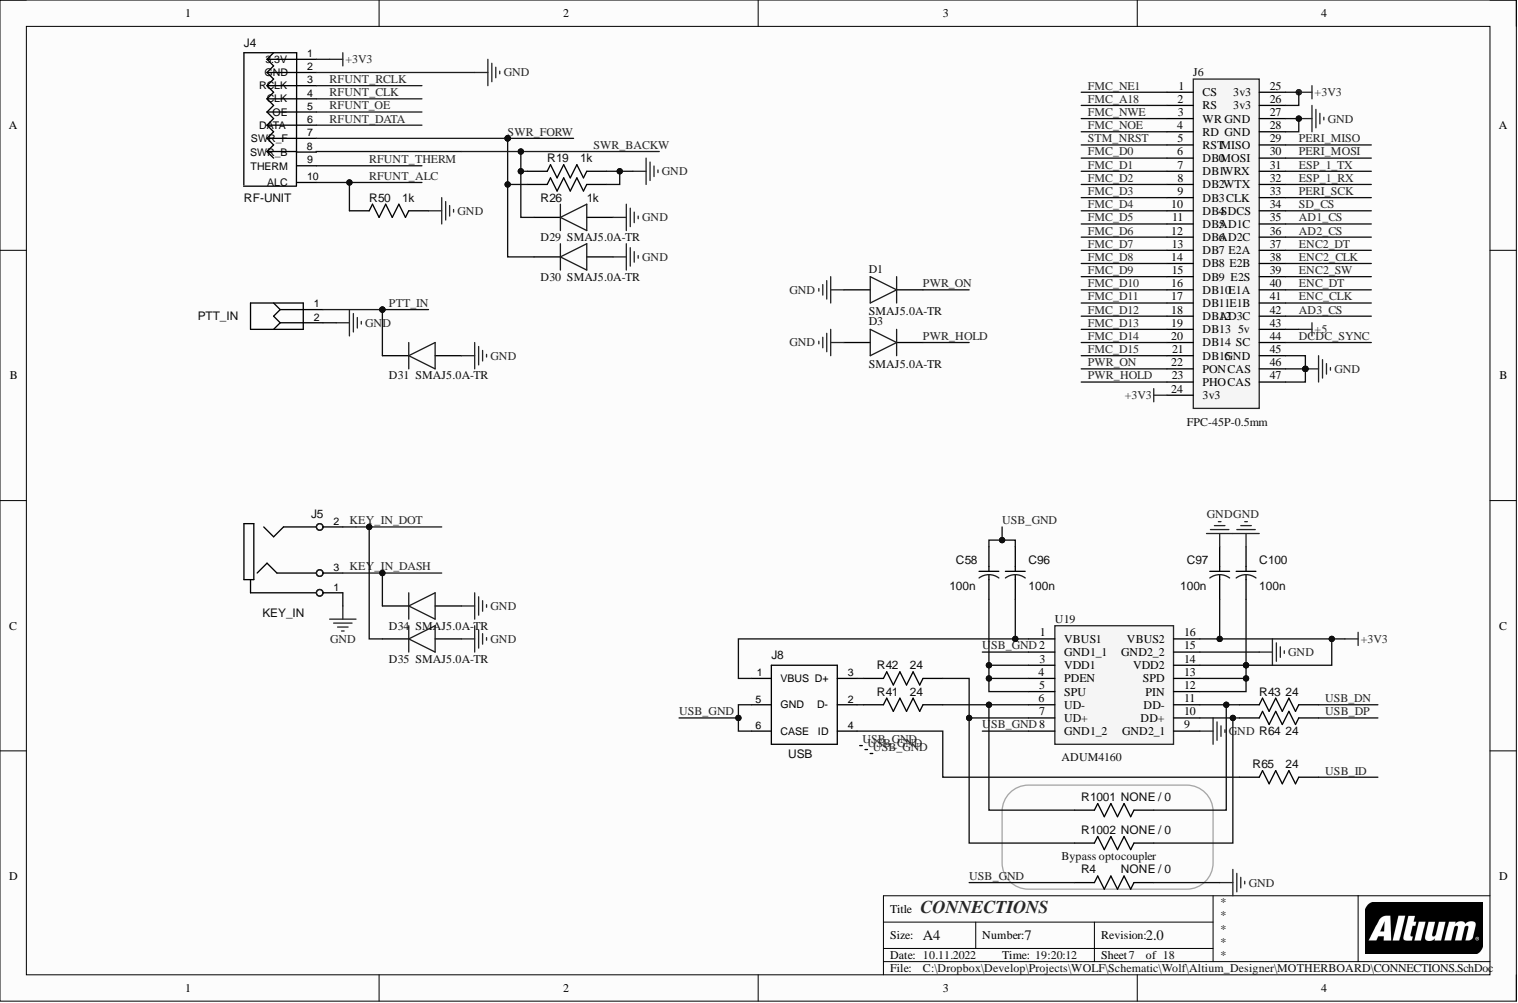
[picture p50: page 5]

GND 5 | SPU 5

USB_GND | GND1_2 8

UUSB_ USB_ SB_GGN GND NDD

C:\Dropbox\Develop\Projects\WOLF\Schematic\Wolf\Altium_Designer\MOTHERBOARD\CONNECTIONS.SchDoc

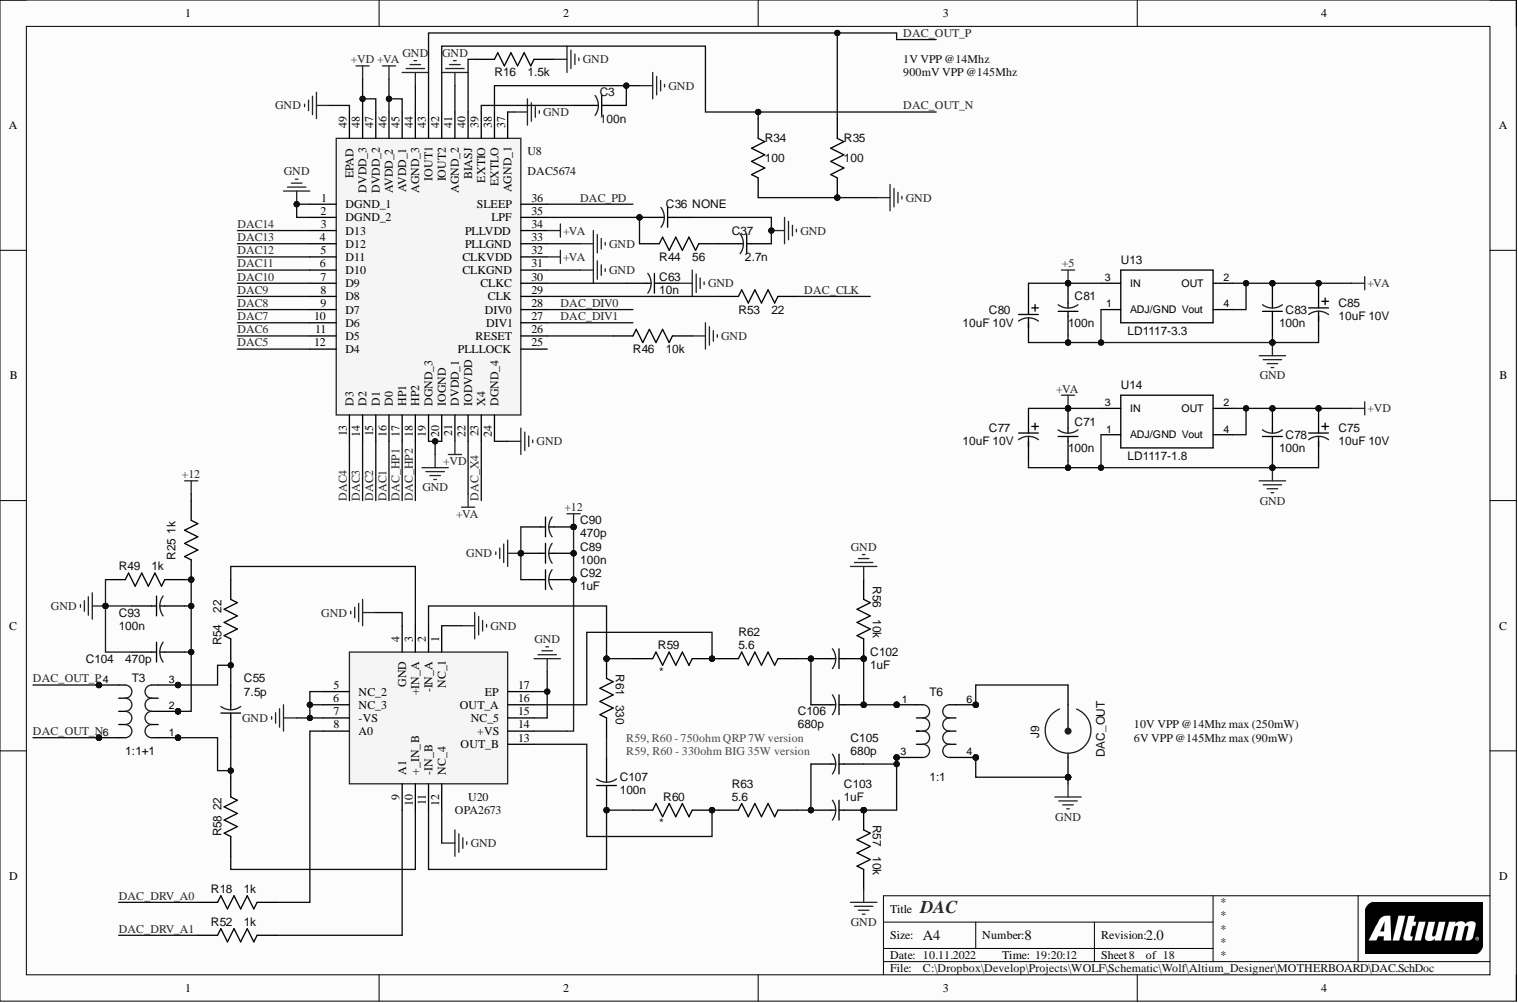
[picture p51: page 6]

C:\Dropbox\Develop\Projects\WOLF\Schematic\Wolf\Altium_Designer\MOTHERBOARD\DAC.SchDoc

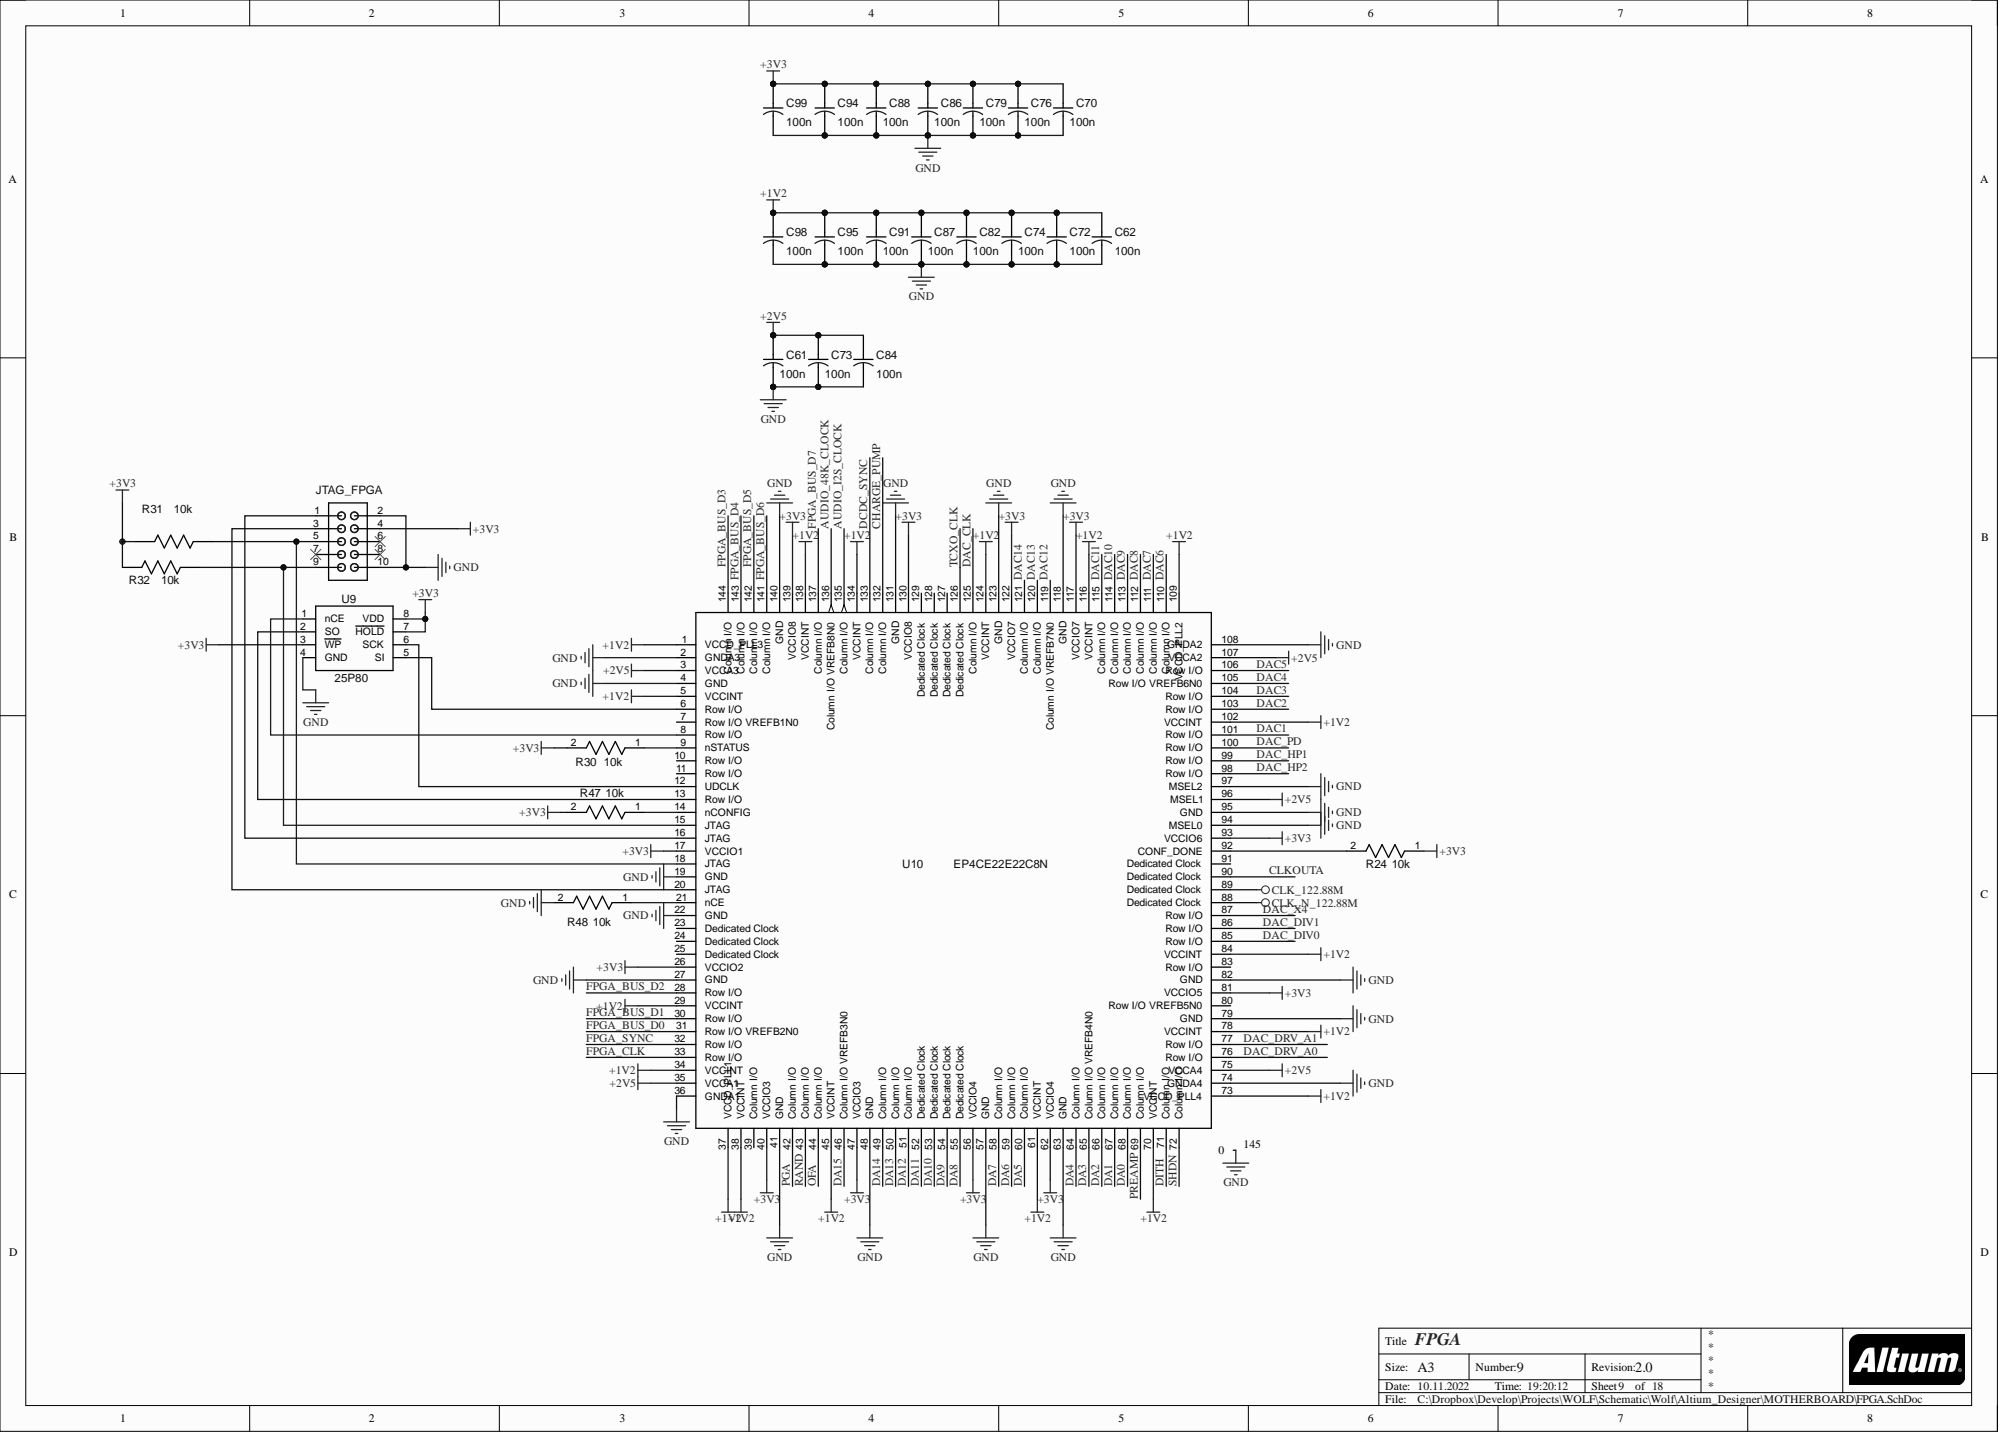
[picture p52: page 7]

Column I/O 72 Column I/O 71 VCCINT 70 Column I/O 69 Column I/O 68 Column I/O 67 Column I/O 66 Column I/O VREFB4N0 65 Column I/O 64 GND 63 VCCIO4 62 VCCINT 61 Column I/O 60 Column I/O 59 Column I/O 58 GND 57 VCCIO4 56 Dedicated Clock 55 Dedicated Clock 54 Dedicated Clock 53 Dedicated Clock 52 Column I/O 51 Column I/O 50 Column I/O 49 GND 48 VCCIO3 47 Column I/O VREFB3N0 46 VCCINT 45 Column I/O 44 Column I/O 43 Column I/O 42 GND 41 VCCIO3 40 Column I/O 39 VCCINT 38 VCCD_PLL1 37

C:\Dropbox\Develop\Projects\WOLF\Schematic\Wolf\Altium_Designer\MOTHERBOARD\FPGA.SchDoc

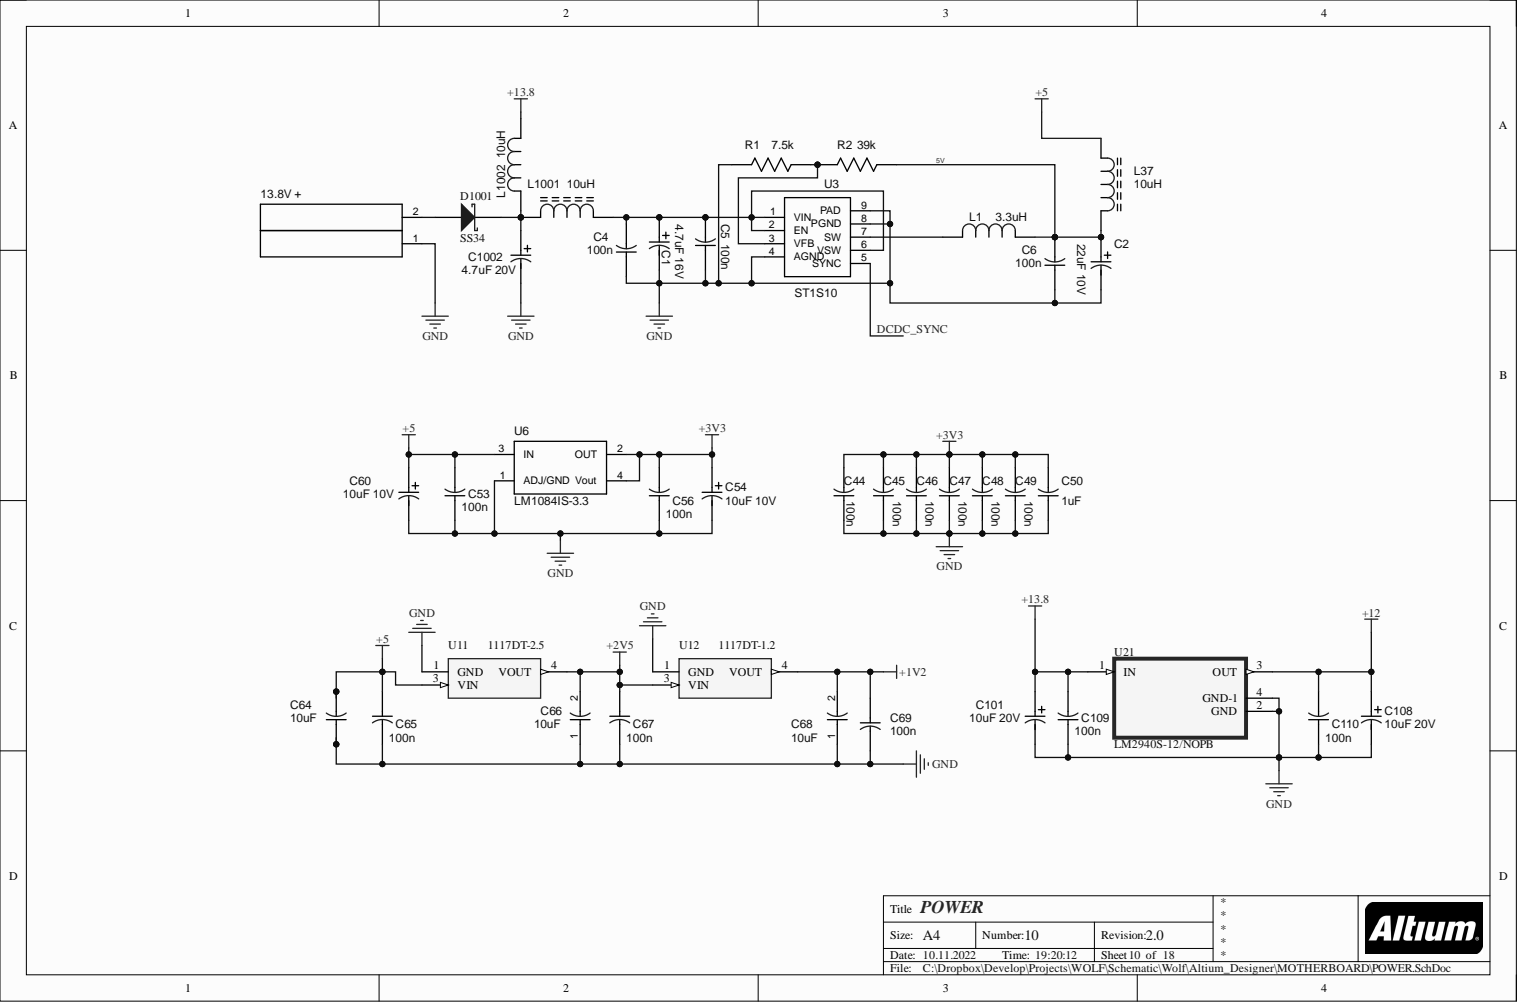
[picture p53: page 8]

C:\Dropbox\Develop\Projects\WOLF\Schematic\Wolf\Altium_Designer\MOTHERBOARD\POWER.SchDoc

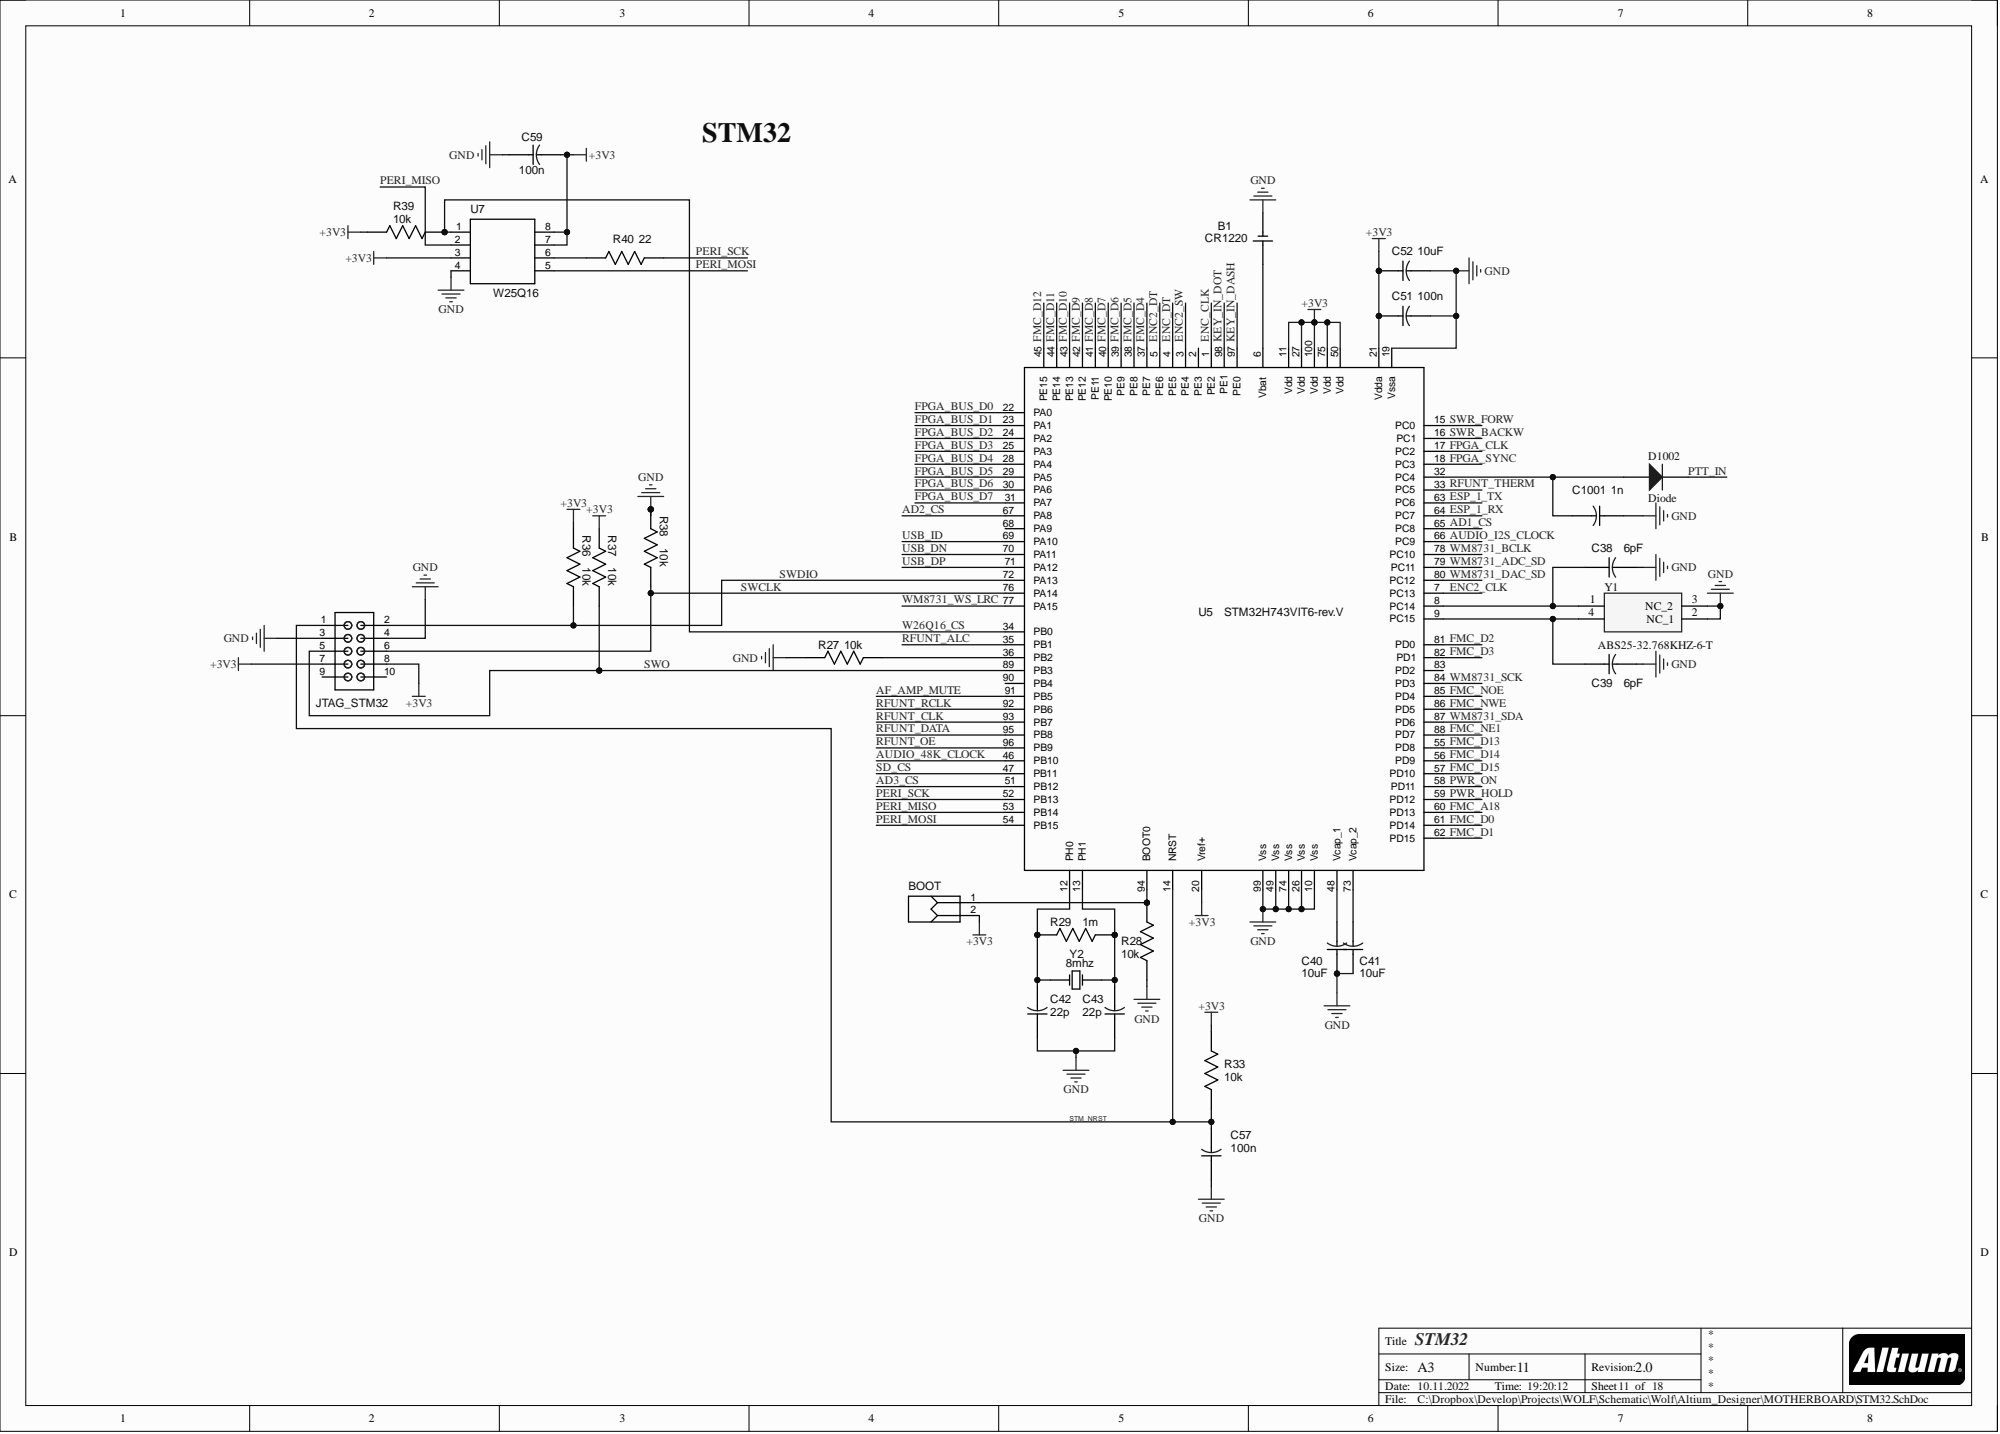
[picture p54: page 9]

C:\Dropbox\Develop\Projects\WOLF\Schematic\Wolf\Altium_Designer\MOTHERBOARD\STM32.SchDoc

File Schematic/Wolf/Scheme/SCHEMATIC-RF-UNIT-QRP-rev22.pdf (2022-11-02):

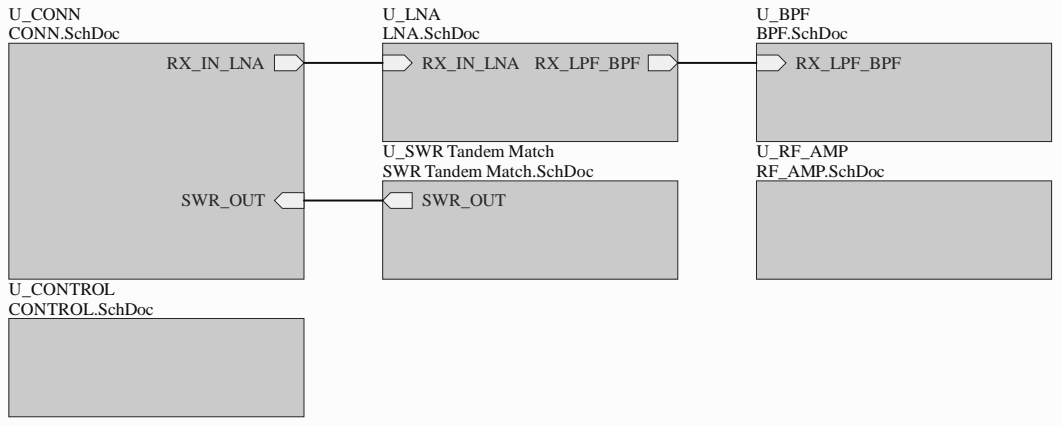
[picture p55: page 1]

U_SWR Tandem Match
SWR Tandem Match.SchDoc
SWR_OUT

C:\Dropbox\Develop\Projects\WOLF\Schematic\Wolf\Altium_Designer\RF-UNIT-QRP\RF-UNIT-QRP.SCHDOC

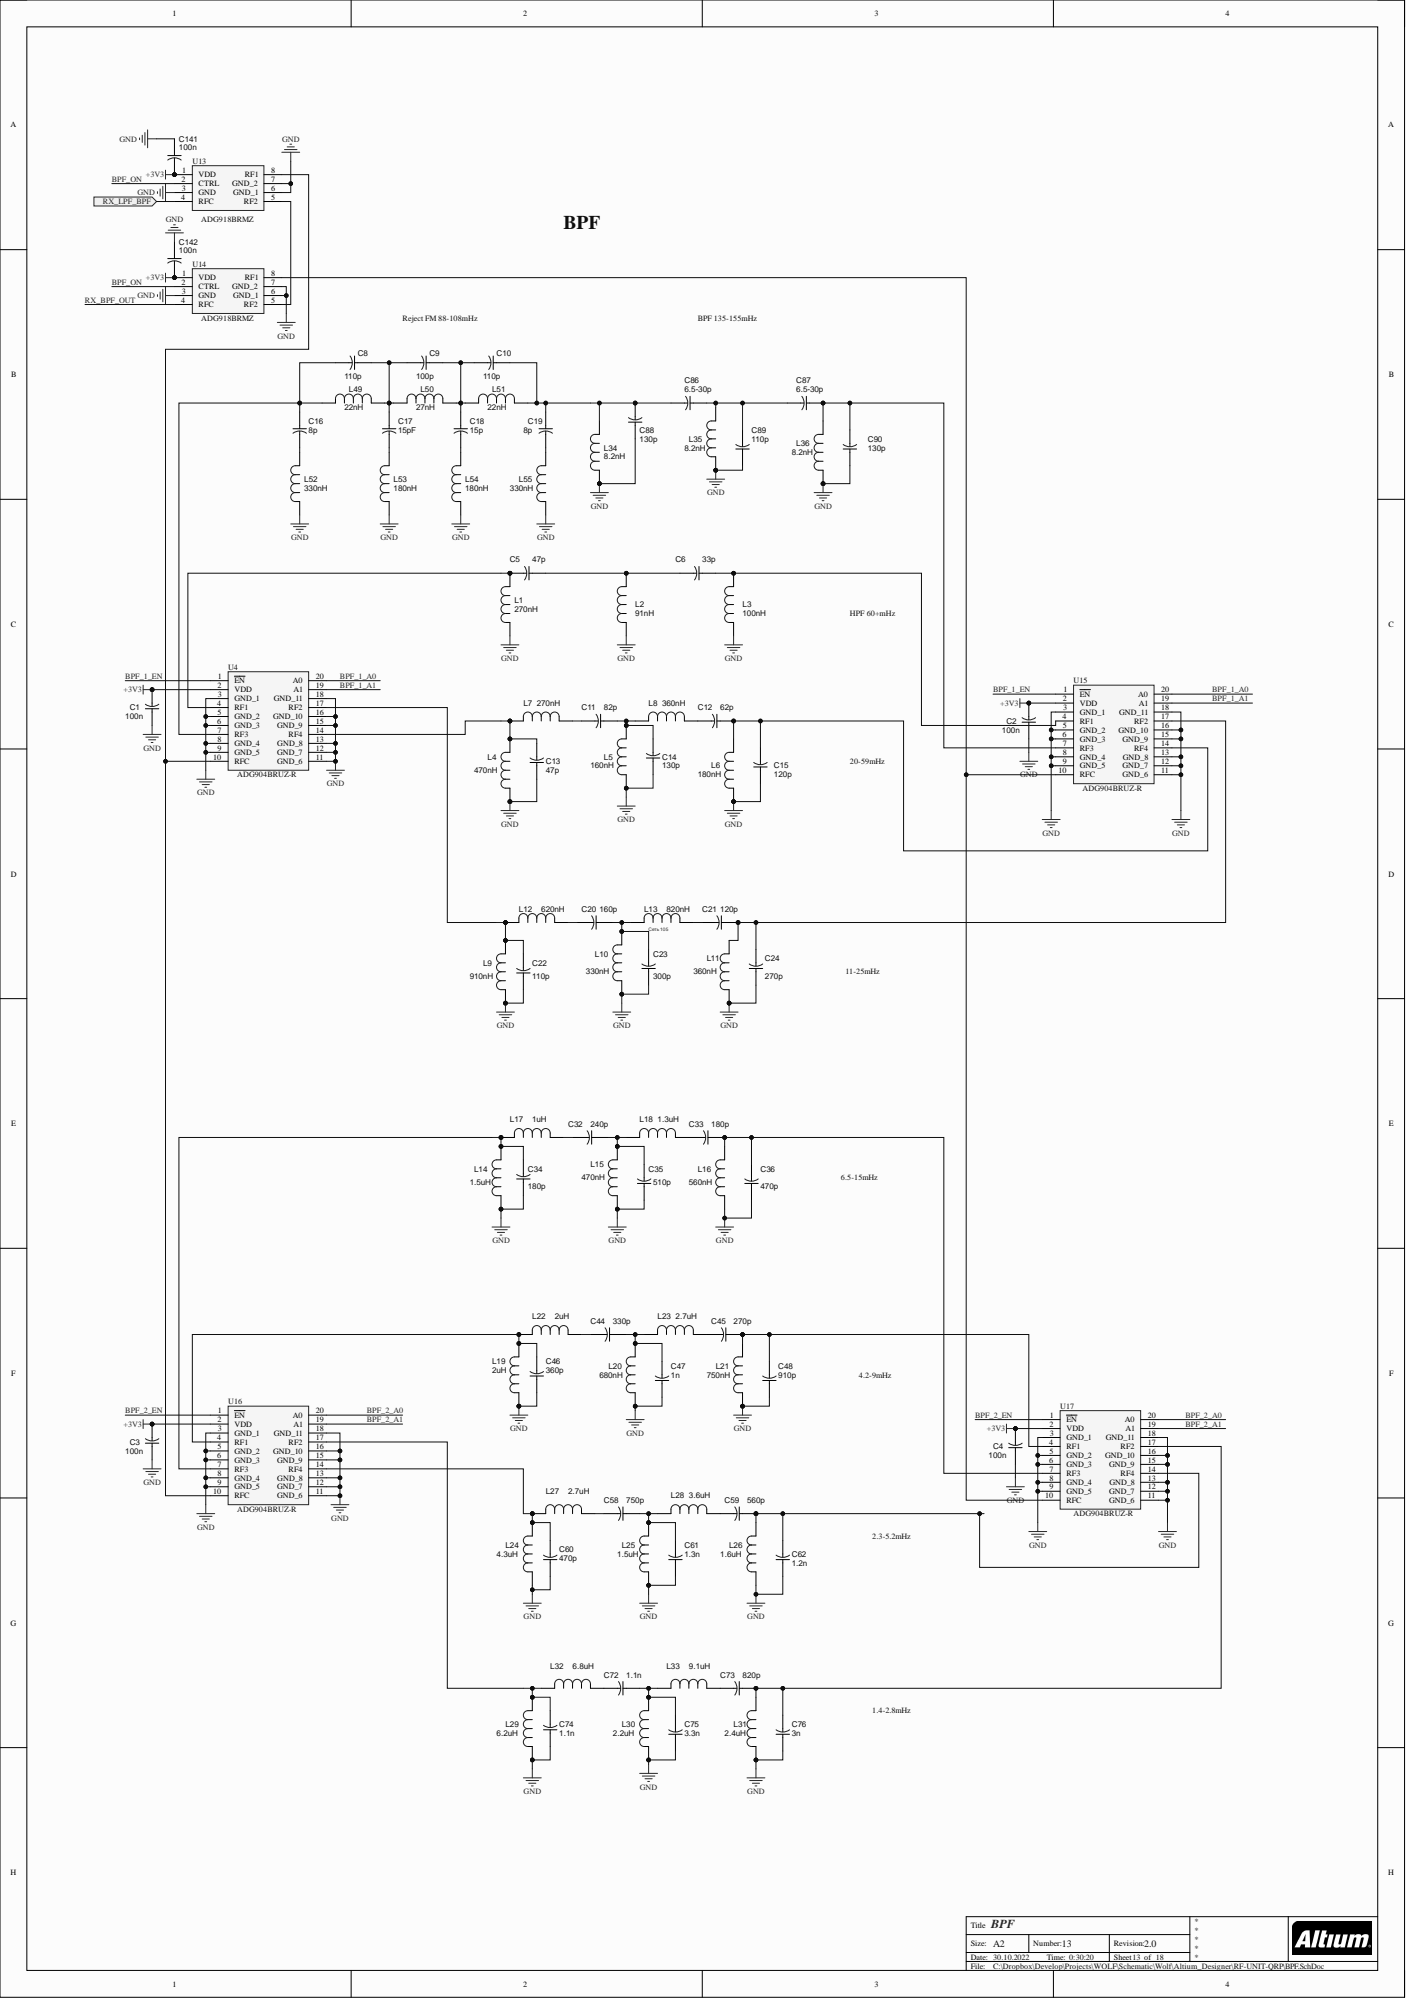
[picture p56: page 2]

EN 1 VDD 2 | RF2

GND_1 3
RF1 4 | 17
GND_2 5 GND_10 GND_9 | 16
GND_3 6 | 15

C15 | | GND_2 5 GND_10 GND_9 RF4 GND_8 GND_7 | 16

RF3 7 | 14
GND_4 8 | 13
GND_5 9 | 12

GND_4 8 GND_8 GND_7 | 13

GND | C20 160p L18 1.3uH C33 180p

C:\Dropbox\Develop\Projects\WOLF\Schematic\Wolf\Altium_Designer\RF-UNIT-QRP\BPF.SchDoc

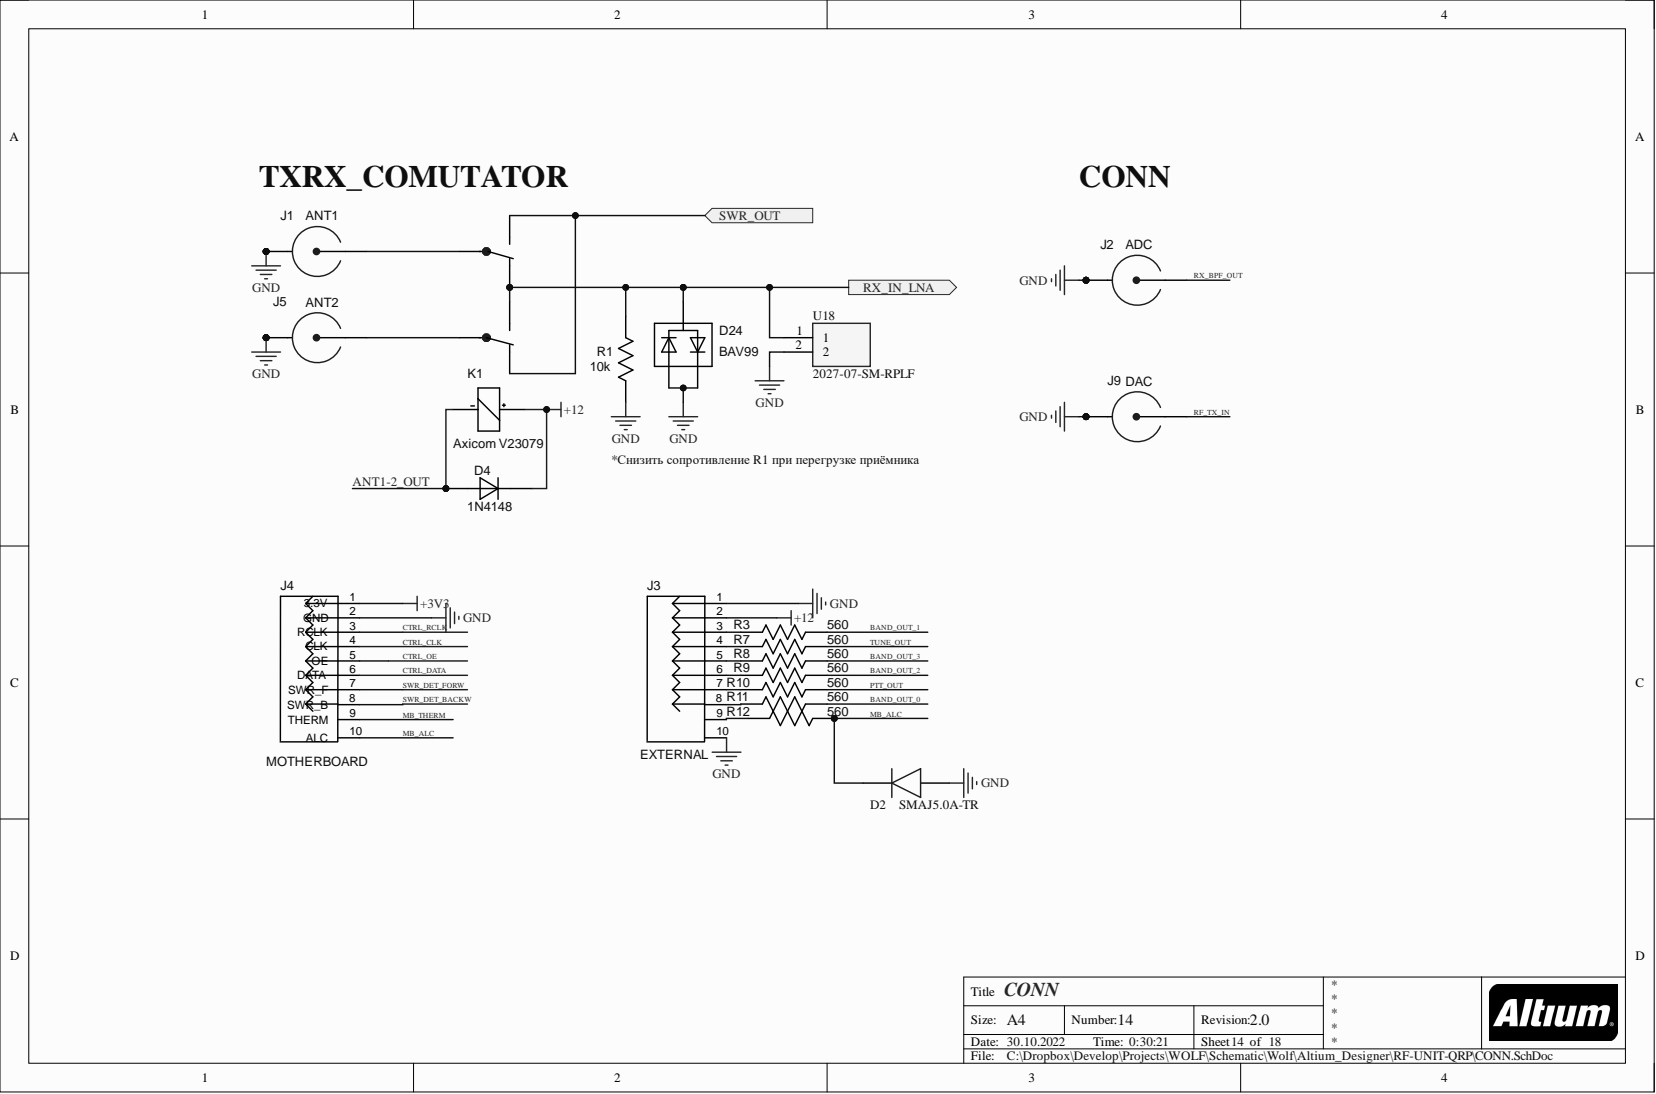
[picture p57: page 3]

GND
*Снизить сопротивление R1 при перегрузке приёмника

C:\Dropbox\Develop\Projects\WOLF\Schematic\Wolf\Altium_Designer\RF-UNIT-QRP\CONN.SchDoc


1 3 | 1 | | 2
1 1 | 2 | | 3


C:\Dropbox\Develop\Projects\WOLF\Schematic\Wolf\Altium_Designer\RF-UNIT-QRP\LNA.SchDoc



Катушки намотаны проводом 0.5мм на оправке диаметром 5мм, 3.5 витка

2 провода 0.9мм пропущено через бинокль

по диогонали пропущено и намотано по 10 витков 0.5мм

C:\Dropbox\Develop\Projects\WOLF\Schematic\Wolf\Altium_Designer\RF-UNIT-QRP\SWR Tandem Match.SchDoc

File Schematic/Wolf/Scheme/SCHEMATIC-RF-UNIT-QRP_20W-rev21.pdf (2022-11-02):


U_SWR Tandem Match
SWR Tandem Match.SchDoc
SWR_OUT

C:\Dropbox\Develop\Projects\WOLF\Schematic\Wolf\Altium_Designer\RF-UNIT-QRP_20W\RF-UNIT-QRP_20W.SCHDOC


EN 1 VDD 2 | RF2

GND_1 3
RF1 4 | 17
GND_2 5 GND_10 GND_9 | 16
GND_3 6 | 15

C15 | | GND_2 5 GND_10 GND_9 RF4 GND_8 GND_7 | 16

RF3 7 | 14
GND_4 8 | 13
GND_5 9 | 12

GND_4 8 GND_8 GND_7 | 13

GND | C20 150p C33 180p

GND_2 5 GND_10 GND_9 RF4 | 16

C:\Dropbox\Develop\Projects\WOLF\Schematic\Wolf\Altium_Designer\RF-UNIT-QRP_20W\BPF.SchDoc


GND
*Снизить сопротивление R1 при перегрузке приёмника

C:\Dropbox\Develop\Projects\WOLF\Schematic\Wolf\Altium_Designer\RF-UNIT-QRP_20W\CONN.SchDoc


1 3 | 1 | | 2
1 1 | 2 | | 3


C:\Dropbox\Develop\Projects\WOLF\Schematic\Wolf\Altium_Designer\RF-UNIT-QRP_20W\LNA.SchDoc


Can try to replace the L37, L38 and T3, only
with T3. Connecting the ground sides to
"AMP_PWR"
T3 - Core EPCO B62152A7X1
8 turn (16 passes through) - 8µH each

Idq - 200ma Q1 + 200ma Q3, далее у одного плеча
увеличивается до исчезновения 2-й гармоники

8-10 turns 2x0.5mm on 13.5х10х6.5 ferrit tube

2 parts: 5.5 turns 25ohms 2.3mm cable on Ferrite tube
13.5х10x6.5 each
(допустимо использование RG-178, если нет 25 ом)

5.5 turns RG-178 cable on Ferrite tube

Ferrite tubes from old VGA cables

C:\Dropbox\Develop\Projects\WOLF\Schematic\Wolf\Altium_Designer\RF-UNIT-QRP_20W\RF_AMP.SchDoc


Катушки намотаны проводом 0.5мм на оправке диаметром 5мм, 3.5 витка

2 провода 0.9мм пропущено через бинокль

по диогонали пропущено и намотано по 10 витков 0.5мм

C:\Dropbox\Develop\Projects\WOLF\Schematic\Wolf\Altium_Designer\RF-UNIT-QRP_20W\SWR Tandem Match.SchDoc

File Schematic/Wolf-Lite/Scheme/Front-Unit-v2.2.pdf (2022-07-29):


Инв. № подл. Инв. № дубл. Подп. и дата Взам. инв. № Подп. и дата

Конт. | Цепь

Comment | Description | Designator | Footprint | LibRef | Quantity
0.1 | | C1, C2, C3, C4, C7, C8, C9, C10, C11 | CH0805C | Capacitor | 9
10uF 10V | | C5, C6 | TANTAL_B | TantalCap | 2
AMS117-5 | | DA1 | SOT223 | AMS117 | 1
3V | | G1 | BAT: CH224-2032 | POWER_BAT | 1
1K | | R1, R7, R15, R19 | CH0805R | Resistor | 4
4.7K | | R2, R8, R9, R10, R11, R12, R14 | CH0805R | Resistor | 7
4K7 | | R3, R4, R5 | CH0805R | Resistor | 3
2K | | R6, R13, R16 | CH0805R | Resistor | 3
1R | | R17 | CH0805R | Resistor | 1
10K | | R18 | CH0805R | Resistor | 1
"Кнопка" | 6x6mm | SB1, SB2, SB3, SB4, SB5, SB6, SB7, SB9 | BUT: 5X5 | Tactile switches | 8
"Power" | 6x6mm | SB8 | BUT: 5X5 | Tactile switches | 1
PEC12 | Encoder | SW1 | Valkoder-m2 | PEC12 | 1
MCP3008-I/SL | | U1 | 16-SOIC | MCP3008-I/SL | 1
IRFR5103 | | VT1 | SOT23_132 | N-KANAL | 1
IPS 3.5 | | X1 | FPC-40P 0.5mm | LCD-IPS 3.5 | 1
FPC 0.5 | | X2 | CON: PBD2x20 | FPC-45-0.5 | 1
Valcoder | | X3 | CON: PLS-5 | 5-Connector | 1
IPS 3.5 | | X4 | IPS 3.5 ILI9481 | LCD-IPS 3.5 | 1

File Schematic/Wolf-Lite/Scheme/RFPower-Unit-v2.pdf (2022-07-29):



Инв. № подл. Инв. № дубл. Подп. и дата Взам. инв. № Подп. и дата Перв. примен. Справ. №

1 PLD1

Comment | Description | Designator | Footprint | LibRef | Quantity
0.1 | | C1, C2, C3, C4, C5, C31, C32, C33, C34, C40, C41, C42, C51, C52, C54, C55, C59, C60, C63, C64, C65, C70, C71, C72, C73, C78, C80, C81, C82, C83, C84 | CH0805C | C_smd, Capacitor | 31
1.5nF | | C6, C26 | CH1206C | C_smd | 2
1n | | C7, C18, C27 | CH1206C | C_smd | 3
470p | | C8, C28 | CH1206C | C_smd | 2
157p | | C9, C29 | CH1206C | C_smd | 2
100p | | C10, C12, C22, C30, C77, C79 | CH1206C | C_smd, Capacitor | 6
220p | | C11, C21 | CH1206C | C_smd | 2
47p | | C13, C23 | CH1206C | C_smd | 2
33p | | C14, C24 | CH1206C | C_smd | 2
22p | | C15, C25 | CH1206C | C_smd | 2
3nF | | C16 | CH1206C | C_smd | 1
2nF | | C17 | CH1206C | C_smd | 1
330p | | C19 | CH1206C | C_smd | 1
200p | | C20 | CH1206C | C_smd | 1
22x16 | | C53, C56 | TANTAL_B | AlumCap | 2
10n | | C57, C58, C61, C62, C66, C67 | CH0805C | Capacitor | 6
10n | | C68, C69 | CH1206C | Capacitor | 2
0.1 | | C74, C75 | CH1206C | Capacitor | 2
220x35 | | C76 | D8C3.2H12 | AlumCap | 1
BAT54A | | D1 | SOT23_132 | BAT54 | 1
10uH | | DR1 | DR2 | Inductor-1 | 1
JP1 | | JP1 | CON: PLS-2 | JP2 | 1
JP2 | | JP2 | CON: PLS-2 | JP2 | 1
| | K1, K2, K3, K4, K5, K6, K7, K8, K9, K10, K11, K12, K13 | G5V-1 | G5V-1 | 13
1,9 uH | | L1, L7 | T50-2 | L | 2
1uH | | L2, L8 | T50-6 | L | 2
0,6 uH | | L3, L9 | T50-6 | L | 2
0,26 uH | | L4, L10 | T50-6 | L | 2
3.9 uH | | L5 | T50-2 | L | 1
3,9 uH | | L6 | T50-2 | L | 1
100 | | R1, R2, R6, R8 | CH1206R | Resistor | 4
0 | | R3, R7 | CH0805R | Resistor | 2
510 | | R4, R5 | CH0805R | Resistor | 2
300 | | R9, R11 | CH0805R | Resistor | 2
18 | | R10 | CH0805R | Resistor | 1
10K | | R12, R13 | CH0805R | Resistor | 2
1K | | R14, R29, R30, R31 | CH0805R | Resistor | 4
330 | | R15, R16, R18, R19, R20, R24 | CH0805R | Resistor | 6
150* | | R17 | CH0805R | Resistor | 1
10 | | R21 | CH0805R | Resistor | 1
33 | | R22, R23 | CH0805R | Resistor | 2
| | R25, R28 | RES: 3296W | ADJ resistor | 2
2,2K | | R26, R27 | CH1206R | Resistor | 2
2.2K | | R32, R33 | CH0805R | Resistor | 2
BN-43-302 | | T1 | FT-37-43 | BN-43-302 | 1
BN43-302 | | TR1 | TANDEM | BN43-302 | 1
TR-kolco | | TR2 | TR-Kolco | TR-kolco | 1
TR-UM | | TR3 | TR-UM | TR-UM | 1
LM7809 | | U3 | DPAK | Kren_5 | 1
BAT46JFILM | | VD1, VD2 | D9B | Diod | 2
1N4148 | | VD3 | SOD123 | Diod | 1
IRFR6402 | | VT1 | SOT23_132 | P-KANAL | 1
| | VT2 | SOT23_123 | N-P-N | 1
BFG591 | | VT3, VT4 | BFG | N-P-N | 2
RD16HHF1 | | VT5, VT6 | rd16 | N | 2
PLD10 | | X1 | CON: PLD-10 | 10-Connector | 1
TX-IN | RF | X1 | CON: SMA | SMA | 1
TX/RX | RF | X2 | Connect | SMA | 1
| | X3 | CON: CWF-3 | 3-Connector | 1
| | X5 | CON: 300-02P-5.0 | 2-Connector | 1

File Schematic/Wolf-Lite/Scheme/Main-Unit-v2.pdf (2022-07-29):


Инв. № подл. Инв. № дубл. Подп. и дата Взам. инв. № Подп. и дата Перв. примен. Справ. №

Net_DAC9 OUT_TX Net_DAC-PD RX/TX | | Net_DAC9 Net_DAC-PD

LTC_ENABLE Net-bit7 Net-bit2 Net-bit10 Net-bit6 Net-bit4 Net-bit3 Net-bit1 Net-bit5 Net-bit9 Net-otr Net-bit8 Net-bit11 Net-Clock Net-bit12 FPG_CTRL LPF3 BPF_OE2 LPF1 BPF_A BPF_B LPF2 BPF_OE1

RX/TX | U_WL-ATT

MUTE SWR_FORW WM8731_BCLK SWR_BACKW WM8731_SCK WM8731_WS_LRC KEY_IN_DOT KEY_IN_DASH WM8731_DAC_SD WM8731_ADC_SD WM8731_SDA

Designator WL-CONNECT.SchDoc

Wolf-Lite

WOLF-LITE Схема электрическая принципиальная | Лит. | Масса | Масштаб

Изм. | Лист | № докум. | Подп. | Дата | | * | | | 1:1
Разраб. | | UA3REO/R7KBI

Пров. | | *
Т.контр. | * | | | | Лист | Листов 12

Н.контр. | *
Утв. | *


Инв. № подл. Инв. № дубл. Подп. и дата Взам. инв. № Подп. и дата Перв. примен. Справ. №

Quart | z re sona tors

X8 ST-Link | 12


Инв. № подл. Инв. № дубл. Подп. и дата Взам. инв. № Подп. и дата Перв. примен. Справ. №

TDI TMS TDO TCK

C o l umn I / O D e d i c a t e d C l o c k D e d i c a t e d C l o c k D e d i c a t e d C l o c k D e d i c a t e d C l o c k C o l umn I / O C o l umn I / O C o l umn I / O C o l umn I / O C o l umn I / O VR E F B 4 N O C o l umn I / O C o l umn I / O C o l umn I / O D e d i c a t e d C l o c k | R ow I / O R ow I / O C o l umn I / O C o l umn I / O VR E F B 8 N O C o l umn I / O C o l umn I / O C o l umn I / O C o l umn I / O C o l umn I / O C o l umn I / O C o l umn I / O C o l umn I / O C o l umn I / O

FB13 BLM | 1 34


Инв. № подл. Инв. № дубл. Подп. и дата Взам. инв. № Подп. и дата Перв. примен. Справ. №

E NAB LE V+ V+ V+ | | VO CM V -V -V -V - | | | | 19 Ne t -b i t7

AVD D AVD D | D RVD D D RVD D D RVD D D RVS S D RVS S D RVS S


Инв. № подл. Инв. № дубл. Подп. и дата Взам. инв. № Подп. и дата Перв. примен. Справ. №

Одну из двух FB

Лист | № докум. | Подп. | Дата | Wolf-Lite Изм.

Лист


Инв. № подл. Инв. № дубл. Подп. и дата Взам. инв. № Подп. и дата Перв. примен. Справ. №

PVDDL 4

Конт. | Цепь


Инв. № подл. Инв. № дубл. Подп. и дата Взам. инв. № Подп. и дата

Wolf-Lite

Изм. | Лист | № докум. | Подп. | Дата


Цепь | Конт.

Инв. № подл. Инв. № дубл. Подп. и дата Взам. инв. № Подп. и дата

Wolf-Lite

Изм. | Лист | № докум. | Подп. | Дата


Конт. | Цепь

Инв. № подл. Инв. № дубл. Подп. и дата Взам. инв. № Подп. и дата

Wolf-Lite

Изм. | Лист | № докум. | Подп. | Дата


Инв. № подл. Инв. № дубл. Подп. и дата Взам. инв. № Подп. и дата Перв. примен. Справ. №


Инв. № подл. Инв. № дубл. Подп. и дата Взам. инв. № Подп. и дата

Wolf-Lite

Изм. | Лист | № докум. | Подп. | Дата


Цепь | Конт.

Инв. № подл. Инв. № дубл. Подп. и дата Взам. инв. № Подп. и дата

VBUS | 1

GND | 5

Wolf-Lite

Изм. | Лист | № докум. | Подп. | Дата

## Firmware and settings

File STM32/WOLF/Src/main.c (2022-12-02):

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
/* Includes ------------------------------------------------------------------*/
#include "main.h"
#include "fatfs.h"

/* USER CODE BEGIN Includes */
#include "INA226_PWR_monitor.h" //Tisho
#include "audio_processor.h"
#include "bootloader.h"
#include "codec.h"
#include "fft.h"
#include "fpga.h"
#include "front_unit.h"
#include "functions.h"
#include "images.h"
#include "jpeg_utils.h"
#include "lcd.h"
#include "lcd_driver.h"
#include "profiler.h"
#include "rf_unit.h"
#include "sd.h"
#include "settings.h"
#include "trx_manager.h"
#include "usb_device.h"
#include "usbd_cat_if.h"
#include "usbd_debug_if.h"
#include "wifi.h"
/* USER CODE END Includes */

ADC_HandleTypeDef hadc1;
ADC_HandleTypeDef hadc3;

CRC_HandleTypeDef hcrc;

DMA2D_HandleTypeDef hdma2d;

I2S_HandleTypeDef hi2s3;

IWDG_HandleTypeDef hiwdg1;

JPEG_HandleTypeDef hjpeg;

RTC_HandleTypeDef hrtc;

SPI_HandleTypeDef hspi2;
DMA_HandleTypeDef hdma_spi2_rx;
DMA_HandleTypeDef hdma_spi2_tx;

TIM_HandleTypeDef htim2;
TIM_HandleTypeDef htim3;
TIM_HandleTypeDef htim4;
TIM_HandleTypeDef htim5;
TIM_HandleTypeDef htim6;
TIM_HandleTypeDef htim7;
TIM_HandleTypeDef htim15;
TIM_HandleTypeDef htim16;
TIM_HandleTypeDef htim17;

UART_HandleTypeDef huart6;
DMA_HandleTypeDef hdma_usart6_rx;

PCD_HandleTypeDef hpcd_USB_OTG_FS;

DMA_HandleTypeDef hdma_memtomem_dma2_stream5;
MDMA_HandleTypeDef hmdma_mdma_channel40_sw_0;
MDMA_HandleTypeDef hmdma_mdma_channel41_sw_0;
MDMA_HandleTypeDef hmdma_mdma_channel42_sw_0;
MDMA_HandleTypeDef hmdma_mdma_channel43_sw_0;
MDMA_HandleTypeDef hmdma_mdma_channel44_sw_0;
SRAM_HandleTypeDef hsram1;

/* USER CODE BEGIN PV */
DMA_HandleTypeDef hdma_spi3_rx;
DMA_HandleTypeDef hdma_spi3_tx;
static char greetings_buff[32] = {0};
/* USER CODE END PV */

void SystemClock_Config(void);
static void MPU_Config(void);
static void MX_GPIO_Init(void);
static void MX_DMA_Init(void);
static void MX_MDMA_Init(void);
static void MX_ADC1_Init(void);
static void MX_FMC_Init(void);
static void MX_I2S3_Init(void);
static void MX_RTC_Init(void);
static void MX_SPI2_Init(void);
static void MX_TIM3_Init(void);
static void MX_TIM4_Init(void);
static void MX_TIM5_Init(void);
static void MX_TIM6_Init(void);
static void MX_TIM7_Init(void);
static void MX_USART6_UART_Init(void);
static void MX_USB_OTG_FS_PCD_Init(void);
static void MX_ADC3_Init(void);
static void MX_TIM15_Init(void);
static void MX_TIM16_Init(void);
static void MX_TIM17_Init(void);
static void MX_DMA2D_Init(void);
static void MX_TIM2_Init(void);
static void MX_CRC_Init(void);
static void MX_IWDG1_Init(void);
static void MX_JPEG_Init(void);
/**
 * @brief  The application entry point.
 * @retval int
 */
int main(void) {
	/* USER CODE BEGIN 1 */
	MX_GPIO_Init(); // pwr hold
	/* USER CODE END 1 */

	/* MPU Configuration--------------------------------------------------------*/
	MPU_Config();

	/* Enable I-Cache---------------------------------------------------------*/
	SCB_EnableICache();

	/* Enable D-Cache---------------------------------------------------------*/
	SCB_EnableDCache();

	/* MCU Configuration--------------------------------------------------------*/

	/* Reset of all peripherals, Initializes the Flash interface and the Systick. */
	HAL_Init();

	/* Configure the system clock */
	SystemClock_Config();

	/* USER CODE BEGIN SysInit */
	// System stabilization
	uint8_t tryes = 0;
	// while (tryes < 3 && (!__HAL_PWR_GET_FLAG(PWR_FLAG_VOSRDY) || (RCC->CR & RCC_CR_HSERDY) == 0 || (RCC->CR & RCC_CR_PLL1RDY) == 0 || (RCC->CR &
	// RCC_CR_PLL2RDY) == 0 || (RCC->CR & RCC_CR_PLL3RDY) == 0 || (RCC->CFGR & RCC_CFGR_SWS) != RCC_CFGR_SWS_PLL1))
	while (tryes < 3 && (!__HAL_PWR_GET_FLAG(PWR_FLAG_VOSRDY) || (RCC->CR & RCC_CR_HSERDY) == 0 || (RCC->BDCR & RCC_BDCR_LSERDY) == 0 || (RCC->CR & RCC_CR_PLL1RDY) == 0 ||
	                     (RCC->CFGR & RCC_CFGR_SWS) != RCC_CFGR_SWS_PLL1)) {
		SystemClock_Config();
		tryes++;
	}
	if (tryes == 3) {
		MX_FMC_Init();
		LCD_Init();
		LCD_showError("STM32 crystals error", false);
	}

// Stack protection
#define stack_addr 0x20000000
	MPU_Region_InitTypeDef MPU_InitStruct = {0};
	MPU_InitStruct.Enable = MPU_REGION_ENABLE;
	MPU_InitStruct.Number = MPU_REGION_NUMBER4;
	MPU_InitStruct.BaseAddress = stack_addr + 256; // growning down
	MPU_InitStruct.Size = MPU_REGION_SIZE_32B;
	MPU_InitStruct.SubRegionDisable = 0x0;
	MPU_InitStruct.TypeExtField = MPU_TEX_LEVEL0;
	MPU_InitStruct.AccessPermission = MPU_REGION_NO_ACCESS;
	MPU_InitStruct.DisableExec = MPU_INSTRUCTION_ACCESS_ENABLE;
	MPU_InitStruct.IsShareable = MPU_ACCESS_NOT_SHAREABLE;
	MPU_InitStruct.IsCacheable = MPU_ACCESS_NOT_CACHEABLE;
	MPU_InitStruct.IsBufferable = MPU_ACCESS_NOT_BUFFERABLE;
	HAL_MPU_ConfigRegion(&MPU_InitStruct);

	/* USER CODE END SysInit */

	/* Initialize all configured peripherals */
	MX_GPIO_Init();
	MX_DMA_Init();
	MX_MDMA_Init();
	MX_ADC1_Init();
	MX_FMC_Init();
	MX_I2S3_Init();
	MX_RTC_Init();
	MX_SPI2_Init();
	MX_TIM3_Init();
	MX_TIM4_Init();
	MX_TIM5_Init();
	MX_TIM6_Init();
	MX_TIM7_Init();
	MX_USART6_UART_Init();
	MX_ADC3_Init();
	MX_TIM15_Init();
	MX_TIM16_Init();
	MX_TIM17_Init();
	MX_FATFS_Init();
	MX_DMA2D_Init();
	MX_TIM2_Init();
	MX_CRC_Init();
	MX_JPEG_Init();
	/* USER CODE BEGIN 2 */
#ifdef HAS_TOUCHPAD
  GPIO_InitTypeDef GPIO_InitStruct = {0};
  GPIO_InitStruct.Pin = ENC2SW_AND_TOUCHPAD_Pin;
  GPIO_InitStruct.Mode = GPIO_MODE_INPUT;
  GPIO_InitStruct.Pull = GPIO_PULLDOWN;
  HAL_GPIO_Init(ENC2SW_AND_TOUCHPAD_GPIO_Port, &GPIO_InitStruct);
#endif
	__HAL_RCC_CSI_ENABLE();
	__HAL_RCC_SYSCFG_CLK_ENABLE();
	__HAL_RCC_BKPRAM_CLK_ENABLE();
	HAL_EnableCompensationCell();
	println("\r\n----------------------------------");
	println("Wolf Transceiver Initialization...");
	println("[OK] USB init");
	USBD_Restart();
	println("[OK] FIFO timer TIM7 init");
	HAL_TIM_Base_Start_IT(&htim7);
	println("[OK] ENC2 timer TIM16 init");
	HAL_TIM_Base_Start_IT(&htim16);
	println("[OK] Real Time Clock init");
	HAL_RTC_Init(&hrtc);
	println("[OK] Frontpanel init");
	FRONTPANEL_Init();

	println("[OK] Settings loading");
	bool reset_settings = false;
	bool reset_calibrations = false;
	bool go_dfu = false;

#ifdef FRONTPANEL_SMALL_V1
	if (PERIPH_FrontPanel_Buttons[15].state) { // soft reset (MENU)
		reset_settings = true;
	}
	if (PERIPH_FrontPanel_Buttons[15].state && PERIPH_FrontPanel_Buttons[0].state) { // Very hard reset (MENU+PRE)
		reset_calibrations = true;
	}
#endif
#ifdef FRONTPANEL_BIG_V1
	if (PERIPH_FrontPanel_Buttons[15].state) { // soft reset (F1)
		reset_settings = true;
	}
	if (PERIPH_FrontPanel_Buttons[15].state && PERIPH_FrontPanel_Buttons[5].state) { // Very hard reset (F1+F8)
		reset_calibrations = true;
	}
#endif
#ifdef FRONTPANEL_WF_100D
	if (PERIPH_FrontPanel_Buttons[10].state) { // go DFU (MENU)
		go_dfu = true;
	}
	if (PERIPH_FrontPanel_Buttons[13].state) { // soft reset (F1)
		reset_settings = true;
	}
	if (PERIPH_FrontPanel_Buttons[13].state && PERIPH_FrontPanel_Buttons[3].state) { // Very hard reset (F1+F8)
		reset_calibrations = true;
	}
#endif

	if (reset_settings) {
		LoadSettings(true);
	} else {
		LoadSettings(false);
	}

	// DFU bootloader
	if (TRX.NeedGoToBootloader || go_dfu) {
		TRX.NeedGoToBootloader = false;
		SaveSettings();
		JumpToBootloader();
	} else {
		MX_IWDG1_Init();
	}

	println("[OK] Calibration & WiFi loading");
	if (reset_calibrations) {
		LoadCalibration(true);
	} else {
		LoadCalibration(false);
	}

#ifdef FRONTPANEL_WF_100D
	if (CALIBRATE.RF_unit_type != RF_UNIT_WF_100D) {
		LoadCalibration(true);
	}
#endif

	TRX.Locked = false;
	println("[OK] LCD init");
	LCD_busy = true;
	LCD_Init();
	JPEG_InitColorTables();
	if (SHOW_LOGO) {
		strcpy(greetings_buff, "ver. ");
		strcat(greetings_buff, version_string);

#if (defined(LAY_800x480))
		LCDDriver_Fill(rgb888torgb565(255, 255, 255));
		LCDDriver_printImage_JPEGCompressed(0, 0, IMAGES_logo800_jpeg);
		LCDDriver_printTextFont(greetings_buff, 30, (LCD_HEIGHT - 30), COLOR_BLACK, rgb888torgb565(243, 243, 243), &FreeSans12pt7b);
#else
		LCDDriver_Fill(rgb888torgb565(243, 243, 243));
		LCDDriver_printImage_RLECompressed(((LCD_WIDTH - IMAGES_logo480.width) / 2), ((LCD_HEIGHT - IMAGES_logo480.height) / 2), &IMAGES_logo480, BG_COLOR, BG_COLOR);
		LCDDriver_printText(greetings_buff, 10, (LCD_HEIGHT - 10 - 8), COLOR_RED, rgb888torgb565(243, 243, 243), 1);
#endif

		// show callsign greetings
		uint16_t x1, y1, w, h;
		strcpy(greetings_buff, "Hello, ");
		strcat(greetings_buff, TRX.CALLSIGN);
		strcat(greetings_buff, " !");
		LCDDriver_getTextBoundsFont(greetings_buff, LAYOUT->GREETINGS_X, LAYOUT->GREETINGS_Y, &x1, &y1, &w, &h, &FreeSans9pt7b);
		LCDDriver_printTextFont(greetings_buff, LAYOUT->GREETINGS_X - (w / 2), LAYOUT->GREETINGS_Y, COLOR->GREETINGS, rgb888torgb565(243, 243, 243), &FreeSans9pt7b);
	}
	println("[OK] Profiler init");
	InitProfiler();

	println("[OK] RTC calibration");
	RTC_Calibration();

	println("[OK] RF-Unit init");
	RF_UNIT_UpdateState(false);
	println("[OK] FFT/Waterfall & ADC & TIM4 init");
	FFT_PreInit();
	FFT_Init();
	HAL_TIM_Base_Start_IT(&htim4);
	println("[OK] STM32-ADC Calibration");
	HAL_ADCEx_Calibration_Start(&hadc1, LL_ADC_CALIB_OFFSET_LINEARITY, ADC_SINGLE_ENDED);
	HAL_ADCEx_Calibration_Start(&hadc3, LL_ADC_CALIB_OFFSET_LINEARITY, ADC_SINGLE_ENDED);
	println("[OK] AudioCodec init");
	CODEC_Init();
	println("[OK] TRX init");
	TRX_Init();
	println("[OK] Audioprocessor & TIM5 init");
	initAudioProcessor();
	HAL_TIM_Base_Start_IT(&htim5);
	LCD_busy = false;
	LCD_redraw(true);
	println("[OK] Misc timer TIM6 init");
	HAL_TIM_Base_Start_IT(&htim6);
	println("[OK] CPU Load init");
	CPULOAD_Init();
	println("[OK] PERIPHERAL timer TIM15 init");
	dma_memset(&SDFatFs, 0, sizeof(SDFatFs));
	HAL_TIM_Base_Start_IT(&htim15);
	println("[OK] Digital decoder timer TIM17 init");
	HAL_TIM_Base_Start_IT(&htim17);
	println("[OK] FPGA init");
#ifdef FRONTPANEL_SMALL_V1
	if (PERIPH_FrontPanel_Buttons[19].state) { // fpga bus test (MODE+)
		FPGA_Init(true, false);
	}
	if (PERIPH_FrontPanel_Buttons[20].state) { // fpga firmware test (MODE-)
		FPGA_Init(false, true);
	} else
#endif
		FPGA_Init(false, false);
	println("[OK] WIFI timer TIM3 init");
	HAL_TIM_Base_Start_IT(&htim3);
	println("UA3REO Transceiver started!\r\n");
	TRX_Inited = true;

// Tisho
#if defined(FRONTPANEL_BIG_V1)
	if (CALIBRATE.INA226_EN) { //	if INA226 is activated then initialise
		INA226_Init();
	}
#endif // Tisho end of change

	// while(true){HAL_Delay(3000); SCB->AIRCR = 0x05FA0004; } //debug restart
	/* USER CODE END 2 */

	/* Infinite loop */
	/* USER CODE BEGIN WHILE */
	while (1) {
		/* USER CODE END WHILE */

		/* USER CODE BEGIN 3 */
		CPULOAD_GoToSleepMode();
	}
	/* USER CODE END 3 */
}

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
/* USER CODE BEGIN 4 */
// обработка вывода отладки
FILE __stdout;
FILE __stdin;
#if defined(__clang__)
int fputc(int ch, FILE *f) {
#pragma unused(f)
#else
int __io_putchar(int ch) {
#endif
    //SWD
    if (SWD_DEBUG_ENABLED) {
        ITM_SendChar((uint32_t) ch);
    }
	// USB
	if (USB_DEBUG_ENABLED) {
		char usb_char = (char)ch;
		DEBUG_Transmit_FIFO((uint8_t *)&usb_char, 1);
	}

	// LCD
	if (LCD_DEBUG_ENABLED) {
		print_chr_LCDOnly((char)ch);
	}

	return (ch);
}
/* USER CODE END 4 */

/* MPU Configuration */

void MPU_Config(void) {
	MPU_Region_InitTypeDef MPU_InitStruct = {0};

	/* Disables the MPU */
	HAL_MPU_Disable();

	/** Initializes and configures the Region and the memory to be protected
	 */
	MPU_InitStruct.Enable = MPU_REGION_ENABLE;
	MPU_InitStruct.Number = MPU_REGION_NUMBER0;
	MPU_InitStruct.BaseAddress = 0x60000000;
	MPU_InitStruct.Size = MPU_REGION_SIZE_1MB;
	MPU_InitStruct.SubRegionDisable = 0x0;
	MPU_InitStruct.TypeExtField = MPU_TEX_LEVEL0;
	MPU_InitStruct.AccessPermission = MPU_REGION_FULL_ACCESS;
	MPU_InitStruct.DisableExec = MPU_INSTRUCTION_ACCESS_ENABLE;
	MPU_InitStruct.IsShareable = MPU_ACCESS_SHAREABLE;
	MPU_InitStruct.IsCacheable = MPU_ACCESS_NOT_CACHEABLE;
	MPU_InitStruct.IsBufferable = MPU_ACCESS_NOT_BUFFERABLE;

	HAL_MPU_ConfigRegion(&MPU_InitStruct);

	/** Initializes and configures the Region and the memory to be protected
	 */
	MPU_InitStruct.Number = MPU_REGION_NUMBER2;
	MPU_InitStruct.BaseAddress = 0x38800000;
	MPU_InitStruct.Size = MPU_REGION_SIZE_4KB;

	HAL_MPU_ConfigRegion(&MPU_InitStruct);
	/* Enables the MPU */
	HAL_MPU_Enable(MPU_PRIVILEGED_DEFAULT);
}

/**
 * @brief  This function is executed in case of error occurrence.
 * @retval None
 */
void Error_Handler(void) {
	/* USER CODE BEGIN Error_Handler_Debug */
	/* User can add his own implementation to report the HAL error return state */
	println("error handled");
	/*while (1)
	{
	  LCD_showError("Error handled", true);
	}*/
	// LCD_showError("Error handled", true);
	/* USER CODE END Error_Handler_Debug */
}

#ifdef USE_FULL_ASSERT
/**
 * @brief  Reports the name of the source file and the source line number
 *         where the assert_param error has occurred.
 * @param  file: pointer to the source file name
 * @param  line: assert_param error line source number
 * @retval None
 */
void assert_failed(uint8_t *file, uint32_t line) {
	/* USER CODE BEGIN 6 */
	/* User can add his own implementation to report the file name and line number,
	   tex: printf("Wrong parameters value: file %s on line %d\r\n", file, line) */
	printf("Wrong parameters value: file %s on line %u\r\n", file, line);
	/* USER CODE END 6 */
}
#endif /* USE_FULL_ASSERT */

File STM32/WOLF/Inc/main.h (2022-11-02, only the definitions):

#define RFUNIT_CLK_Pin GPIO_PIN_2
#define RFUNIT_CLK_GPIO_Port GPIOE
#define PWR_ON_Pin GPIO_PIN_3
#define PWR_ON_GPIO_Port GPIOE
#define PWR_ON_EXTI_IRQn EXTI3_IRQn
#define ENC2_DT_Pin GPIO_PIN_4
#define ENC2_DT_GPIO_Port GPIOE
#define ENC_DT_Pin GPIO_PIN_5
#define ENC_DT_GPIO_Port GPIOE
#define RFUNIT_DATA_Pin GPIO_PIN_6
#define RFUNIT_DATA_GPIO_Port GPIOE
#define ENC2_CLK_Pin GPIO_PIN_13
#define ENC2_CLK_GPIO_Port GPIOC
#define SWR_FORW_Pin GPIO_PIN_0
#define SWR_FORW_GPIO_Port GPIOC
#define SWR_BACKW_Pin GPIO_PIN_1
#define SWR_BACKW_GPIO_Port GPIOC
#define FPGA_CLK_Pin GPIO_PIN_2
#define FPGA_CLK_GPIO_Port GPIOC
#define FPGA_SYNC_Pin GPIO_PIN_3
#define FPGA_SYNC_GPIO_Port GPIOC
#define FPGA_BUS_D0_Pin GPIO_PIN_0
#define FPGA_BUS_D0_GPIO_Port GPIOA
#define FPGA_BUS_D1_Pin GPIO_PIN_1
#define FPGA_BUS_D1_GPIO_Port GPIOA
#define FPGA_BUS_D2_Pin GPIO_PIN_2
#define FPGA_BUS_D2_GPIO_Port GPIOA
#define FPGA_BUS_D3_Pin GPIO_PIN_3
#define FPGA_BUS_D3_GPIO_Port GPIOA
#define FPGA_BUS_D4_Pin GPIO_PIN_4
#define FPGA_BUS_D4_GPIO_Port GPIOA
#define FPGA_BUS_D5_Pin GPIO_PIN_5
#define FPGA_BUS_D5_GPIO_Port GPIOA
#define FPGA_BUS_D6_Pin GPIO_PIN_6
#define FPGA_BUS_D6_GPIO_Port GPIOA
#define FPGA_BUS_D7_Pin GPIO_PIN_7
#define FPGA_BUS_D7_GPIO_Port GPIOA
#define AUDIO_48K_CLOCK_Pin GPIO_PIN_4
#define AUDIO_48K_CLOCK_GPIO_Port GPIOC
#define AUDIO_48K_CLOCK_EXTI_IRQn EXTI4_IRQn
#define RFUNT_THERM_Pin GPIO_PIN_5
#define RFUNT_THERM_GPIO_Port GPIOC
#define W25Q16_CS_Pin GPIO_PIN_0
#define W25Q16_CS_GPIO_Port GPIOB
#define RFUNT_ALC_Pin GPIO_PIN_1
#define RFUNT_ALC_GPIO_Port GPIOB
#define WM8731_SCK_Pin GPIO_PIN_10
#define WM8731_SCK_GPIO_Port GPIOB
#define WM8731_SDA_Pin GPIO_PIN_11
#define WM8731_SDA_GPIO_Port GPIOB
#define ENC_CLK_Pin GPIO_PIN_12
#define ENC_CLK_GPIO_Port GPIOB
#define ENC_CLK_EXTI_IRQn EXTI15_10_IRQn
#define PERI_SCK_Pin GPIO_PIN_13
#define PERI_SCK_GPIO_Port GPIOB
#define PERI_MISO_Pin GPIO_PIN_14
#define PERI_MISO_GPIO_Port GPIOB
#define PERI_MOSI_Pin GPIO_PIN_15
#define PERI_MOSI_GPIO_Port GPIOB
#define ESP_1_TX_Pin GPIO_PIN_6
#define ESP_1_TX_GPIO_Port GPIOC
#define ESP_1_RX_Pin GPIO_PIN_7
#define ESP_1_RX_GPIO_Port GPIOC
#define AD1_CS_Pin GPIO_PIN_8
#define AD1_CS_GPIO_Port GPIOC
#define ENC2SW_AND_TOUCHPAD_Pin GPIO_PIN_8
#define ENC2SW_AND_TOUCHPAD_GPIO_Port GPIOA
#define WM8731_WS_LRC_Pin GPIO_PIN_15
#define WM8731_WS_LRC_GPIO_Port GPIOA
#define WM8731_BCLK_Pin GPIO_PIN_10
#define WM8731_BCLK_GPIO_Port GPIOC
#define WM8731_ADC_SD_Pin GPIO_PIN_11
#define WM8731_ADC_SD_GPIO_Port GPIOC
#define WM8731_DAC_SD_Pin GPIO_PIN_12
#define WM8731_DAC_SD_GPIO_Port GPIOC
#define PWR_HOLD_Pin GPIO_PIN_2
#define PWR_HOLD_GPIO_Port GPIOD
#define SD_CS_Pin GPIO_PIN_3
#define SD_CS_GPIO_Port GPIOD
#define AF_AMP_MUTE_Pin GPIO_PIN_6
#define AF_AMP_MUTE_GPIO_Port GPIOD
#define RFUNIT_RCLK_Pin GPIO_PIN_4
#define RFUNIT_RCLK_GPIO_Port GPIOB
#define PTT_IN_Pin GPIO_PIN_5
#define PTT_IN_GPIO_Port GPIOB
#define PTT_IN_EXTI_IRQn EXTI9_5_IRQn
#define RFUNIT_OE_Pin GPIO_PIN_7
#define RFUNIT_OE_GPIO_Port GPIOB
#define AD3_CS_Pin GPIO_PIN_8
#define AD3_CS_GPIO_Port GPIOB
#define AD2_CS_Pin GPIO_PIN_9
#define AD2_CS_GPIO_Port GPIOB
#define KEY_IN_DASH_Pin GPIO_PIN_0
#define KEY_IN_DASH_GPIO_Port GPIOE
#define KEY_IN_DASH_EXTI_IRQn EXTI0_IRQn
#define KEY_IN_DOT_Pin GPIO_PIN_1
#define KEY_IN_DOT_GPIO_Port GPIOE
#define KEY_IN_DOT_EXTI_IRQn EXTI1_IRQn

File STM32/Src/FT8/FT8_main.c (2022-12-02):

#include "FT8_main.h"
#include "Process_DSP.h"
#include "decode_ft8.h"
#include <stdbool.h>
// #include "WF_Table.h"
#include "FT8_GUI.h"
#include "arm_math.h"
#include "locator_ft8.h"
#include "traffic_manager.h"

#include "lcd.h"
#include "lcd_driver.h"

#include "constants.h"

#define ft8_shift 6.25

int ft8_flag, FT_8_counter, ft8_marker, decode_flag, WF_counter;
int num_decoded_msg = 0;

int DSP_Flag;

uint16_t cursor_line = 100;

uint16_t FT8_DatBlockNum;
bool FT8_DecodeActiveFlg;
bool FT8_ColectDataFlg;
// bool FT8_Bussy = false;

// Function prototypes
void process_data(void);
void update_synchronization(void);

void InitFT8_Decoder(void) {
	if (LCD_busy) {
		return;
	}
	LCD_busy = true; //

	// draw the GUI
	LCDDriver_Fill(COLOR_BLACK);

	LCDDriver_printText("FT-8 Decoder", 100, 5, COLOR_GREEN, COLOR_BLACK, 2);

	strcpy(Station_Call, TRX.CALLSIGN); // set out callsign
	strcpy(Locator, TRX.LOCATOR);       // set out grid Locator

	init_DSP();
	initalize_constants();

	FT8_DatBlockNum = 0;
	FT8_DecodeActiveFlg = true;

	update_synchronization();
	set_Station_Coordinates(Locator);

	println("FT8-Initialised"); // Debug

	Unarm_FT8_Buttons(); // deactivate all buttons (if something is active and we reenter the "FT8 decode"- to start clear)
	Draw_FT8_Buttons();
	FT8_Menu_Idx = 0;         // index of the "CQ" button
	Update_FT8_Menu_Cursor(); // show the menu cursor

	int8_t band = getBandFromFreq(CurrentVFO->Freq, true);
	if (band == BANDID_80m || band == 5 || band == 7 || band == 8) { // 80m
		FT8_BND_Freq = FT8_Freq_80M;
	}
	if (band == BANDID_40m || band == 13) { // 40m
		FT8_BND_Freq = FT8_Freq_40M;
	}
	if (band == BANDID_30m || band == 14 || band == 16) { // 30m
		FT8_BND_Freq = FT8_Freq_30M;
	}
	if (band == BANDID_20m || band == 17 || band == 19) { // 20m
		FT8_BND_Freq = FT8_Freq_20M;
	}
	if (band == BANDID_17m || band == 20 || band == 22) { // 17m
		FT8_BND_Freq = FT8_Freq_17M;
	}
	if (band == BANDID_15m || band == 24) { // 15m
		FT8_BND_Freq = FT8_Freq_15M;
	}
	if (band == BANDID_12m || band == 26) { // 12m
		FT8_BND_Freq = FT8_Freq_12M;
	}
	if (band == BANDID_10m) { // 10m
		FT8_BND_Freq = FT8_Freq_10M;
	}
	if (band == BANDID_6m) { // 6m
		FT8_BND_Freq = FT8_Freq_6M;
	}
	if (band == BANDID_2m || band == BANDID_Marine) { // 2m
		FT8_BND_Freq = FT8_Freq_2M;
	}

	receive_sequence();
	cursor_freq = (uint16_t)((float)(cursor_line + ft8_min_bin) * ft8_shift);
	FT8_Print_Freq();

	Set_Data_Colection(0); // Disable the data colection
	LCD_busy = false;
}

void MenagerFT8(void) {
	char ctmp[20] = {0};

	if (decode_flag == 0) {
		process_data();
	}

	if (LCD_busy) {
		return;
	}
	LCD_busy = true;

	if (DSP_Flag == 1) {
		if (!TRX_Tune) {
			// println("process_FT8_FFT");
			process_FT8_FFT();
		}

		if (xmit_flag == 1) {
			__disable_irq(); // Disable all interrupts
			int offset_index = 5;
			// 79
			if (ft8_xmit_counter >= offset_index && ft8_xmit_counter < 79 + offset_index) {
				set_FT8_Tone(tones[ft8_xmit_counter - offset_index]);
			}

			ft8_xmit_counter++;

			// Debug
			sprintf(ctmp, "ft8_xmit_c: %d ", ft8_xmit_counter);
			LCDDriver_printText(ctmp, 10, 65, COLOR_GREEN, COLOR_BLACK, 2);

			bool send_message_done = false;
			// 80
			if (ft8_xmit_counter == 80 + offset_index) {
				send_message_done = true;
			}

			uint32_t Time = RTC->TR;
			uint8_t Seconds = ((Time >> 4) & 0x07) * 10 + ((Time >> 0) & 0x0f);
			if (ft8_xmit_counter > offset_index && (Seconds == 14 || Seconds == 29 || Seconds == 44 || Seconds == 59)) { // 15s marker
				send_message_done = true;
			}

			if (send_message_done) // send mesage is done!
			{
				// xmit_flag = 0;
				receive_sequence();

				if (Beacon_State == 8) // if we are on the end of answering a "CQ" (we just send "73")
				{
					FT8_Menu_Idx = 0;      // index of the "CQ" button
					FT8_Menu_Pos_Toggle(); // deactivate the "CQ" button -> set green
				}
			}
			__enable_irq(); // Re-enable all interrupts
		}

		DSP_Flag = 0;
	}

	else if (decode_flag == 1) {
		HAL_SuspendTick();
		__disable_irq(); // Disable all interrupts

		FT8_Clear_Mess_Field(); // Clear the recieved mesages field

		num_decoded_msg = 0;
		//			FT8_ColectDataFlg = false;		//Stop Data colection
		//			FT8_Bussy = true;							//FT8 Decode => busy
		Set_Data_Colection(0); // Disable the data colection

		num_decoded_msg = ft8_decode();

		//			for (uint32_t wait_i = 0; wait_i < 360000000; wait_i++)
//				__asm("nop");

		// Debug
		sprintf(ctmp, "Decoded: %d ", num_decoded_msg);
		LCDDriver_printText(ctmp, 10, 45, COLOR_GREEN, COLOR_BLACK, 2);

		decode_flag = 0;

		Service_FT8();

		//			FT8_Bussy = false;

		/* Enable interrupts back */
		for (int i = 0; i < 5; i++) // Clear Interrupt Pending Register
		{
			NVIC->ICPR[i] = 0xFFFFFFFF;
		}
		__enable_irq(); // Re-enable all interrupts
		HAL_ResumeTick();
	}

	update_synchronization();
	LCD_busy = false; //
}

void process_data(void) {
	if (FT8_DatBlockNum >= num_que_blocks) {
		//    for (int i = 0; i<block_size*(FT8_DatBlockNum/8); i++) {
		//			input_gulp[i] = AudioBuffer_for_FT8[i];		//coppy to FFT buffer
		//			AudioBuffer_for_FT8[i] = 0; 		//	and empty the buffer
		//		}
		FT8_DatBlockNum = 0;

		// println("Prepare new Data!");	//Debug
		for (int i = 0; i < input_gulp_size; i++) {
			dsp_buffer[i] = dsp_buffer[i + input_gulp_size];
			dsp_buffer[i + input_gulp_size] = dsp_buffer[i + 2 * input_gulp_size];
			dsp_buffer[i + 2 * input_gulp_size] = input_gulp[i];
		}
		DSP_Flag = 1;
	}
}
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

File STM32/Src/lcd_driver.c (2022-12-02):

#include "lcd_driver.h"
#include "fonts.h"
#include "functions.h"
#include "main.h"
#include "settings.h"

#if HRDW_HAS_JPEG
#include "jpeg_utils.h"
#endif

static bool _cp437 = false;
static uint16_t text_cursor_y = 0;
static uint16_t text_cursor_x = 0;
static bool wrap = false;

uint16_t LCDDriver_GetCurrentXOffset(void) { return text_cursor_x; }

void LCDDriver_SetCurrentXOffset(uint16_t x) { text_cursor_x = x; }

// Text printing functions
void LCDDriver_drawCharInMemory(uint16_t x, uint16_t y, unsigned char c, uint16_t color, uint16_t bg, uint8_t size, uint16_t *buffer, uint16_t buffer_w, uint16_t buffer_h) {
	uint8_t line = 0;
	uint8_t zoom = (size > 0 ? size : 1);
	uint8_t size_w = (size > 0 ? RASTR_FONT_W : RASTR_FONT_4x6_W);
	uint8_t size_h = (size > 0 ? RASTR_FONT_H : RASTR_FONT_4x6_H);

	if ((x >= buffer_w) ||           // Clip right
	    (y >= buffer_h) ||           // Clip bottom
	    ((x + size_w * zoom) < 0) || // Clip left
	    ((y + size_h * zoom) < 0)) { // Clip top
		return;
	}

	if ((x + size_w * zoom) >= buffer_w || (y + size_h * zoom) >= buffer_h) {
		return;
	}

	if (c < 32) { // non-printable
		return;
	}
	if (!_cp437 && (c >= 176)) {
		c++; // Handle 'classic' charset behavior
	}

	if (size > 0) {
		for (int8_t j = 0; j < size_h; j++) // y line out
		{
			for (int8_t s_y = 0; s_y < zoom; s_y++) // y size scale
			{
				uint16_t *point = buffer + buffer_w * (y + j * (s_y + 1)) + x;
				for (int8_t i = 0; i < size_w; i++) {
					// x line out
					if (i == 5) {
						line = 0x0;
					} else {
						if (size > 0) {
							line = rastr_font[(c * 5) + i]; // read font
						} else {
							line = rastr_font_4x6[(c * 5) + i]; // read font
						}
					}
					line >>= j;
					for (int8_t s_x = 0; s_x < zoom; s_x++) // x size scale
					{
						if (line & 0x1) {
							*point = color; // font pixel
						} else {
							*point = bg; // background pixel
						}
						point++;
					}
				}
			}
		}
	} else // size 0 4x6
	{
		for (int8_t j = 0; j < size_h; j++) // y line out
		{
			line = rastr_font_4x6[((c - 0x20) * 6) + j]; // read font
			uint16_t *point = buffer + buffer_w * (y + j) + x;
			for (int8_t i = 0; i < size_w; i++) {
				if (line & 0x8) {
					*point = color; // font pixel
				} else {
					*point = bg; // background pixel
				}
				point++;

				line <<= 1;
			}
		}
	}
}

void LCDDriver_printTextInMemory(char text[], int16_t x, int16_t y, uint16_t color, uint16_t bg, uint8_t size, uint16_t *buffer, uint16_t buffer_w, uint16_t buffer_h) {
	uint16_t i = 0;
	uint16_t offset = size * 6;
	uint16_t skipped = 0;
	for (i = 0; i < 128 && text[i] != 0; i++) {
		if (text[i] == '^' && text[i + 1] == 'o') // celsius
		{
			i++;
			skipped++;
			LCDDriver_drawCharInMemory(x + (offset * (i - skipped)), y - 3, text[i], color, bg, size, buffer, buffer_w, buffer_h);
		} else {
			LCDDriver_drawCharInMemory(x + (offset * (i - skipped)), y, text[i], color, bg, size, buffer, buffer_w, buffer_h);
		}
		text_cursor_x = x + (offset * (i + 1 - skipped));
	}
}

void LCDDriver_drawChar(uint16_t x, uint16_t y, unsigned char c, uint16_t color, uint16_t bg, uint8_t size) {
	uint8_t line = 0;
	uint8_t zoom = (size > 0 ? size : 1);
	uint8_t size_w = (size > 0 ? RASTR_FONT_W : RASTR_FONT_4x6_W);
	uint8_t size_h = (size > 0 ? RASTR_FONT_H : RASTR_FONT_4x6_H);

	if ((x >= LCD_WIDTH) ||              // Clip right
	    (y >= LCD_HEIGHT) ||             // Clip bottom
	    ((x + size_w * zoom - 1) < 0) || // Clip left
	    ((y + size_h * zoom - 1) < 0)) { // Clip top
		return;
	}

	if (c < 32) { // non-printable
		return;
	}
	if (!_cp437 && (c >= 176)) {
		c++; // Handle 'classic' charset behavior
	}

	LCDDriver_SetCursorAreaPosition(x, y, x + size_w * zoom - 1, y + size_h * zoom - 1); // char area
	if (size > 0) {
		for (int8_t j = 0; j < size_h; j++) // y line out
		{
			for (int8_t s_y = 0; s_y < zoom; s_y++) // y size scale
			{
				for (int8_t i = 0; i < size_w; i++) {
					// x line out
					if (i == 5) {
						line = 0x0;
					} else {
						line = rastr_font[(c * 5) + i]; // read font
					}
					line >>= j;
					for (int8_t s_x = 0; s_x < zoom; s_x++) // x size scale
					{
						if (line & 0x1) {
							LCDDriver_SendData16(color); // font pixel
						} else {
							LCDDriver_SendData16(bg); // background pixel
						}
					}
				}
			}
		}
	} else // size 0 4x6
	{
		for (int8_t j = 0; j < size_h; j++) // y line out
		{
			line = rastr_font_4x6[((c - 0x20) * 6) + j]; // read font
			for (int8_t i = 0; i < size_w; i++) {
				if (line & 0x8) {
					LCDDriver_SendData16(color); // font pixel
				} else {
					LCDDriver_SendData16(bg); // background pixel
				}

				line <<= 1;
			}
		}
	}
}

void LCDDriver_printText(char text[], uint16_t x, uint16_t y, uint16_t color, uint16_t bg, uint8_t size) {
	uint16_t i = 0;
	uint16_t offset = size * 6;
	uint16_t skipped = 0;
	for (i = 0; i < 128 && text[i] != 0; i++) {
		if (text[i] == '^' && text[i + 1] == 'o') // celsius
		{
			i++;
			skipped++;
			LCDDriver_drawChar(x + (offset * (i - skipped)), y - 3, text[i], color, bg, size);
		} else {
			LCDDriver_drawChar(x + (offset * (i - skipped)), y, text[i], color, bg, size);
		}
		text_cursor_x = x + (offset * (i + 1 - skipped));
	}
}

void LCDDriver_drawCharFont(uint16_t x, uint16_t y, unsigned char c, uint16_t color, uint16_t bg, const GFXfont *gfxFont) {
	c -= gfxFont->first;
	const GFXglyph *glyph = (GFXglyph *)&gfxFont->glyph[c];

	uint16_t bo = glyph->bitmapOffset;
	uint8_t bits = 0;
	uint8_t bit = 0;
	int16_t ys1 = y + glyph->yOffset;
	int16_t ys2 = y + glyph->yOffset + glyph->height - 1;
	if (ys1 < 0) {
		ys1 = 0;
	}
	if (ys2 < 0) {
		ys2 = 0;
	}
	LCDDriver_SetCursorAreaPosition(x, (uint16_t)ys1, x + glyph->xAdvance - 1, (uint16_t)ys2); // char area

	for (uint8_t yy = 0; yy < glyph->height; yy++) {
		for (uint8_t xx = 0; xx < glyph->xAdvance; xx++) {
			if (xx < glyph->xOffset || xx >= (glyph->xOffset + glyph->width)) {
				LCDDriver_SendData16(bg); // background pixel
				continue;
			}
			if (!(bit++ & 7)) {
				bits = gfxFont->bitmap[bo++];
			}
			if (bits & 0x80) {
				LCDDriver_SendData16(color); // font pixel
			} else {
				LCDDriver_SendData16(bg); // background pixel
			}
			bits <<= 1;
		}
	}
}
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

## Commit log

2022-06-10 fix: new layout name and color theme
    [lcd.c, system_menu.c]
2022-07-08 add: Mod-LZ1HAA-hardware into Experimental
    [ADC.SchDoc, AUDIO CODEC.SchDoc, Altera_EP4CE22E22C8N.SchLib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]
2022-07-26 add: POWER UNIT, HF PA UNIT, VHF PA UNIT and ATU UNIT self tests.
2022-07-27 add: PA-HF_100W-VHF_60W hardware project
    [PA-CONTROL.SchDoc, PA-HF_100W-VHF_60W.PrjPcb, PA-HF_100W-VHF_60W.SchDoc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]
2022-07-27 fix: Move PA-HF_100W-VHF_60W to Schematic\Wolf\Altium_Designer\Mod-LZ1HAA-hardware
    [PA-CONTROL.SchDoc, PA-HF_100W-VHF_60W.PrjPcb, PA-HF_100W-VHF_60W.SchDoc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]
2022-07-28 add: inductor to the low-pass filters relays into PA-HF_100W-VHF_60W
    [PA-CONTROL.SchDoc, PA-HF_100W-VHF_60W.SchDoc, PA-HF_100W.SchDoc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]
2022-07-29 fix: HRDW_FrontUnit2_SPI and HRDW_FrontUnit3_SPI undefined references
    [front_unit.c]
2022-08-04 fix: logging console for GCC
    [main.c]
2022-08-31 fix: add const for compilation error fixed
    [system_menu.c]
2022-09-13 add: LZ1HAA RF_BPF rev1.0.0 board support
2022-09-15 fix: band comment into LZ1HAA RF_BPF rev1.0.0 board
    [system_menu.c]
2022-09-21 fix: add "NONE" item in "RF-Unit Type" menu item and we set it as default.
    [settings.c, settings.h, system_menu.c]
2022-09-23 fix: unused parameter warning
    [system_menu.c]
2022-11-02 fix: !!! patch !!! when "INT" signal won't work from touchscreen chipset
    [events.c]
2022-11-08 fix: change host to "lz1haa.eu"
    [wifi.c]
2022-11-08 fix: make "Content-Length" condition case-insensitive
    [wifi.c]
2022-11-23 fix: PA relays footprint
    [PA-HF_100W-VHF_60W.PrjPcb, PA-HF_100W-VHF_60W.SchDoc, PA-HF_100W.SchDoc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]
2022-12-02 tmp: daily commit
    [PA-CONTROL.SchDoc, PA-HF_100W-VHF_60W.SchDoc, PA-HF_100W.SchDoc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]

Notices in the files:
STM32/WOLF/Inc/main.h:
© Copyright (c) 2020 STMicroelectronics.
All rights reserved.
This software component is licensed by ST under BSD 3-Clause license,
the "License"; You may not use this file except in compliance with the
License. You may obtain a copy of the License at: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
